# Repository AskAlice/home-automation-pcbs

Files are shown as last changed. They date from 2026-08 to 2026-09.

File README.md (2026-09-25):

# home-automation-pcbs

Open-hardware IoT boards for home automation, designed for **ESPHome** and/or
**Matter-over-Thread / Zigbee** (ESP32-C3/C6/S3/H2 based). All projects are
native **KiCad 8** and fully self-contained (project-local symbol libraries,
inline custom footprints, generator scripts — every file is reproducible).

> ⚠ **Verify before fabrication.** Footprints for ESP modules and sensors are
> drawn from published datasheets but these boards have not been through a
> physical run. v0.1 boards have signal routing left for autorouting
> (documented per-board). Check each board README before ordering PCBs.
> **RelayMini contains mains voltage — read its safety section first.**

## Boards

| Board | MCU | Ecosystem | Function | Status |
|---|---|---|---|---|
| [`boards/sensenode-c6`](boards/sensenode-c6) | ESP32-C6-WROOM-1 | ESPHome (Wi-Fi) + Matter/Thread | Temp/hum, lux, pressure, PIR | v0.1 routed (power), partial ratsnest |
| [`boards/presencepro-c3`](boards/presencepro-c3) | ESP32-C3-WROOM-02 | ESPHome | HLK-LD2410 mmWave presence + lux | v0.1 |
| [`boards/ledquad-c3`](boards/ledquad-c3) | ESP32-C3-WROOM-02 | ESPHome / WLED | 4-ch 12–24 V PWM LED driver | v0.1 |
| [`boards/relaymini-c3`](boards/relaymini-c3) | ESP32-C3-WROOM-02 | ESPHome | ⚠ Mains switch + BL0942 metering | v0.1, safety gates green |
| [`boards/ledhub-c6`](boards/ledhub-c6) | ESP32-C6-WROOM-1 | WLED / ESPHome | 2.8" TFT all-in-one LED controller | v0.1 (flagship) |
| [`boards/threadnode-h2`](boards/threadnode-h2) | ESP32-H2-MINI-1 | Matter-over-Thread / Zigbee | Battery contact sensor / button | v0.1 concept |
| [`boards/airquality-s3`](boards/airquality-s3) | ESP32-S3-WROOM-1 | ESPHome | CO₂ + VOC + temp/hum + OLED header | v0.1 concept |
| [`boards/blinddriver-c6`](boards/blinddriver-c6) | ESP32-C6-WROOM-1 | ESPHome / Matter | TMC2209 roller-blind controller | v0.1 concept |
| [`boards/irblaster-c3`](boards/irblaster-c3) | ESP32-C3-WROOM-02 | ESPHome | IR TX/RX climate bridge | v0.1 concept |
| [`boards/gardenprobe-c6`](boards/gardenprobe-c6) | ESP32-C6-WROOM-1 | ESPHome / Matter | Battery soil-moisture probe | v0.1 concept |
| [`boards/threadrcp-h2`](boards/threadrcp-h2) | ESP32-H2-MINI-1 | OpenThread RCP / Zigbee NCP | Border-router USB dongle | v0.1 concept |
| [`boards/garagepilot-c6`](boards/garagepilot-c6) | ESP32-C6-WROOM-1 | ESPHome | Garage-door relay + 3× inputs | v0.1 routed, DRC/ERC issues |

Each board folder contains: `*.kicad_pro/.kicad_sch/.kicad_pcb`, project-local
symbol library, `bom_lcsc.csv` (real, in-stock LCSC part numbers), `README.md`
(BOM, pinout, flashing, analyzer notes), `esphome/*.yaml`, render PNGs, and the
generator script (`gen_*.py`).

## Board showcase

### 🌡️ [SenseNode C6](boards/sensenode-c6) — environmental multisensor

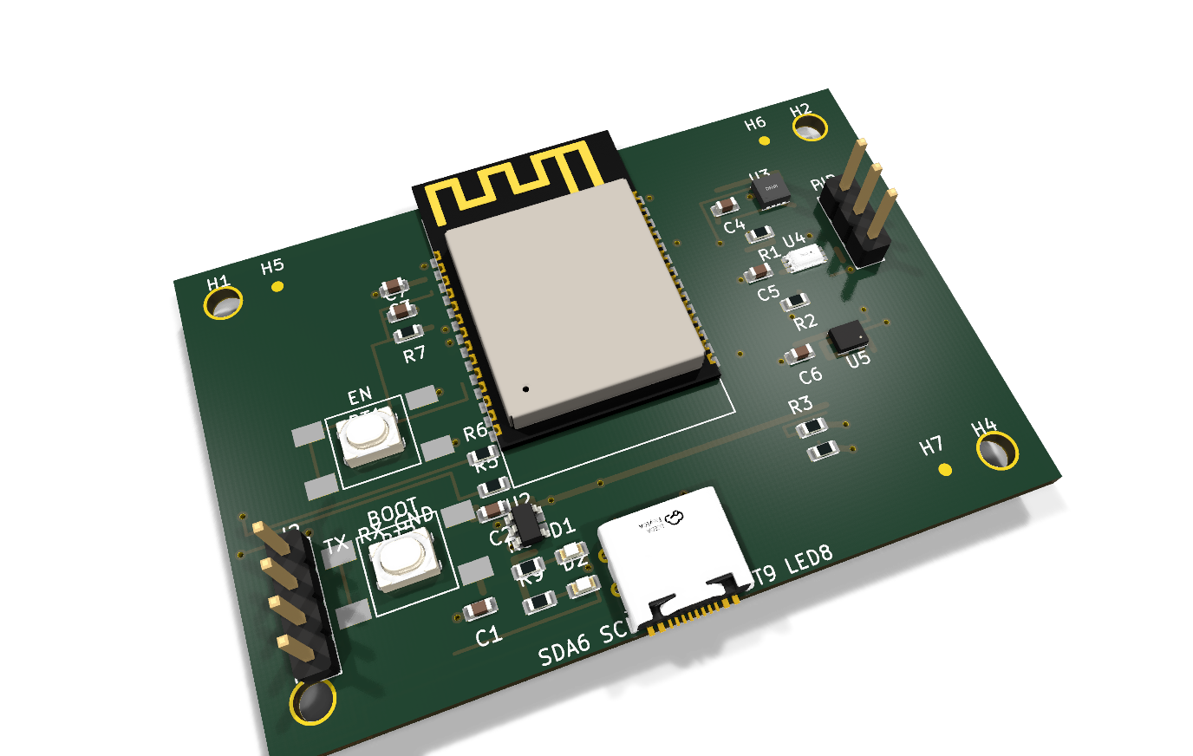
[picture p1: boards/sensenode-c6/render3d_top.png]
SenseNode C6


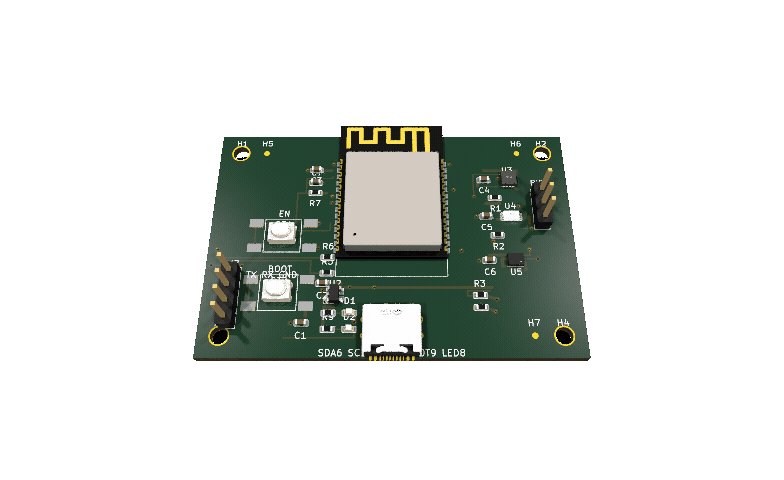
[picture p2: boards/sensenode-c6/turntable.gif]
sensenode-c6 360° turntable


One-per-room environmental node. ESP32-C6 gives you Wi-Fi 6 + BLE5 **and**
802.15.4, so the same SKU can run ESPHome today and Matter-over-Thread tomorrow.

- **Sensors:** SHT31 (temp/hum), BH1750 (lux), BMP280 (pressure), AM312 PIR (motion)
- **Power:** USB-C 5 V → AP2112K-3.3 LDO; EN/BOOT buttons; 1×4 prog header
- **Key parts:** ESP32-C6-WROOM-1, SHT31-AD1B, BH1750FVI, BMP280, AP2112K-3.3, USB-C 16P
- **Firmware:** `boards/sensenode-c6/esphome/sensenode-c6.yaml` (+ esp-matter note)

| Function | ESP32-C6 GPIO |
|---|---|
| I2C SDA / SCL (SHT31 + BH1750 + BMP280) | 6 / 7 |
| PIR OUT (J1) | 4 |
| Status LED (active low) | 8 |
| BOOT button | 9 |
| USB D− / D+ | 12 / 13 |
| UART0 TX0 / RX0 (prog header) | 16 / 17 |
| EN reset | EN |

---

### 🚶 [PresencePro C3](boards/presencepro-c3) — mmWave presence + lux

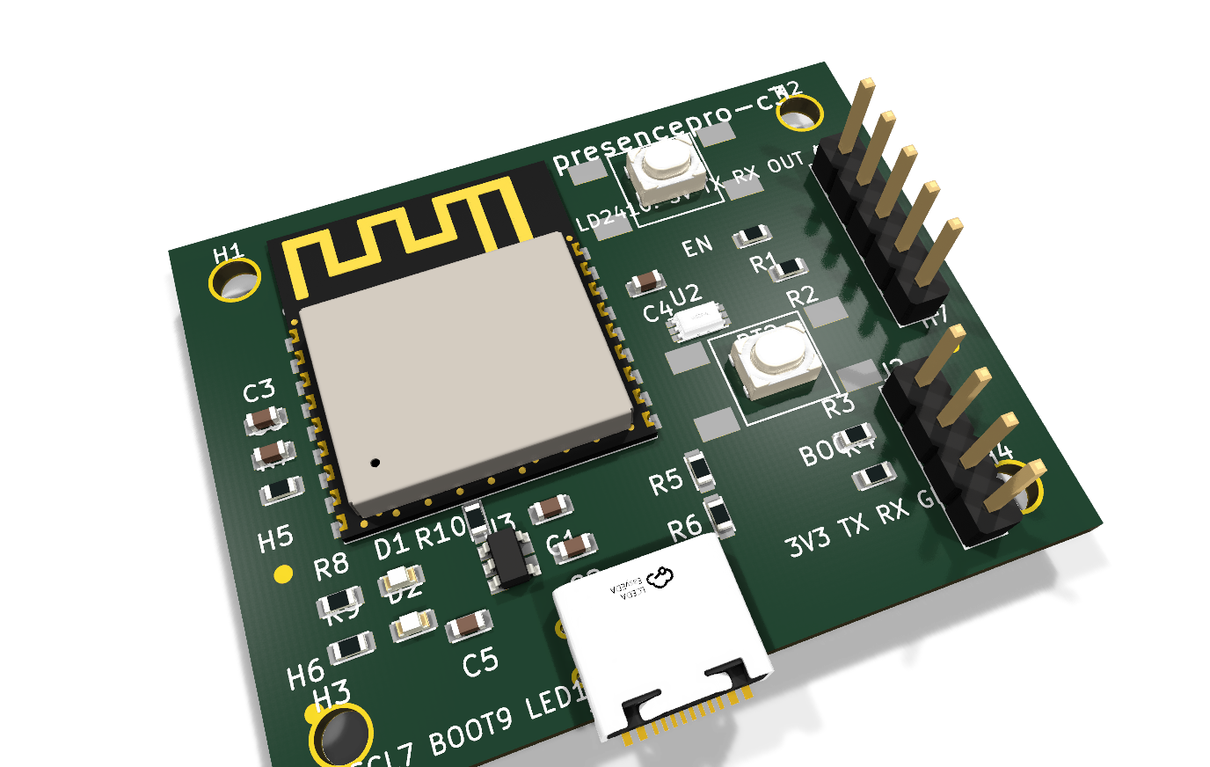
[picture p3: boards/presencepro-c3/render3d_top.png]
PresencePro C3


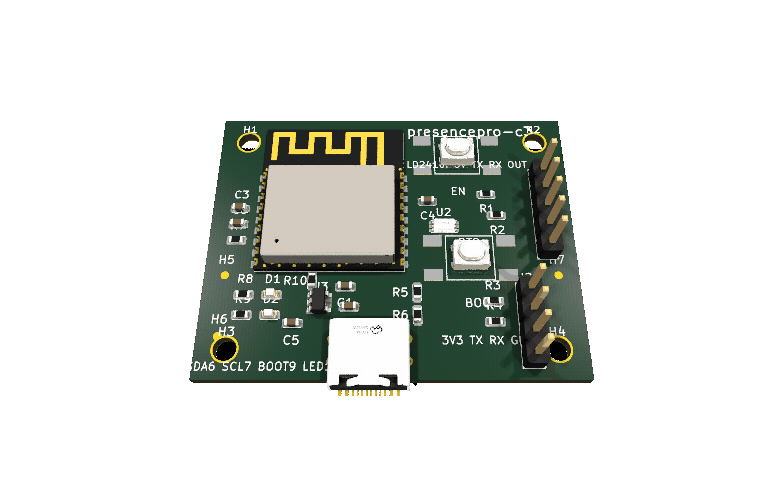
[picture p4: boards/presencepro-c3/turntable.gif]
presencepro-c3 360° turntable


True still-presence detection (sitting at a desk, sleeping) where PIR fails,
with lux gating so automations only fire when it's dark.

- **Sensors:** HLK-LD2410(B) 24 GHz mmWave (moving + static targets, configurable
  gates), BH1750 ambient light
- **Power:** USB-C 5 V → AP2112K-3.3; native USB flashing
- **Key parts:** ESP32-C3-WROOM-02, HLK-LD2410B (module on 1×5 header), BH1750FVI, AP2112K
- **Firmware:** `esphome/presencepro-c3.yaml` (native `ld2410` component)

| Function | ESP32-C3 GPIO |
|---|---|
| Radar UART RX / TX | 4 / 5 |
| Radar OUT (occupancy) | 3 |
| I2C SDA / SCL (BH1750) | 6 / 7 |
| USB D− / D+ | 18 / 19 |
| Status LED | 10 |
| BOOT / EN | 9 / EN |
| UART0 RX0 / TX0 (prog) | 20 / 21 |

---

### 💡 [LEDQuad C3](boards/ledquad-c3) — 4-ch 12–24 V PWM LED driver

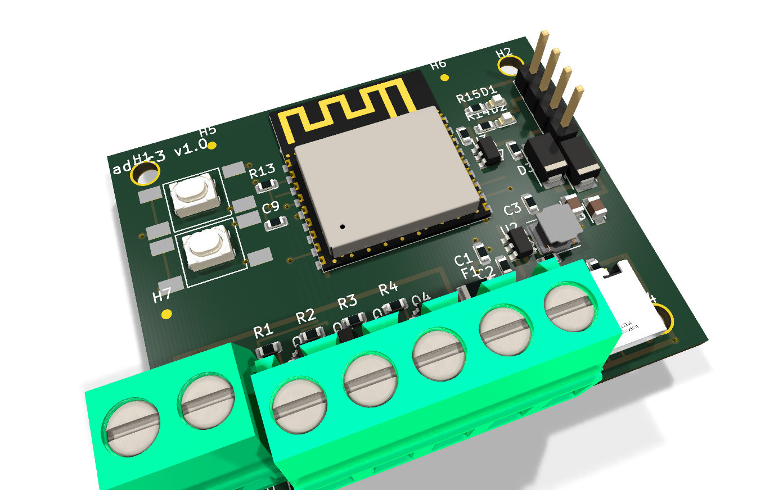
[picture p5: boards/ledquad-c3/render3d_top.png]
LEDQuad C3


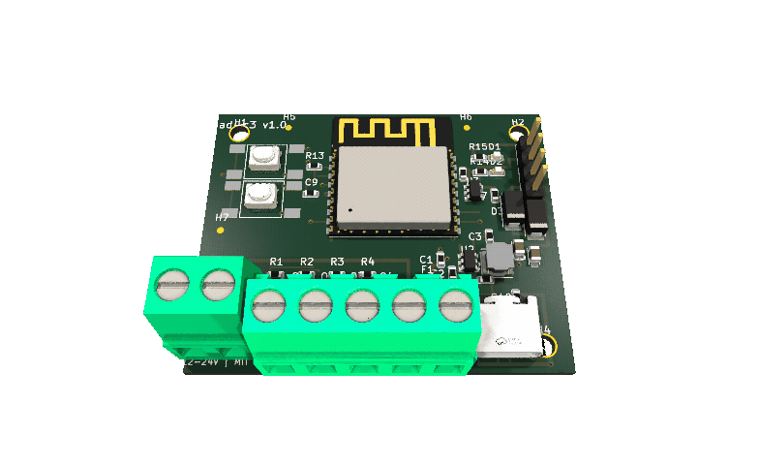
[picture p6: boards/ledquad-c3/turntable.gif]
ledquad-c3 360° turntable


Analog RGBW strip driver for 12/24 V strips — the classic ESPHome `light.rgbw`
board, sized to hide behind furniture.

- **Outputs:** 4× AO3400A N-MOSFET low-side channels on 5.08 mm screw terminals
- **Power:** 12–24 V in (fused) → AP63205 buck 5 V/2 A → AP2112 3.3 V; USB-C
  programming diode-OR'd with the buck rail
- **Key parts:** ESP32-C3-WROOM-02, AP63205, AP2112K-3.3, 4× AO3400A, SS34, USB-C 16P
- **Firmware:** `esphome/ledquad-c3.yaml` (also WLED-friendly)

| Function | ESP32-C3 GPIO |
|---|---|
| PWM R / G / B / W | 4 / 5 / 6 / 7 |
| Status LED | 10 |
| BOOT button | 9 |
| USB D− / D+ | 18 / 19 |
| UART0 TX0 / RX0 | 21 / 20 |
| EN reset | EN |

---

### 🔌 [RelayMini C3](boards/relaymini-c3) — mains switch + energy metering

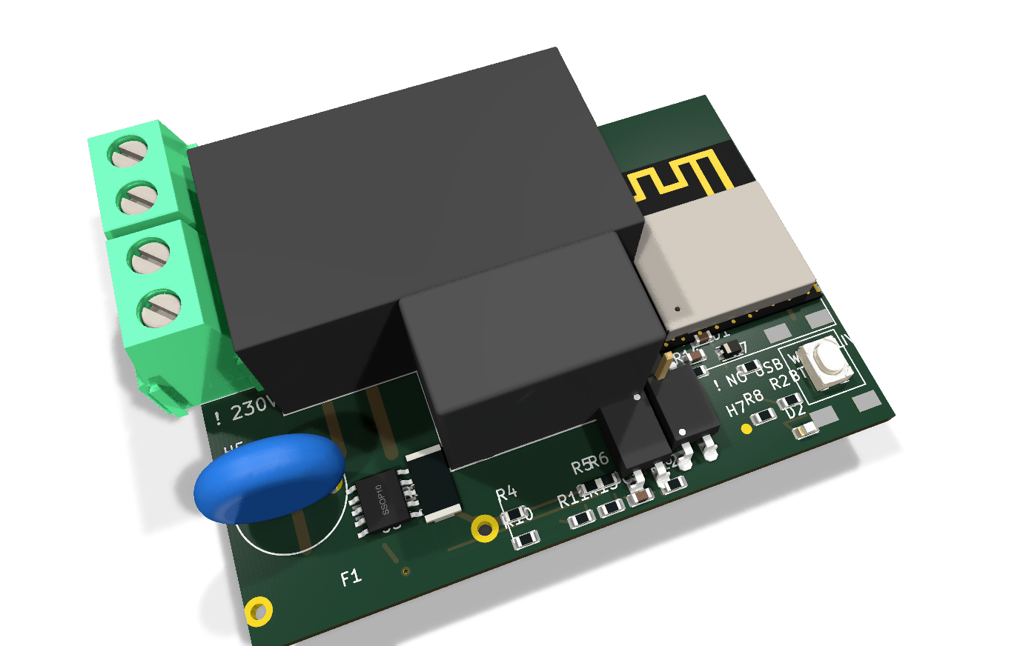
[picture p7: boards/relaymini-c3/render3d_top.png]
RelayMini C3


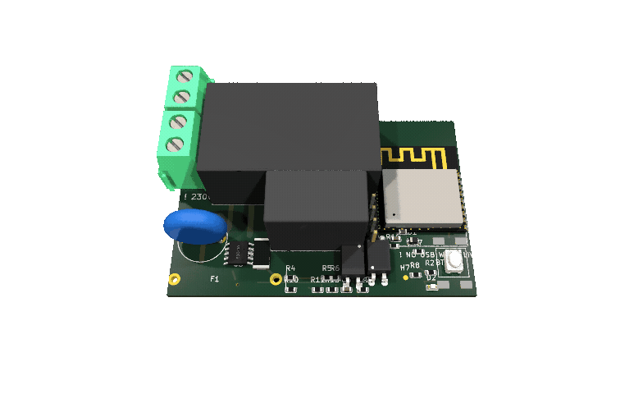
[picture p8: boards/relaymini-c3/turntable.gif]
relaymini-c3 360° turntable


> ⚠ **110–240 VAC mains board. Lethal voltages. Qualified builders only —
> read the safety section in its README before anything else.**

Sonoff-Basic-class inline switch, but with proper engineering: fused input,
isolation slot, opto-isolated metering, and a SELV-side programming header.

- **Switching:** HF32F-G relay 10 A/250 VAC, 10 A fuse, MOV, creepage ≥ 6 mm,
  milled isolation slot between mains and SELV domains
- **Metering:** BL0942 (V/A/W/Wh/PF) with PC817 opto-isolated UART
- **Key parts:** ESP32-C3-WROOM-02, HLK-PM01 AC/DC, HF32F-G, BL0942, PC817 ×2
- **Firmware:** `esphome/relaymini-c3.yaml` (`bl0942` component)

| Function | GPIO |
|---|---|
| Relay driver (→ K1 coil) | GPIO6 |
| BL0942 UART RX / TX | GPIO4 / GPIO5 |
| User button (active low) | GPIO9 |
| Status LED (active low) | GPIO8 |
| Prog header (SELV side only!) TX0/RX0 | GPIO21 / GPIO20 |

---

### 🕹️ [LEDHub C6](boards/ledhub-c6) — all-in-one display LED controller (flagship)

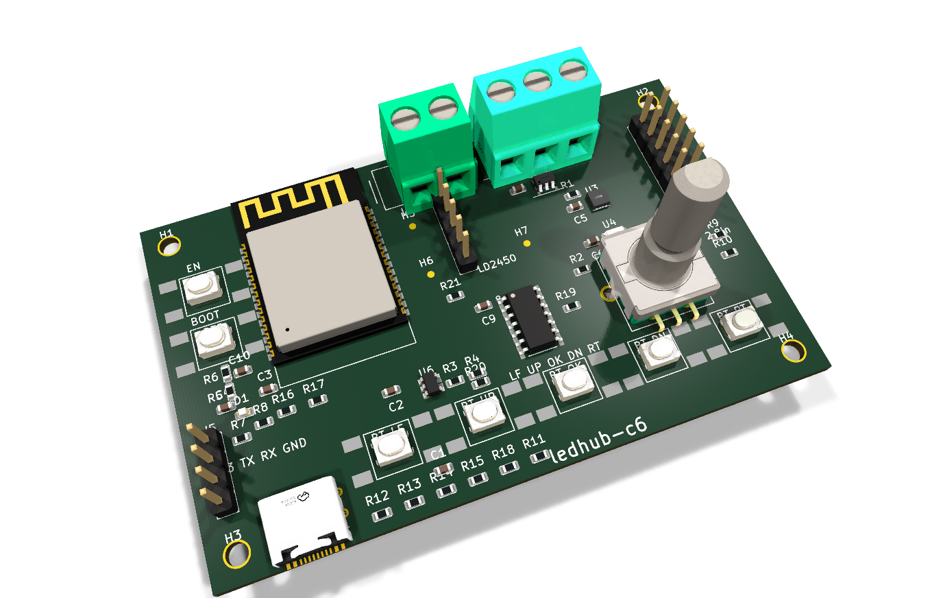
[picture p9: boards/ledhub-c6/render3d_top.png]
LEDHub C6


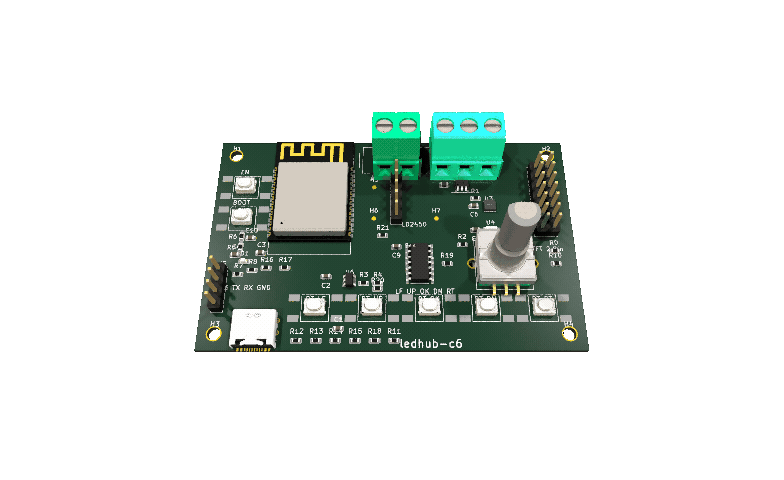
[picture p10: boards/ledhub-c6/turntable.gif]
ledhub-c6 360° turntable


A complete addressable-LED control station: status display, physical controls,
presence-aware switching and environmental telemetry, running **WLED** with a
custom usermod (`firmware/wled-usermod-ledhub`).

- **Display/UI:** 2.8" ILI9341 TFT (effect, palette, brightness, IP, RSSI),
  EC11 rotary encoder, 5-way nav buttons on one ADC pin (resistor ladder)
- **Sensors:** SHT31 + BH1750 (I2C), INMP441 I2S mic, LD2450 mmWave radar header
- **Output:** WS2812 data via 74AHCT125 level shifter + 470 Ω; separate 5 V LED
  power terminal
- **Key parts:** ESP32-C6-WROOM-1, 74AHCT125, INMP441, SHT31, BH1750, EC11, AP2112K
- **Firmware:** WLED usermod + `esphome/ledhub-c6.yaml`

| Function | ESP32-C6 GPIO |
|---|---|
| TFT SCK / MOSI / CS / DC / RST / BL | 6 / 7 / 5 / 4 / 1 / 2 |
| Encoder A / B | 15 / 16 |
| Nav button ladder (ADC) | 0 |
| INMP441 I2S SCK / WS / SD | 17 / 18 / 19 |
| I2C SDA / SCL | 20 / 21 |
| LD2450 radar RX / TX | 22 / 23 |
| WS2812 data (→ 74AHCT125) | 3 |
| USB D− / D+ | 12 / 13 |

---

### 🚪 [ThreadNode H2](boards/threadnode-h2) — battery Thread contact/button node

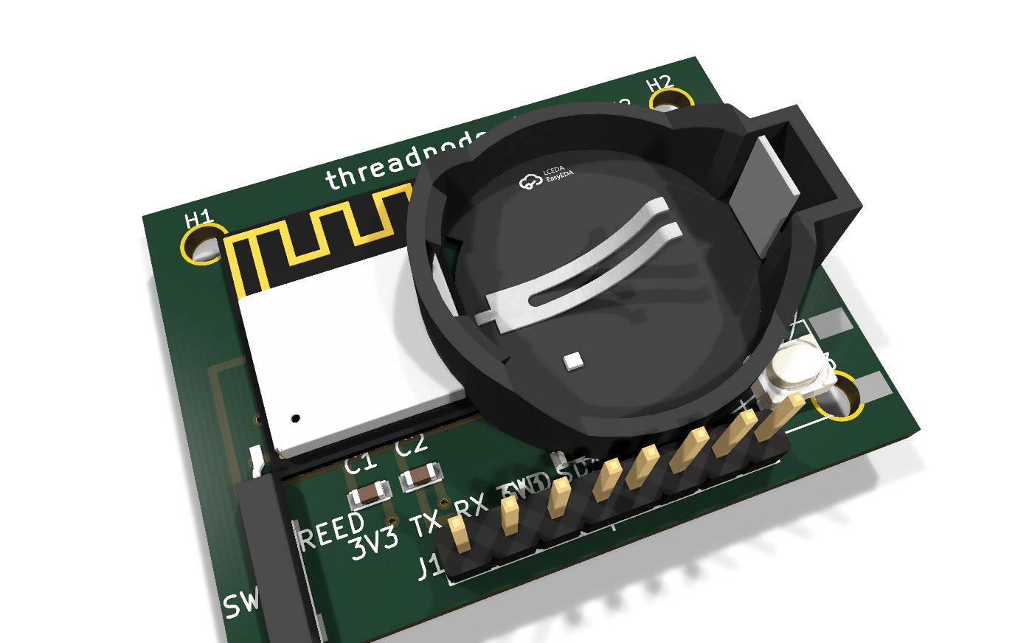
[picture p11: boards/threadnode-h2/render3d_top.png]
ThreadNode H2


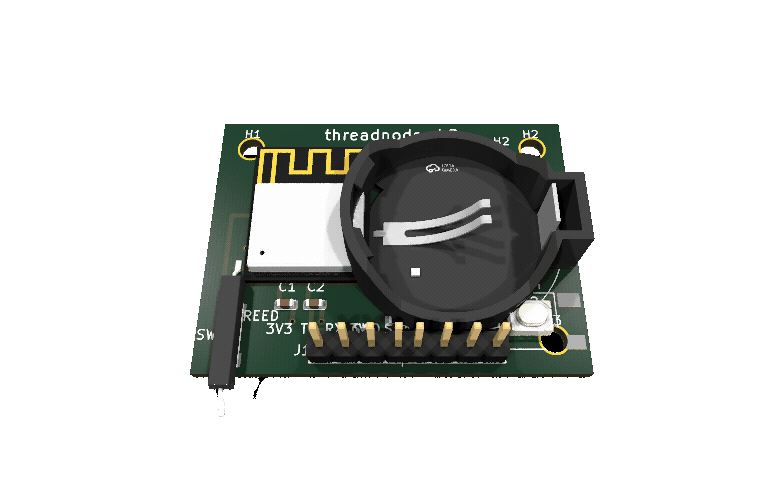
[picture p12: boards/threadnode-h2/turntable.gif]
threadnode-h2 360° turntable


ESP32-H2 = 802.15.4 only, built for deep sleep: a CR2032 door/window sensor or
smart button on a Matter-over-Thread or Zigbee network.

- **Power:** CR2032 direct (no LDO — brown-out note in README); reed-switch
  deep-sleep wakeup
- **Key parts:** ESP32-H2-MINI-1, CR2032 holder, reed/header input, 4.7k I2C pull-ups
- **Firmware:** Matter-over-Thread via esp-matter (note in README)

| Signal | GPIO | Notes |
|---|---|---|
| REED | GPIO3 | reed switch to GND, deep-sleep wakeup |
| I2C SDA / SCL | GPIO12 / GPIO13 | expansion header |
| STAT LED | GPIO8 | pulse only — battery |
| BTN (BOOT) | GPIO9 | user button / ROM bootloader |
| TX0 / RX0 | GPIO24 / GPIO23 | prog header (no USB) |

---

### 🌫️ [AirQuality S3](boards/airquality-s3) — CO₂ / VOC / temp / humidity

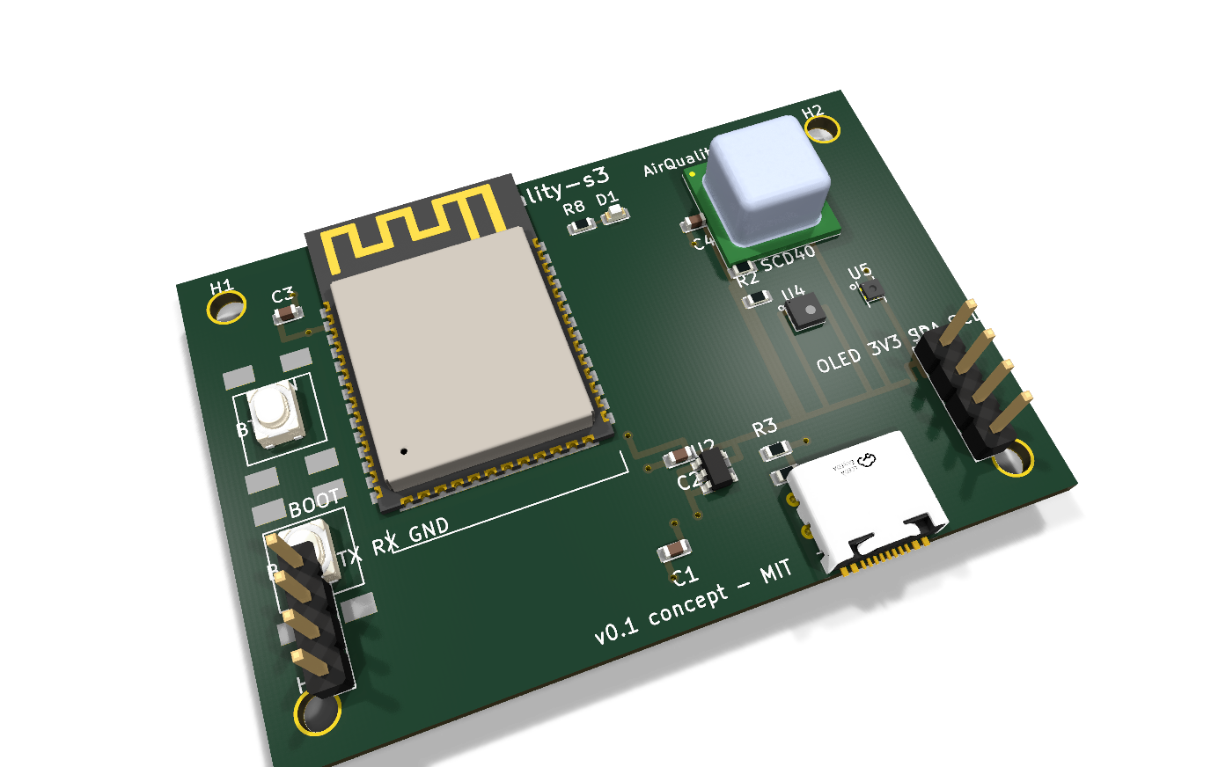
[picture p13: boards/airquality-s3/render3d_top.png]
AirQuality S3


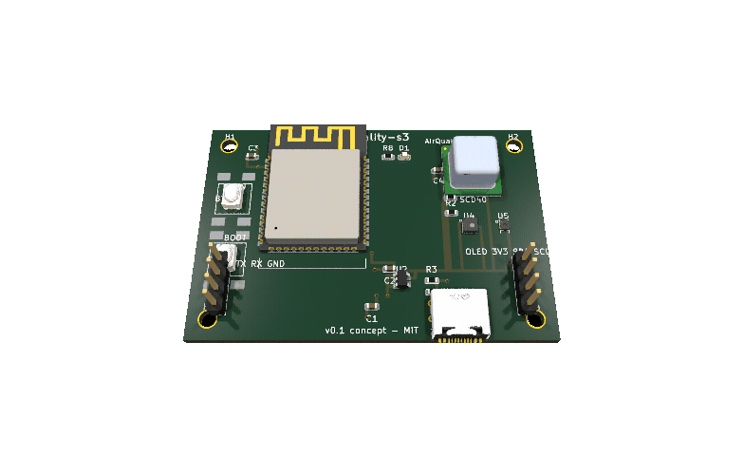
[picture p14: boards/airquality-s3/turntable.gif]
airquality-s3 360° turntable


Full indoor-air-quality node with photoacoustic CO₂ and metal-oxide VOC on one
I2C bus, plus a header for a 0.96" SSD1306 OLED readout.

- **Sensors:** Sensirion SCD40 (CO₂), SGP40 (VOC index), SHT40 (temp/hum)
- **Key parts:** ESP32-S3-WROOM-1, SCD40, SGP40, SHT40, AP2112K-3.3, USB-C
- **Firmware:** `esphome/airquality-s3.yaml` (`scd4x`, `sgp40`, `sht4x`)

| Signal | GPIO | Notes |
|---|---|---|
| I2C SDA / SCL | GPIO8 / GPIO9 | SCD40 0x62, SGP40 0x59, SHT40 0x44, OLED 0x3C |
| BOOT / RST | GPIO0 / EN | |
| STAT LED | GPIO38 | |
| USB D− / D+ | GPIO19 / GPIO20 | native USB flashing |
| TX0 / RX0 | GPIO43 / GPIO44 | spare UART |

---

### 🪟 [BlindDriver C6](boards/blinddriver-c6) — TMC2209 roller-blind controller

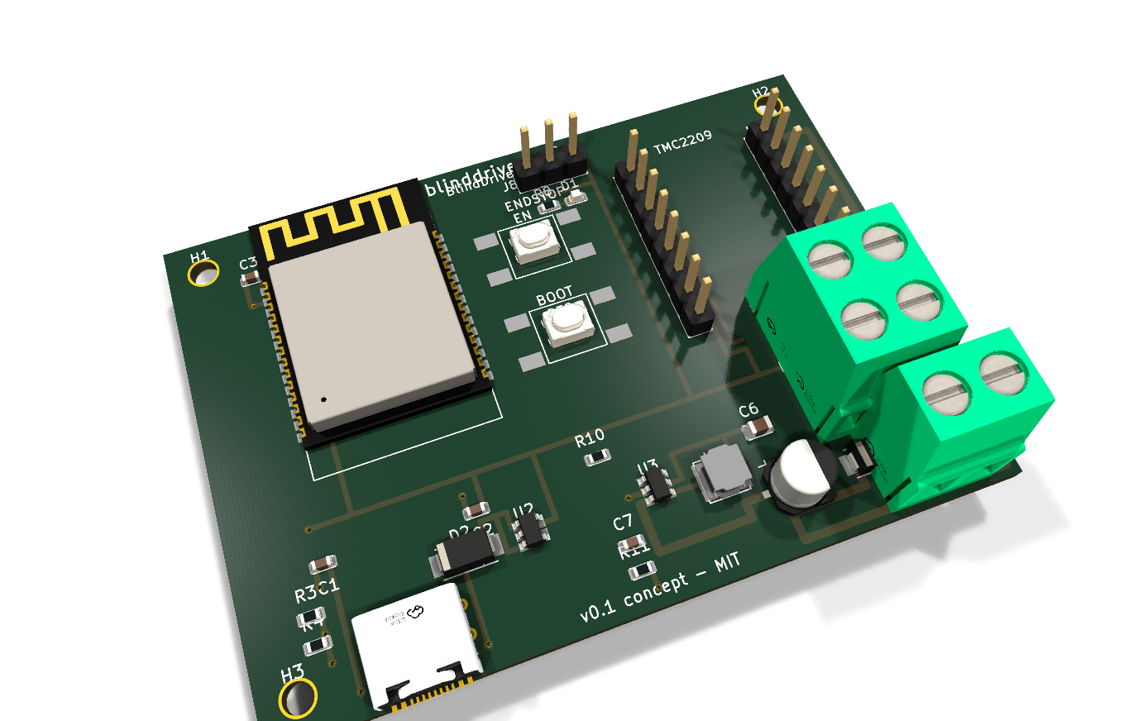
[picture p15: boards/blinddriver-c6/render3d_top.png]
BlindDriver C6


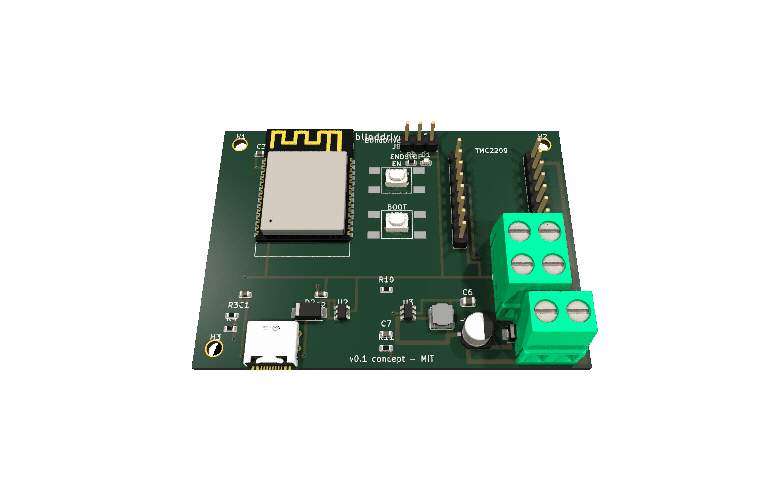
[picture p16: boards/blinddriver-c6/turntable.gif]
blinddriver-c6 360° turntable


Quiet Trinamic stepper control for roller blinds, with ESPHome `cover`
semantics and Wi-Fi 6 + Thread on tap.

- **Driver:** TMC2209 socket (STEP/DIR/EN/DIAG + 1-wire UART config),
  end-stop header, 12 V VMOT with SS34 reverse-polarity protection
- **Power chain:** 12 V → AP63205 5 V → AP2112 3.3 V
- **Key parts:** ESP32-C6-WROOM-1, TMC2209, AP63205, screw terminals
- **Firmware:** `esphome/blinddriver-c6.yaml` (stepper cover)

| Signal | GPIO | Notes |
|---|---|---|
| STEP / DIR | GPIO4 / GPIO5 | TMC2209 socket |
| TMC_EN / DIAG | GPIO6 / GPIO7 | |
| TMC_UART | GPIO15 | 1-wire PDN_UART config |
| ENDSTOP | GPIO18 | header, pull-up |
| USB D− / D+ | GPIO12 / GPIO13 | |

---

### 📡 [IRBlaster C3](boards/irblaster-c3) — IR climate bridge

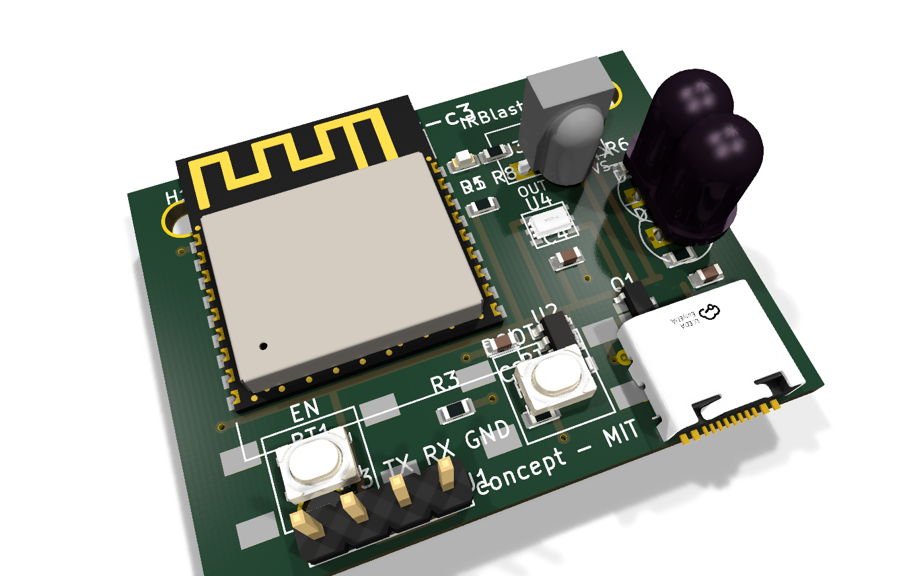
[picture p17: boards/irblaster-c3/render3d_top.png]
IRBlaster C3


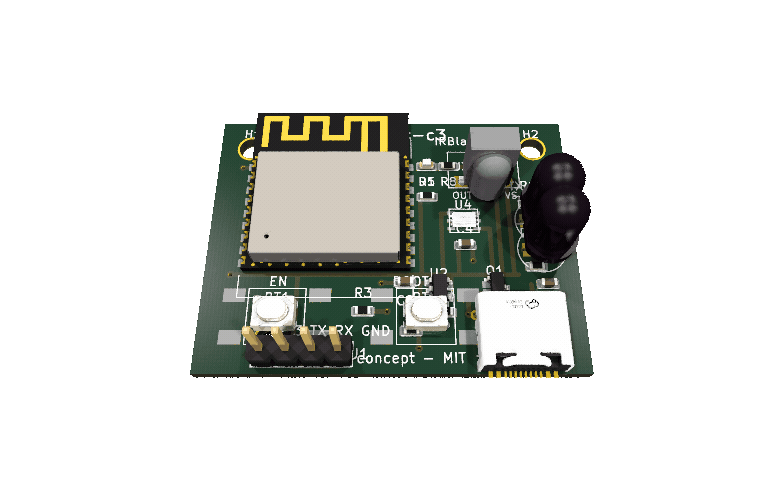
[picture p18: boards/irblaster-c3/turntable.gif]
irblaster-c3 360° turntable


Give any dumb IR AC/heater a brain: ESPHome `climate_ir` with transmit and
receive (learn your remote's codes).

- **TX:** 2× TSAL6200 high-power IR LEDs driven by S8050 (GPIO4)
- **RX:** TSOP38238 38 kHz receiver (GPIO5); optional BH1750 lux on I2C
- **Key parts:** ESP32-C3-WROOM-02, TSAL6200 ×2, TSOP38238, S8050, BH1750
- **Firmware:** `esphome/irblaster-c3.yaml` (`remote_transmitter`/`remote_receiver`)

| Signal | GPIO | Notes |
|---|---|---|
| IR_TX | GPIO4 | → S8050 → 2× TSAL6200 |
| IR_RX | GPIO5 | TSOP38238 out |
| I2C SDA / SCL | GPIO6 / GPIO7 | BH1750 0x23 |
| STAT LED / BOOT | GPIO10 / GPIO9 | |
| USB D− / D+ | GPIO18 / GPIO19 | |

---

### 🌱 [GardenProbe C6](boards/gardenprobe-c6) — battery soil-moisture stick

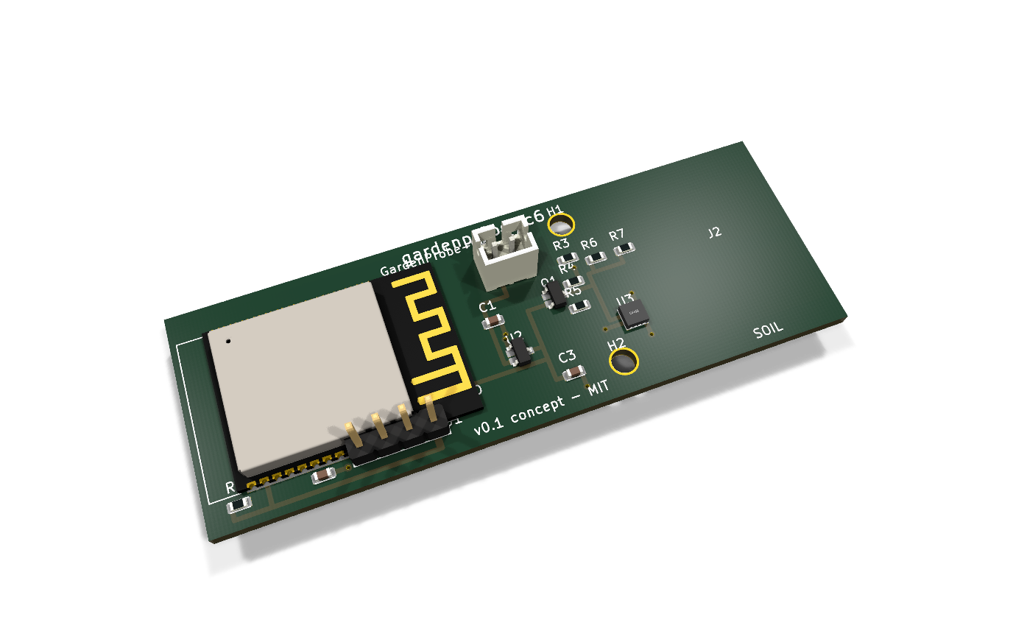
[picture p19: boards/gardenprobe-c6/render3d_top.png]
GardenProbe C6


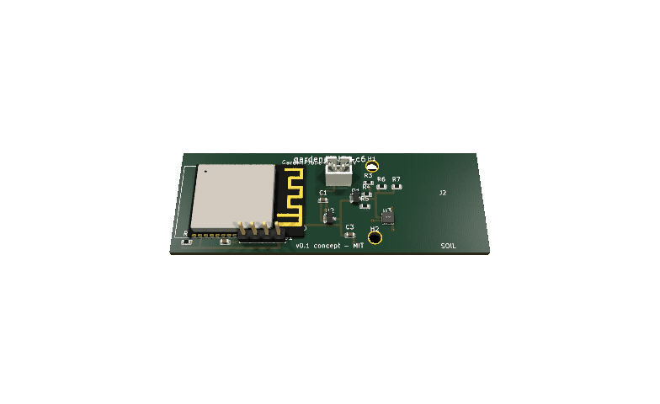
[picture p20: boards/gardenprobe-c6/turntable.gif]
gardenprobe-c6 360° turntable


Plant sensor built as a 70 × 25 mm stick: the probe is the PCB — a capacitive
copper area on the bottom tip, corrosion-free versus resistive probes.

- **Sensing:** capacitive fixed-RC probe (GPIO0/1), SHT31 on a load-switched
  rail (AO3401) to save battery, 100k/100k battery divider
- **Power:** 3.7 V LiPo on JST-PH, MCP1700-3302 LDO (charge externally)
- **Key parts:** ESP32-C6-WROOM-1, MCP1700, AO3401, SHT31
- **Firmware:** `esphome/gardenprobe-c6.yaml` (deep sleep)

| Signal | GPIO | Notes |
|---|---|---|
| SOIL_ADC / SOIL_CHG | GPIO0 / GPIO1 | capacitive probe |
| BATT_ADC | GPIO2 | Vbat/2 divider |
| LOAD_EN | GPIO3 | sensor rail load switch |
| I2C SDA / SCL | GPIO20 / GPIO21 | SHT31 0x44 |
| TX0 / RX0 | GPIO16 / GPIO17 | prog header (no USB) |

---

### 🧵 [ThreadRCP H2](boards/threadrcp-h2) — OpenThread border-router dongle

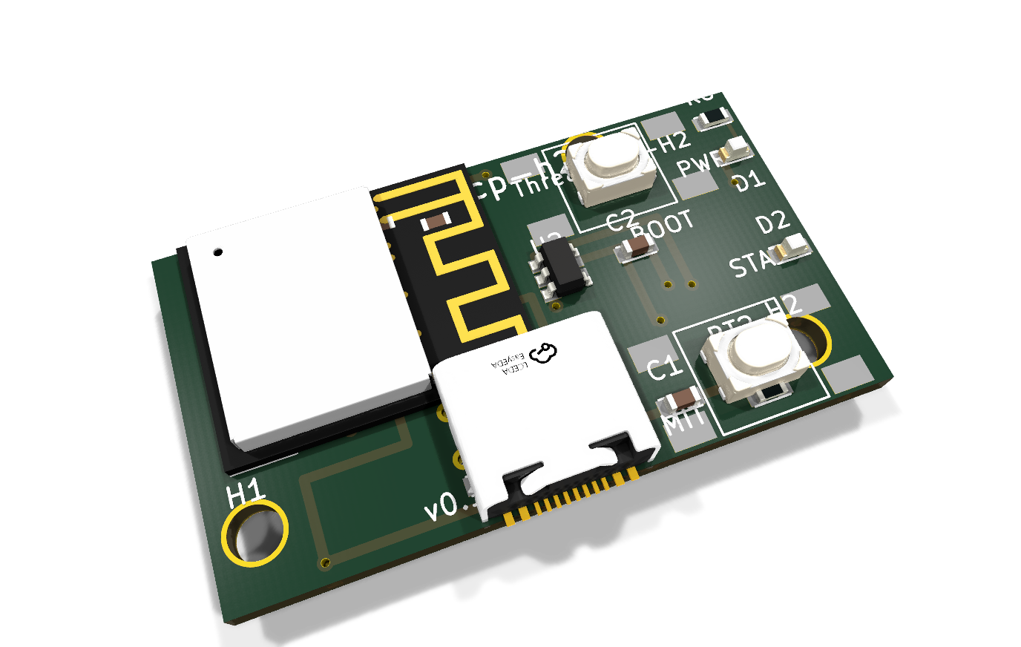
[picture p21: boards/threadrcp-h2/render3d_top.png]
ThreadRCP H2


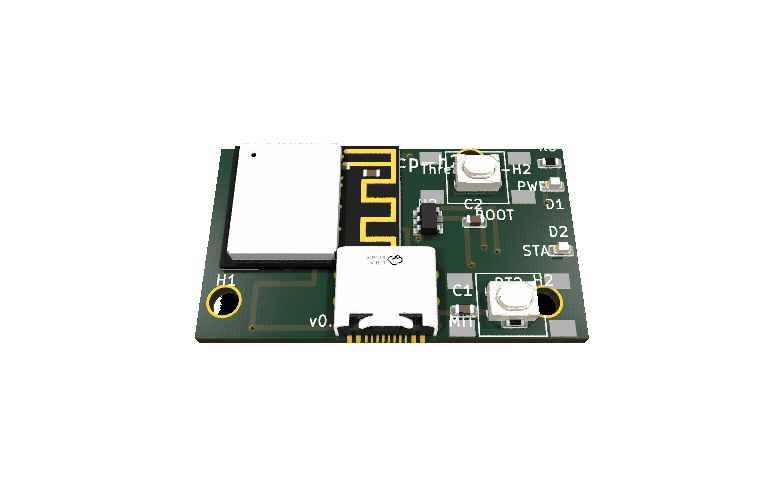
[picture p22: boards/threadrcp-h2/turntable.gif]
threadrcp-h2 360° turntable


35 × 20 mm USB-C dongle that turns a Home Assistant box into an OpenThread
Border Router — the missing piece for all the H2/C6 Thread boards above.

- **Function:** ESP32-H2 RCP firmware (`esp_ot_br` / ot-rcp), native USB
  transport (GPIO26/27) — no UART bridge chip
- **Layout:** module rotated so the antenna overhangs the board edge
  (metal-free keep-out marked on silk)
- **Key parts:** ESP32-H2-MINI-1, USB-C 16P, AP2112K-3.3
- **Firmware:** Espressif ot_rcp example (flash command in README)

| Signal | GPIO | Notes |
|---|---|---|
| USB D− / D+ | GPIO26 / GPIO27 | RCP transport |
| STAT LED | GPIO8 | |
| BOOT / RST | GPIO9 / EN | |
| TX0 / RX0 | GPIO24 / GPIO23 | spare pads only |

### 🚗 [GaragePilot C6](boards/garagepilot-c6) — garage-door relay + 3× inputs

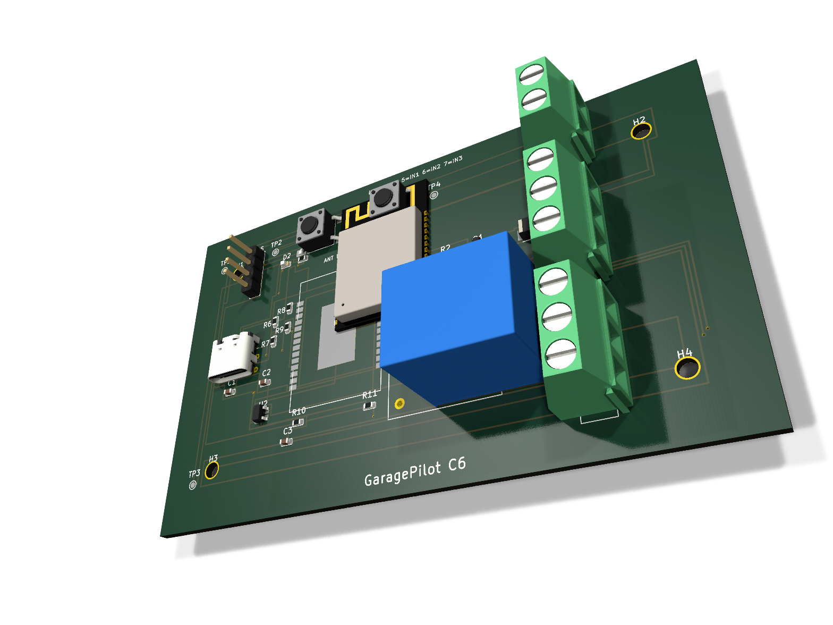
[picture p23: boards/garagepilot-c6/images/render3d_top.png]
GaragePilot C6


Dry-contact garage-door controller: ESP32-C6 closes a low-voltage relay across the opener's
wall-button terminals and reads door-closed / door-open reed switches plus a safety beam.
Powered from USB-C or a 5 V screw terminal.

- **Relay:** SRD-05VDC-SL-C SPDT dry contact (COM/NC/NO) via AO3400A MOSFET
- **Inputs:** 3× active-low digital inputs with 10 kΩ pull-ups for reed / safety sensors
- **Power:** USB-C 16P → AP2112K-3.3 LDO; auxiliary 5 V terminal
- **Key parts:** ESP32-C6-WROOM-1-N8, AP2112K-3.3, AO3400A, SRD-05VDC-SL-C, SS34 flyback
- **Firmware:** `boards/garagepilot-c6/esphome/garagepilot-c6.yaml` (`cover` template)

> ⚠ **v0.1 status:** routed and rendered, but KiCad DRC reports 96 violations / 23 unconnected
> items and ERC could not be run from the CLI.  See the board README before ordering PCBs.

| Function | ESP32-C6 GPIO |
|---|---|---|
| Relay driver | 4 |
| Door-closed / door-open / safety beam inputs | 5 / 6 / 7 |
| Status LED | 8 |
| BOOT / RESET buttons | 9 / EN |
| UART0 TX0 / RX0 (prog header) | 16 / 17 |

---

## Firmware

- `boards/*/esphome/*.yaml` — ready-to-adapt ESPHome configs.
- [`firmware/wled-usermod-ledhub`](firmware/wled-usermod-ledhub) — WLED usermod
  for LEDHub: ILI9341 status display, rotary encoder brightness, ADC-ladder
  nav buttons, LD2450 presence switching, SHT31/BH1750 telemetry.

## Part data

- [`datasheets/`](datasheets) — datasheet PDFs for all ICs/modules/connectors
  + `manifest.json` (re-sync: `python3 tools/fetch_datasheets.py`).
- [`3dmodels/`](3dmodels) — STEP + WRL models (KiCad packages3D, Espressif
  kicad-libraries, EasyEDA/LCSC) referenced from every PCB
  (`${KIPRJMOD}/../../3dmodels/…`) + `manifest.json` (the resolved model and
  transform per footprint; re-fetch + re-attach: `python3 tools/attach_3d.py`).

> **Note:** datasheet PDFs and STEP/WRL models are not committed to git — they
> are regenerable with `tools/fetch_datasheets.py` and `tools/attach_3d.py`.
> The render PNGs/GIFs in each board folder *are* committed so the READMEs
> display without any tooling.

## Tools

- `tools/kicadgen.py` — KiCad 8 s-expression writer + project validator used
  by every board generator (`python3 boards/<b>/gen_<b>.py` regenerates).
- `tools/render_pcb.py` — dependency-free PCB rasterizer (the render PNGs in
  each board folder).
- `tools/attach_3d.py` — fetches every footprint's 3D model (declarative
  footprint → source table) and rebuilds the `(model …)` blocks in all boards,
  aligning each body to the repo's custom footprint by pad bounding box.
  Needs `easyeda2kicad` (pip) for the LCSC parts.
- `tools/render3d.sh` — raytraced 3D renders (`render3d_top/bottom.png` per
  board) via `kicad-cli pcb render --quality high` (KiCad ≥ 9.0, 10.0.5
  known-good — CPU raytracer, no X server needed).
- `tools/turntable.sh` — 24-frame 360° orbit (`turntable.gif` per board) from
  the same raytracer, stitched with ffmpeg.

## Design rules

2-layer, 1.6 mm, 0.2 mm clearance, 0.25 mm min track, ≥0.5 mm power tracks,
GND pour on B.Cu, antenna keepouts on all RF modules. Every board passes
[kicad-happy](https://github.com/aklofas/kicad-happy) schematic/PCB analysis
with zero cross-net violations (DFM-001 = 0); remaining warnings are triaged
in each board's README.

## Acknowledgements

Validation and datasheet tooling: [kicad-happy](https://github.com/aklofas/kicad-happy)
(MIT, © 2025 Andrew Klofas). 3D models: EasyEDA/LCSC and the KiCad official
packages3D libraries. ESP module footprints verified against
[espressif/kicad-libraries](https://github.com/espressif/kicad-libraries).

## License

MIT — see [LICENSE](LICENSE).

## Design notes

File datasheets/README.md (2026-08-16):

# datasheets/

Datasheet PDFs for all non-passive parts across boards/*/bom_lcsc.csv.
Passives (R/C/LED 0603/0805) are intentionally skipped.
Files: `<LCSC>_<MPN>.pdf`. See `manifest.json` for source URL and status per part.

Fetched: 39/79. Failures/unavailable are marked in the manifest (LCSC '-' rows have no LCSC listing; fetch the manufacturer PDF manually if needed).

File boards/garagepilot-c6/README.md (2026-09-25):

# GaragePilot C6 — ESP32-C6 garage-door controller

GaragePilot C6 front isometric render

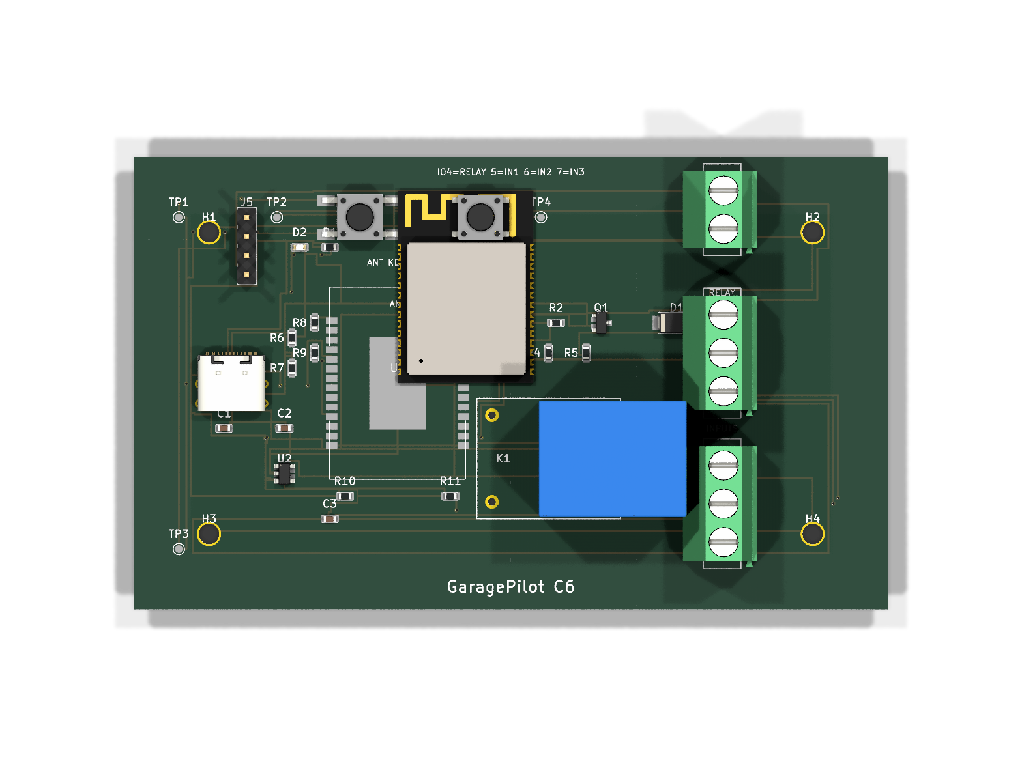
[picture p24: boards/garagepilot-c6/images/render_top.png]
GaragePilot C6 top PCB render


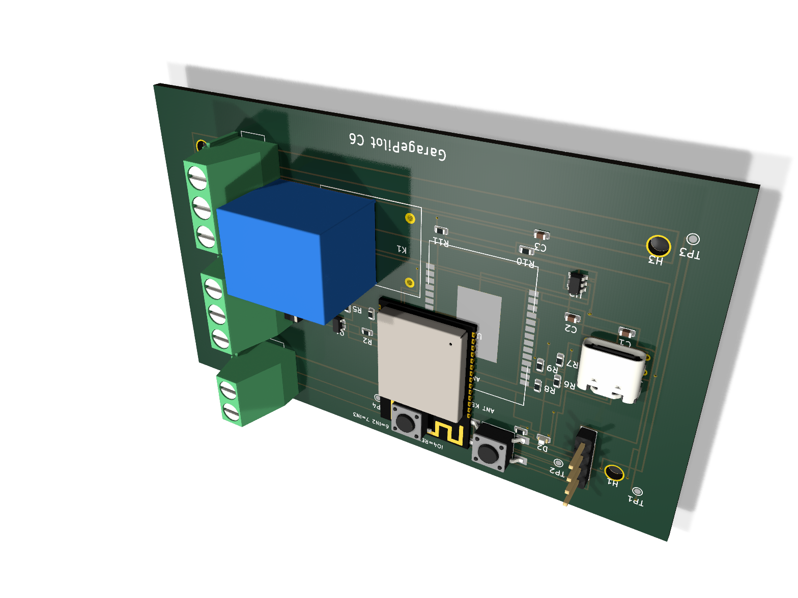
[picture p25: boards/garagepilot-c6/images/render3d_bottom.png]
GaragePilot C6 rear isometric render


A compact, low-voltage garage-door opener controller built around the **ESP32-C6-WROOM-1** module.
The board provides a single dry relay contact for the opener's momentary-button circuit,
three isolated/digital inputs for door-closed / door-open reed switches and a safety beam,
USB-C power and programming, and a 5 V auxiliary screw terminal.
It is designed for **ESPHome** (and can be adapted for Matter-over-Thread later because the
C6 includes an 802.15.4 radio).

> **Status: v0.1 prototype — not production-ready.**
> The board has been placed, autorouted, and visually inspected, but KiCad DRC still reports
> 96 clearance violations and 23 unconnected items (see Validation below).  Do not order panels
> without first resolving these.

## What it does

* Closes a **dry SPDT relay contact** across the garage-door opener's wall-button terminals
  (`COM` / `NO`) for a configurable pulse (typically 250 ms).
* Reads **three active-low digital inputs** with onboard 10 kΩ pull-ups:
  * `INPUT1` — door-closed reed / limit switch
  * `INPUT2` — door-open reed / limit switch
  * `INPUT3` — safety beam / obstruction sensor
* Powers the logic from **USB-C** or a **5 V auxiliary terminal**, regulated down to 3.3 V.
* Exposes a **1×4 2.54 mm programming header** (3.3 V, TX0, RX0, GND) and a **BOOT** + **RESET**
  tactile button pair for firmware flashing.
* Provides test points for +5 V, +3.3 V, GND, and the relay-driver signal.

## Frozen pin map

| Function | ESP32-C6 GPIO | Net / connector |
|---|---|---|
| Relay driver (active high) | IO4 | `RELAY_DRV` → Q1 → K1 coil |
| Door-closed input (pull-up, active low) | IO5 | `INPUT1` on J3 pin 1 |
| Door-open input (pull-up, active low) | IO6 | `INPUT2` on J3 pin 2 |
| Safety beam input (pull-up, active low) | IO7 | `INPUT3` on J3 pin 3 |
| Status LED (active high) | IO8 | D2 red LED |
| BOOT button | IO9 | SW2 (shared with ROM bootloader) |
| RESET button | EN | SW1 |
| USB D− | IO12 | J1 via 22 Ω series resistor |
| USB D+ | IO13 | J1 via 22 Ω series resistor |
| UART0 TX (prog header) | IO16 | J5 pin 2 |
| UART0 RX (prog header) | IO17 | J5 pin 3 |

## Key parts / BOM summary

Full BOM with LCSC numbers and sourcing URLs is in [`bom_lcsc.csv`](bom_lcsc.csv).

| Designator | Value / MPN | Footprint | Purpose |
|---|---|---|---|
| U1 | ESP32-C6-WROOM-1-N8 | Custom module | MCU + Wi-Fi 6 + BLE + 802.15.4 |
| U2 | AP2112K-3.3TRG1 | SOT-23-5 | 3.3 V / 600 mA LDO |
| Q1 | AO3400A | SOT-23 | Relay-coil low-side N-MOSFET |
| K1 | SRD-05VDC-SL-C | T73 / SRD | 5 V SPDT relay, 10 A contact |
| D1 | SS34 | SMA | Flyback diode for relay coil |
| D2 | LTST-C190KRKT | 0603 red LED | Status LED |
| J1 | TYPE-C-31-M-12 | USB-C 16P mid-mount | USB-C power + flashing |
| J2 | WJ500V-5.08-3P | 3P 5.08 mm screw terminal | Relay COM/NC/NO |
| J3 | WJ500V-5.08-3P | 3P 5.08 mm screw terminal | Inputs 1–3 |
| J4 | WJ500V-5.08-2P | 2P 5.08 mm screw terminal | AUX +5 V / GND |
| J5 | KH-2.54PH180-1X4P-L13.5 | 1×4 2.54 mm header | Programming / UART |
| SW1, SW2 | TS-1187A-B-A-B | 6×6 mm SMD tactile | RESET, BOOT |
| R1, R3–R5, R10–R11 | 10 kΩ 0603 | Pull-ups for LED, inputs, EN, BOOT |
| R2 | 100 Ω 0603 | Gate damping resistor for Q1 |
| R6, R7 | 4.7 kΩ 0603 | USB Type-C CC pulldowns |
| R8, R9 | 22 Ω 0603 | USB D+/D− series resistors |
| C1, C2 | 10 µF 0603 | VBUS and +3V3 bulk |
| C3 | 100 nF 0603 | +3V3 decoupling |

## Design calculations

**LDO power budget (AP2112K-3.3)**

* Maximum dropout at 600 mA: ~350 mV typical; with 5 V input the headroom is comfortable.
* Expected module load: ESP32-C6 peak TX current ≈ 400 mA at 3.3 V (from Espressif datasheet).
  The LDO is rated 600 mA and is sized with modest margin; keep USB-C / 5 V source resistance low.
* LDO power dissipation at peak: `(5 V − 3.3 V) × 0.4 A ≈ 0.68 W`.  The SOT-23-5 thermal pad is
  small, so continuous high-current TX should be thermally validated on the prototype.

**Relay coil drive**

* SRD-05VDC-SL-C coil: ≈ 70 Ω → coil current `5 V / 70 Ω ≈ 71 mA`.
* AO3400A Rds(on) at Vgs = 3.3 V: ≈ 25 mΩ typical.  MOSFET dissipation is negligible.
* Flyback diode D1 (SS34, 3 A / 40 V) provides a safe recirculation path.
* Gate resistor R2 (100 Ω) limits ringing without noticeably slowing the 250 ms pulse.

**USB-C CC detection**

* R6 / R7 = 4.7 kΩ each pull CC1 / CC2 to GND, telling a Type-C source to supply 5 V at
  default current.  These are placed near the connector.

**Input pull-ups**

* R3/R4/R5 = 10 kΩ.  With a reed switch to GND, input current is `3.3 V / 10 kΩ = 0.33 mA`.
  This is a good compromise between noise immunity and battery-friendliness if the auxiliary
  supply is modest.

## Fabrication notes

* **Layers:** 2-layer, 1.6 mm, 1 oz copper, ENIG or lead-free HASL.
* **Clearances:** design rules are 0.2 mm track/clearance, 0.6 mm via / 0.3 mm drill.
  The autorouter was configured with 0.25 mm clearance to improve yield.
* **RF keepout:** the ESP32-C6-WROOM-1 PCB antenna sits at the **bottom** of the module.
  A copper keepout zone forbids tracks, vias, pours, and copper polygons underneath it on all
  copper layers.  Do not place tall metal components or traces in this area.
* **Mounting:** four M2.5 non-plated mounting holes, inset 10 mm from board edges on a
  100 mm × 60 mm board.
* **Programming:** hold BOOT (SW2) while pressing RESET (SW1), or use the `esphome` USB
  upload workflow once the initial flash is complete.
* **5 V auxiliary terminal (J4):** provides a convenient way to power the board from an
  existing 5 V supply inside the opener enclosure.  USB-C and J4 are diode-less, so do not
  connect both at the same time unless both sources are safely OR'd externally.
* **Relay terminals (J2):** dry contact only — these carry the low-voltage momentary-button
  circuit from the opener, not mains voltage.  Verify your opener's control voltage stays
  within the relay/contact rating (10 A / 30 VDC / 125 VAC max per SRD datasheet).

## Firmware

A starter ESPHome configuration is provided in
[`esphome/garagepilot-c6.yaml`](esphome/garagepilot-c6.yaml).
It exposes:

* a `cover` entity for the garage door,
* binary sensors for `Door Closed`, `Door Open`, and `Safety Beam`,
* a `Status LED` light,
* a `Restart` button, and
* on-board BOOT button mapped to `cover.toggle`.

Update the `!secret` placeholders before flashing.

## Validation

### Schematic / ERC

KiCad CLI ERC **could not be run**:

```bash
kicad-cli sch erc --format report --output erc_report.rpt garagepilot-c6.kicad_sch
```

Both the native KiCad 8 `.kicad_sch` and a backported KiCad 9 `.kicad_sch` failed to load
with the error `Failed to load schematic` (exit code 3).  This appears to be a KiCad CLI /
generator-version compatibility issue in this workspace, not a missing library file.  ERC
must be performed manually in KiCad's schematic editor until the CLI load failure is resolved.

### PCB / DRC

```bash
cd boards/garagepilot-c6
kicad-cli pcb drc --format report --output routed_drc_report.rpt garagepilot-c6.kicad_pcb
```

Result:

```text
Found 96 DRC violations
Found 23 unconnected items
Found 0 Footprint errors
Found 0 shorting items
Found 0 items not allowed
Found 0 courtyards overlap
Saved DRC Report to routed_drc_report.rpt
```

The remaining issues are:

* **Clearance violations** between autorouted tracks/vias on B.Cu and F.Cu (actual clearances
  down to ~0.075 mm in a few places, below the 0.2 mm rule).
* **Unconnected items** — mostly missing copper connections for VBUS stitching, the relay coil
  path, and a few signal pads that the autorouter did not complete.
* A number of **library footprint mismatch / missing-library warnings**.  These are caused by
  standard KiCad footprints embedded in the board not matching the system's installed KiCad
  library versions, plus the project pinning a non-existent footprint library name.

There are **no shorting items, no courtyard overlaps, and no disallowed items**.
The v0.1 board is therefore documented as routed but **not DRC-clean**.

### 3D models / renders

* All referenced STEP models are present in [`3dmodels/`](3dmodels/) and listed in
  [`3dmodels/MANIFEST.md`](3dmodels/MANIFEST.md) with source URLs, licenses, and SHA-256
  checksums.
* Renders were produced with:

```bash
kicad-cli pcb render -w 1600 -h 1200 --side top --quality high --perspective --rotate=330,330,0 -o images/render3d_top.png garagepilot-c6.kicad_pcb
kicad-cli pcb render -w 1600 -h 1200 --side bottom --quality high --perspective --rotate=210,30,0 -o images/render3d_bottom.png garagepilot-c6.kicad_pcb
kicad-cli pcb render -w 1600 -h 1200 --side top --quality high -o images/render_top.png garagepilot-c6.kicad_pcb
```

The populated SMD models (ESP32 module, relay, USB-C, terminals, passives) are visible in the
renders and were inspected for floating / rotated / badly-scaled geometry.

## Regenerating the project

```bash
python3 boards/garagepilot-c6/gen_garagepilot_c6.py
```

This recreates the project-local symbol library, schematic, and PCB placement.  The copper
is intentionally left unrouted in the generator so the board can be exported to Specctra DSN
and autorouted (see the generator comments for the freeroute pipeline used for v0.1).

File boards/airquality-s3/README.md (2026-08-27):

# airquality-s3 — CO2/VOC/temp/humidity node (SPEC 7.2)

ESP32-S3-WROOM-1 air-quality monitor: SCD40 (CO2), SGP40 (VOC), SHT40
(temp/hum) on one I2C bus, SSD1306 OLED header, USB-C power + flashing.
**v0.1 concept board.**

- Board: 60 × 40 mm, 2-layer, USB-C bottom edge, antenna keep-out top-left
- Power: USB 5 V → AP2112K-3.3 LDO
- Status: `python3 boards/wave2/wave2gen.py airquality-s3` → self-check OK

## BOM (bom_lcsc.csv)

| Ref | Value | Footprint | LCSC # | MPN | Qty |
|---|---|---|---|---|---|
| U1 | ESP32-S3-WROOM-1-N8 | ESP32-S3-WROOM-1 | C2913201 | ESP32-S3-WROOM-1-N8 | 1 |
| U2 | AP2112K-3.3 | SOT-23-5 | C51118 | AP2112K-3.3TRG1 | 1 |
| U3 | SCD40 | custom:SCD40-SMD | C144956 | SCD40-D-R2 | 1 |
| U4 | SGP40 | custom:SGP40-DFN6 | C2905033 | SGP40-D-R4 | 1 |
| U5 | SHT40-AD1B | custom:SHT4x-DFN4 | C2685600 | SHT40-AD1B-R2 | 1 |
| X1 | USB-C 16P | custom:USB-C-16P-MidMount | C165948 | TYPE-C-31-M-12 | 1 |
| BT1,BT2 | SW_PUSH (BOOT / RST) | custom:Tactile-6x6-SMD | C91808 | TS-1187A-B-A-B | 2 |
| D1 | LED red (STAT) | 0603 | C2286 | 17-21SURC/S530-A3/TR8 | 1 |
| R1,R2 | 4.7k (I2C pull-ups) | 0603 | C23162 | 0603WAF4701T5E | 2 |
| R3,R4 | 5.1k (USB CC1/CC2) | 0603 | C23186 | 0603WAF5101T5E | 2 |
| R7 | 10k (EN) | 0603 | C98252 | 0603WAF1002T5E | 1 |
| R8 | 1k (LED) | 0603 | C21190 | 0603WAF1001T5E | 1 |
| C1,C2,C3,C4 | 100nF | 0603 | C14663 | CL10B104KB8NNNC | 4 |
| C5 | 10uF | 0805 | C15850 | CL21A106KPFNNNE | 1 |
| J1 | Conn_01x04 (3V3/TX0/RX0/GND) | PinHeader_1x04_P2.54mm | C49241 | A2541WV-4P | 1 |
| J2 | Conn_01x04 (3V3/SDA/SCL/GND, OLED) | PinHeader_1x04_P2.54mm | C49241 | A2541WV-4P | 1 |

## Pinout (S3-WROOM-1)

| Signal | GPIO | Notes |
|---|---|---|
| I2C_SDA / I2C_SCL | GPIO8 / GPIO9 | R1/R2 4.7k pull-ups; SCD40 0x62, SGP40 0x59, SHT40 0x44, OLED 0x3C |
| BOOT | GPIO0 | BT1 button |
| RST | EN | BT2 button |
| STAT_LED | GPIO38 | D1 via R8 |
| USB D- / D+ | GPIO19 / GPIO20 | native USB-Serial-JTAG flashing |
| TX0 / RX0 | GPIO43 / GPIO44 | J1 spare UART header |

## Firmware

See `esphome/airquality-s3.yaml` — scd4x + sgp40 + sht4x sensors, SSD1306
display on J2, status LED, BOOT button.

## Routing status

**v0.1 concept — signals left for autorouting.** Power rails routed
(VBUS/+3V3/GND with vias + stitching); I2C/UART/USB/sensor signals unrouted.

## Analyzer notes

`analyze_pcb.py`: **DFM-001 = 0**. RT-001 unrouted errors expected
(autoroute deferred). Buttons rotated 90° on the left edge to clear the
module pad columns.

## Caveats (verify before fabrication!)

- SCD40 self-heating skews SHT40 readings — keep sensor spacing / consider
  SCD40 periodic-measurement mode; verify thermal layout before fab.
- USB CC resistors R3/R4 = 5.1k required for USB-C host detection.
- **Verify all footprints, pin numbers, and clearances against KiCad
  libraries + datasheets before ordering boards.**

## Renders

| Raytraced 3D (KiCad) | 2D layout |
|---|---|
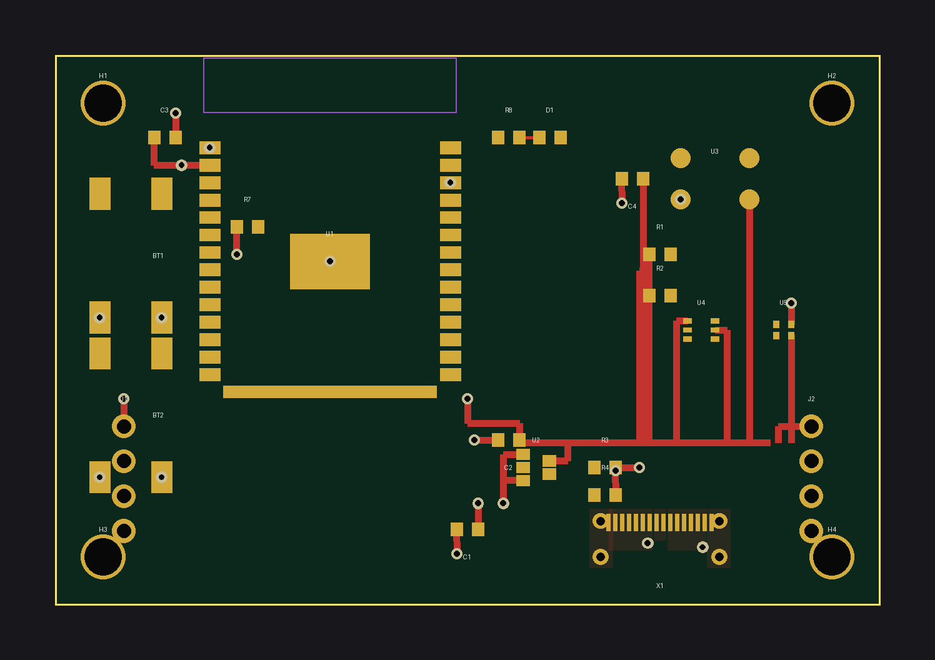
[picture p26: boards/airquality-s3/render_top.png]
| top |  |
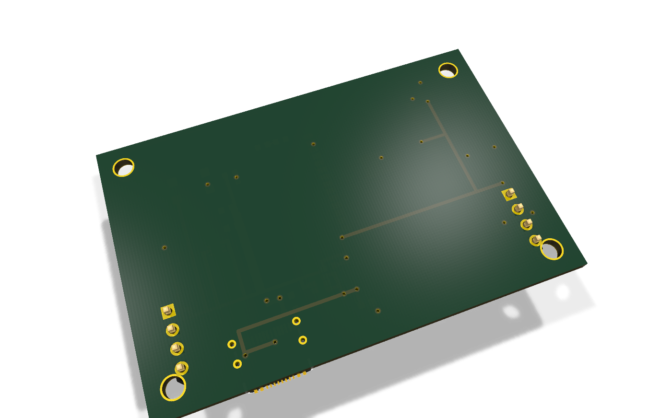
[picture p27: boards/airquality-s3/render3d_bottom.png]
bottom
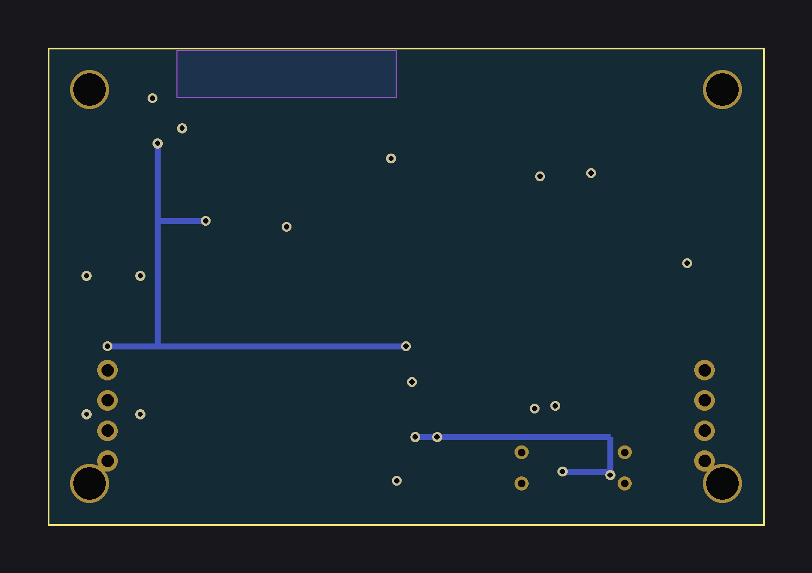
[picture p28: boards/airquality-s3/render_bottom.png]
bottom
|  |  |

360° turntable

🎬 24 real KiCad raytraced frames stitched with ffmpeg (tools/turntable.sh).

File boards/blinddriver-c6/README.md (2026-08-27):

# blinddriver-c6 — TMC2209 roller-blind controller (SPEC 7.3)

ESP32-C6-WROOM-1 driving a TMC2209 stepper socket for a roller blind:
12 V VMOT input (SS34 reverse-polarity protection), AP63205 buck to 5 V,
AP2112 to 3.3 V, screw terminals for motor + VMOT, end-stop header.
**v0.1 concept board.**

- Board: 60 × 40 mm, 2-layer, USB-C bottom edge
- Status: `python3 boards/wave2/wave2gen.py blinddriver-c6` → self-check OK

## BOM (bom_lcsc.csv)

| Ref | Value | Footprint | LCSC # | MPN | Qty |
|---|---|---|---|---|---|
| U1 | ESP32-C6-WROOM-1 | ESP32-C6-WROOM-1 | C2946979 | ESP32-C6-WROOM-1-N8 | 1 |
| U2 | AP63205 (buck 12V→5V) | SOT-23-6 | C2677326 | AP63205WU-7 | 1 |
| U3 | AP2112K-3.3 | SOT-23-5 | C51118 | AP2112K-3.3TRG1 | 1 |
| U4 | TMC2209 module | custom:TMC2209-Socket (J3/J4) | C3137092 | TMC2209 | 1 |
| L1 | 4.7uH | custom:Inductor-4x4 | C424814 | SWPA4026S4R7MT | 1 |
| D1 | LED red (STAT) | 0603 | C2286 | 17-21SURC/S530-A3/TR8 | 1 |
| D2 | SS34 (VMOT reverse pol.) | SMA | C14936 | SS34 | 1 |
| D3 | SS34 (buck catch) | SMA | C14936 | SS34 | 1 |
| X1 | USB-C 16P | custom:USB-C-16P-MidMount | C165948 | TYPE-C-31-M-12 | 1 |
| BT1,BT2 | SW_PUSH (BOOT / RST) | custom:Tactile-6x6-SMD | C91808 | TS-1187A-B-A-B | 2 |
| R8 | 1k | 0603 | C21190 | 0603WAF1001T5E | 1 |
| R1,R2,R9 | 5.1k (CC/USB) | 0603 | C23186 | 0603WAF5101T5E | 3 |
| R3,R4 | 22R (USB series) | 0603 | C25076 | 0603WAF220JT5E | 2 |
| R7 | 10k (EN) | 0603 | C98252 | 0603WAF1002T5E | 1 |
| R10,R11 | 100k (buck FB) | 0603 | C98258 | 0603WAF1003T5E | 2 |
| C1–C7 | 100nF | 0603 | C14663 | CL10B104KB8NNNC | 7 |
| C8 | 100uF (VMOT bulk) | custom:CP-Elec-6.3x5.4 | C145465 | RVT1H101M0607 | 1 |
| J5 | VMOT_IN screw 1x02 | custom:ScrewTerm-5.08-2P | C8464 | KF128-5.08-2P | 1 |
| J6,J7 | MOT_A / MOT_B screw 1x02 | custom:ScrewTerm-5.08-2P | C8464 | KF128-5.08-2P | 2 |
| J8 | Conn_01x03 (3V3/ENDSTOP/GND) | PinHeader_1x03_P2.54mm | C49240 | A2541WV-3P | 1 |

## Pinout (C6-WROOM-1)

| Signal | GPIO | Notes |
|---|---|---|
| STEP / DIR | GPIO4 / GPIO5 | to TMC2209 socket |
| TMC_EN | GPIO6 | low = driver enabled |
| DIAG | GPIO7 | TMC2209 diagnostic output |
| TMC_UART | GPIO15 | 1-wire UART config (PDN_UART) |
| ENDSTOP | GPIO18 | J8 header, pull-up |
| STAT_LED | GPIO1 | D1 via R8 |
| BOOT | GPIO0 | BT1; RST = EN (BT2) |
| USB D- / D+ | GPIO12 / GPIO13 | via 22R R3/R4, native USB flashing |
| TX0 / RX0 | GPIO16 / GPIO17 | spare |

## Firmware

See `esphome/blinddriver-c6.yaml` — stepdir stepper + time_based cover,
end-stop binary sensor, driver-enable switch, TMC2209 UART note.

## Routing status

**v0.1 concept — signals left for autorouting.** Power rails routed
(VMOT/12V/+5V/+3V3/GND, 0.5 mm power width, GND stitching); STEP/DIR/UART/
DIAG/end-stop signals unrouted.

## Analyzer notes

`analyze_pcb.py`: **DFM-001 = 0**. RT-001 unrouted errors expected.
STAT_LED was unassigned in the original plan — now on GPIO1.

## Caveats (verify before fabrication!)

- 12 V VMOT: check SS34 orientation (D2 input, D3 buck catch) and C8
  ripple rating for your motor current.
- TMC2209 socket pinout follows the common StepStick order — verify
  against your module (there are two header orientations).
- Buck feedback R10/R11 100k/100k sets 5 V via AP63205 reference — verify
  ratio against datasheet before fab.
- **Verify all footprints, pin numbers, and clearances against KiCad
  libraries + datasheets before ordering boards.**

## Renders

| Raytraced 3D (KiCad) | 2D layout |
|---|---|
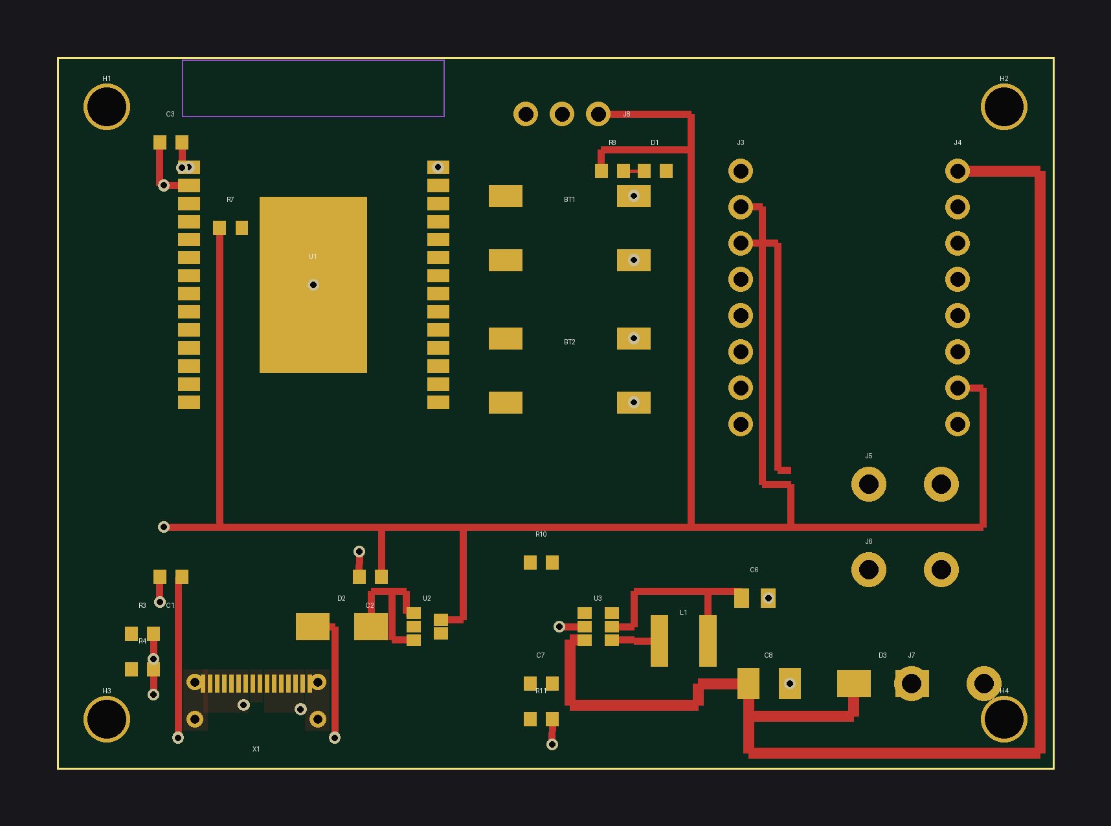
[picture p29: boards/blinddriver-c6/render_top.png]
| top |  |
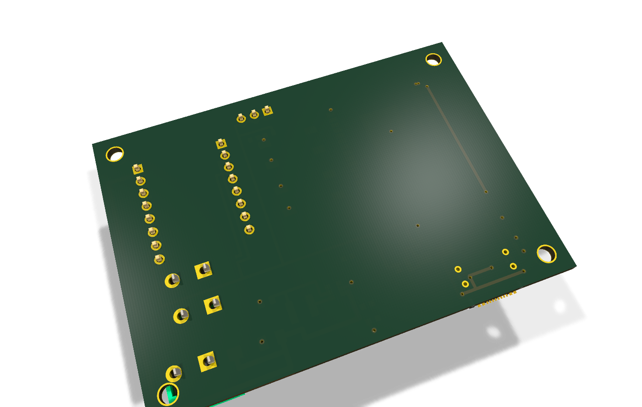
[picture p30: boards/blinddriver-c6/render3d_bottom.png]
bottom
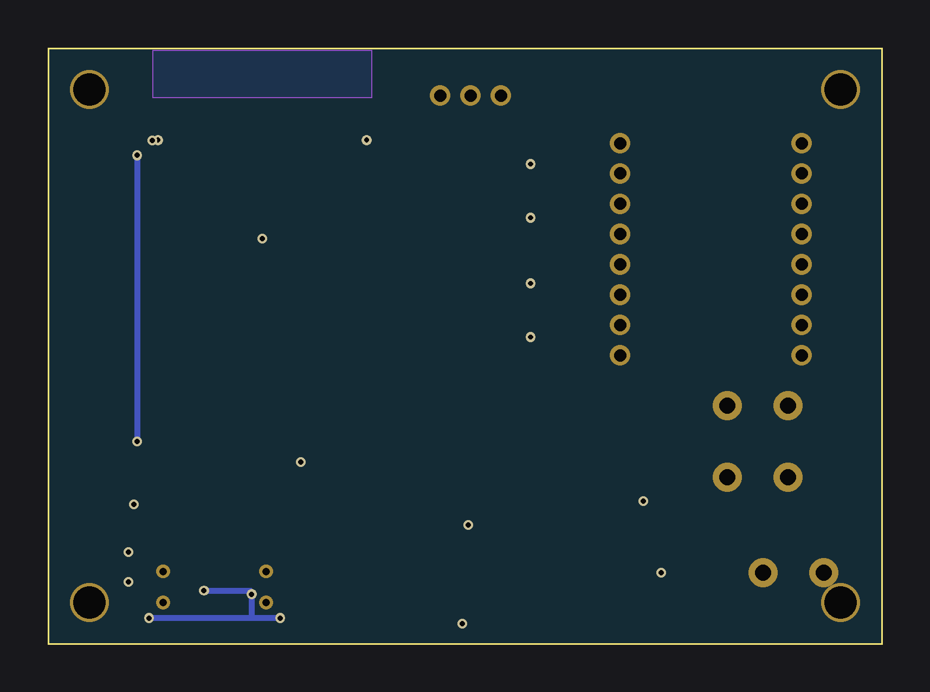
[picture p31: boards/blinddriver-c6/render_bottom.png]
bottom
|  |  |

360° turntable

🎬 24 real KiCad raytraced frames stitched with ffmpeg (tools/turntable.sh).

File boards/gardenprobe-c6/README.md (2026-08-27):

# gardenprobe-c6 — battery soil-moisture stick node (SPEC 7.5)

ESP32-C6-WROOM-1 soil-probe node: 70 × 25 mm stick with capacitive copper
probe area on the B.Cu tip (J2), JST-PH LiPo input, MCP1700-3302 LDO,
AO3401 sensor-rail load switch, SHT31 temp/humidity, battery divider.
**v0.1 concept board.**

- Board: 70 × 25 mm, 2-layer; antenna keep-out along left edge; probe tip right
- Power: 3.7 V LiPo on JST-PH (BT1) — **charge externally, no charger on board**
- Status: `python3 boards/wave2/wave2gen.py gardenprobe-c6` → self-check OK

## BOM (bom_lcsc.csv)

| Ref | Value | Footprint | LCSC # | MPN | Qty |
|---|---|---|---|---|---|
| U1 | ESP32-C6-WROOM-1 (rot 270°) | ESP32-C6-WROOM-1 | C2946979 | ESP32-C6-WROOM-1-N8 | 1 |
| U2 | MCP1700-3302E | SOT-23 | C63395 | MCP1700T-3302E/TT | 1 |
| U3 | SHT31-DIS | custom:SHT31-DFN8 | C23324 | SHT31-DIS-B2.5kS | 1 |
| Q1 | AO3401 (load switch) | SOT-23 | C15127 | AO3401A | 1 |
| BT1 | JST-PH 2P (LiPo) | custom:JST-PH-S2B | C265758 | S2B-PH-K-S | 1 |
| J2 | SoilProbe electrodes | custom:SoilProbe-BCu | — | copper area on B.Cu (ENIG rec.) | 1 |
| R1,R4 | 100k (battery divider) | 0603 | C98258 | 0603WAF1003T5E | 2 |
| R5 | 1M (soil charge) | 0603 | C22935 | 0603WAF1004T5E | 1 |
| R3 | 10k (load-switch gate) | 0603 | C98252 | 0603WAF1002T5E | 1 |
| R6,R7 | 4.7k (I2C pull-ups, switched) | 0603 | C23162 | 0603WAF4701T5E | 2 |
| C1,C2,C3,C4 | 100nF | 0603 | C14663 | CL10B104KB8NNNC | 4 |
| J1 | Conn_01x04 (3V3/TX0/RX0/GND) | PinHeader_1x04_P2.54mm | C49241 | A2541WV-4P | 1 |

## Pinout (C6-WROOM-1)

| Signal | GPIO | Notes |
|---|---|---|
| SOIL_ADC | GPIO0 | probe sense via R5 1M from GPIO1 (fixed-RC) |
| SOIL_CHG | GPIO1 | charge/drive pin for probe |
| BATT_ADC | GPIO2 | 100k/100k divider → Vbat/2 |
| LOAD_EN | GPIO3 | Q1 AO3401 → +3V3_SW (SHT31 + I2C pull-ups) |
| I2C_SDA / I2C_SCL | GPIO20 / GPIO21 | U3 SHT31 (0x44), pull-ups on switched rail |
| TX0 / RX0 | GPIO16 / GPIO17 | J1 prog header (flash via UART; no USB) |
| EN | — | pull-up + C2 |

## Firmware

See `esphome/gardenprobe-c6.yaml` — load-switch GPIO3, sht3xd on switched
I2C, ADC soil raw (GPIO0) + battery (GPIO2, ×2), deep-sleep 30 min cycles.
Calibrate soil raw → % per installation.

## Routing status

**v0.1 concept — signals left for autorouting.** Power rails routed
(VBAT/+3V3/+3V3_SW/GND + stitching); ADC/I2C/UART/enable signals unrouted.

## Analyzer notes

`analyze_pcb.py`: **DFM-001 = 0**. RT-001 unrouted errors expected.
SHT31 DFN-8 EP resized (1.4×1.0) to clear the 1.05 mm pad columns.

## Caveats (verify before fabrication!)

- No battery charger on board — LiPo must be charged externally; consider
  adding protection (DW01) for production.
- Probe electrodes are bare B.Cu — specify ENIG or immersion-gold finish;
  HASL/copper will corrode in soil quickly.
- MCP1700 Iq ~1.6 µA suits sleep; verify divider current budget (100k/100k
  ≈ 21 µA at 4.2 V — the dominant sleep draw; raise values if needed).
- **Verify all footprints, pin numbers, and clearances against KiCad
  libraries + datasheets before ordering boards.**

## Renders

| Raytraced 3D (KiCad) | 2D layout |
|---|---|
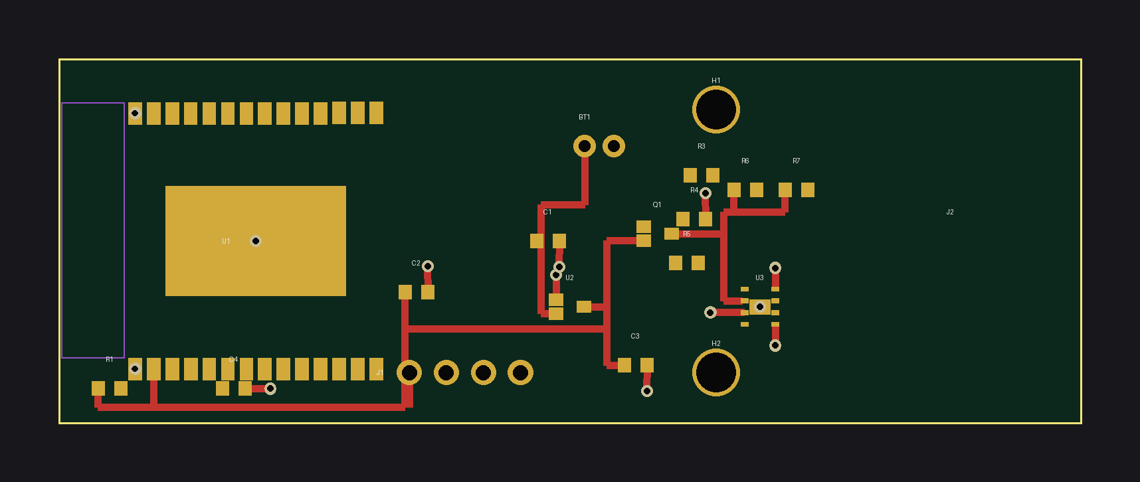
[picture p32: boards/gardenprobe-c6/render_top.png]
| top |  |
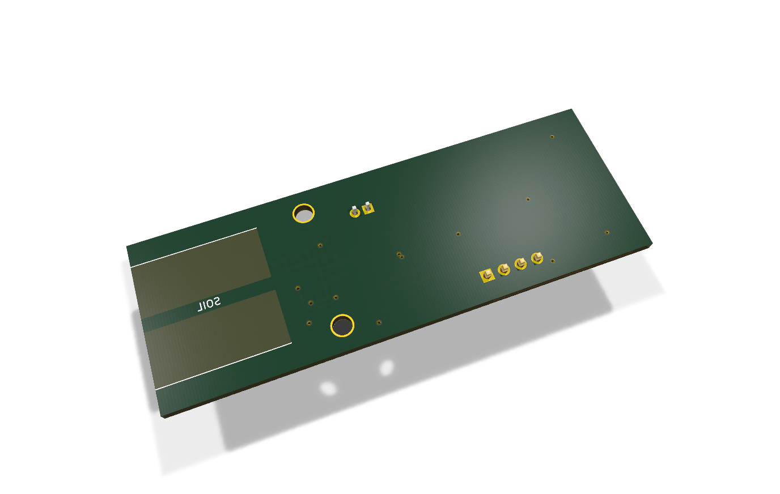
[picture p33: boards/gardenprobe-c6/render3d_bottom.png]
bottom
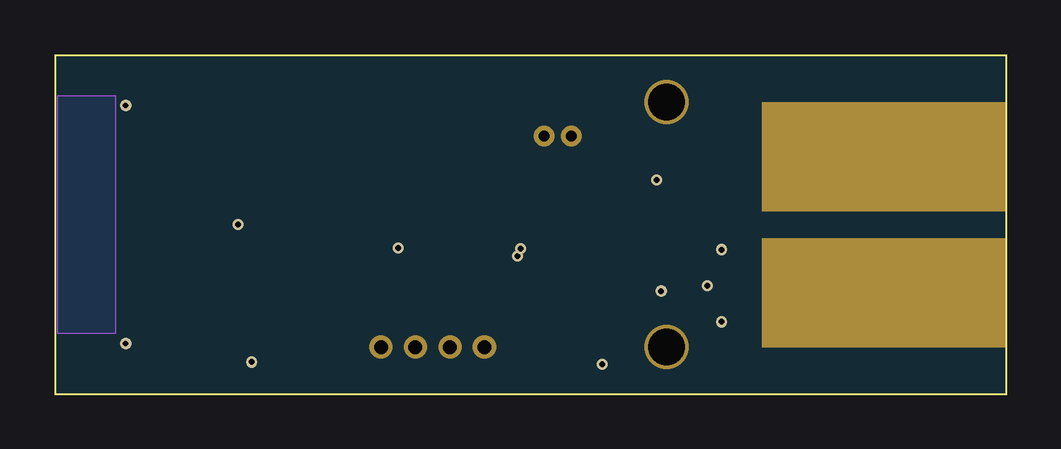
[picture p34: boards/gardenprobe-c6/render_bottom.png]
bottom
|  |  |

360° turntable

🎬 24 real KiCad raytraced frames stitched with ffmpeg (tools/turntable.sh).

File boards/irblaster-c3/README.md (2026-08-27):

# irblaster-c3 — IR climate bridge (SPEC 7.4)

ESP32-C3-WROOM-02 IR blaster/receiver: 2× TSAL6200 driven by an S8050 from
GPIO4, TSOP38238 receiver on GPIO5, optional BH1750 lux sensor on I2C.
**v0.1 concept board.**

- Board: 45 × 30 mm, 2-layer, 3 mounting holes, USB-C bottom edge
- Status: `python3 boards/wave2/wave2gen.py irblaster-c3` → self-check OK

## BOM (bom_lcsc.csv)

| Ref | Value | Footprint | LCSC # | MPN | Qty |
|---|---|---|---|---|---|
| U1 | ESP32-C3-WROOM-02 | ESP32-C3-WROOM-02 | C2934569 | ESP32-C3-WROOM-02-N4 | 1 |
| U2 | AP2112K-3.3 | SOT-23-5 | C51118 | AP2112K-3.3TRG1 | 1 |
| U3 | TSOP38238 | custom:TSOP382xx | C2916293 | TSOP38238 | 1 |
| U4 | BH1750FVI | custom:BH1750-WSOF6 | C78955 | BH1750FVI-TR | 1 |
| Q1 | S8050 | SOT-23 | C2148 | S8050 | 1 |
| D2,D3 | TSAL6200 IR LEDs | custom:IRLED-5mm | C2895983 | TSAL6200 | 2 |
| D1 | LED red (STAT) | 0603 | C2286 | 17-21SURC/S530-A3/TR8 | 1 |
| X1 | USB-C 16P | custom:USB-C-16P-MidMount | C165948 | TYPE-C-31-M-12 | 1 |
| BT1 | SW_PUSH (BOOT) | custom:Tactile-6x6-SMD | C91808 | TS-1187A-B-A-B | 1 |
| R6,R7 | 47R (IR LED ballast) | 0603 | C23134 | 0603WAF470JT5E | 2 |
| R3,R4 | 5.1k (USB CC) | 0603 | C23186 | 0603WAF5101T5E | 2 |
| R5 | 4.7k (RX pull-up) | 0603 | C23162 | 0603WAF4701T5E | 1 |
| R2,R8 | 1k | 0603 | C21190 | 0603WAF1001T5E | 2 |
| R9 | 100R (Q1 base) | 0603 | C22775 | 0603WAF1000T5E | 1 |
| R1 | 10k (EN) | 0603 | C98252 | 0603WAF1002T5E | 1 |
| C1–C4 | 100nF | 0603 | C14663 | CL10B104KB8NNNC | 4 |
| C5 | 10uF | 0805 | C15850 | CL21A106KPFNNNE | 1 |
| J1 | Conn_01x04 (3V3/TX0/RX0/GND) | PinHeader_1x04_P2.54mm | C49241 | A2541WV-4P | 1 |

## Pinout (C3-WROOM-02)

| Signal | GPIO | Notes |
|---|---|---|
| IR_TX | GPIO4 | R9 100R → Q1 S8050 → D2/D3 (R6/R7 47R) |
| IR_RX | GPIO5 | U3 TSOP38238 out, R5 4.7k pull-up, C4 100nF |
| I2C_SDA / I2C_SCL | GPIO6 / GPIO7 | U4 BH1750 (0x23) |
| STAT_LED | GPIO10 | D1 via R8 |
| BOOT | GPIO9 | BT1 |
| USB D- / D+ | GPIO18 / GPIO19 | native USB-Serial-JTAG |
| TX0 / RX0 | GPIO21 / GPIO20 | J1 prog header |

## Firmware

See `esphome/irblaster-c3.yaml` — remote_transmitter (GPIO4, 50% carrier),
remote_receiver (GPIO5), bh1750 sensor, climate_ir example stub.

## Routing status

**v0.1 concept — signals left for autorouting.** Power rails routed
(VBUS/+3V3/GND + stitching); IR_TX/IR_RX/I2C/USB signals unrouted.

## Analyzer notes

`analyze_pcb.py`: **DFM-001 = 0**. RT-001 unrouted errors expected.
BH1750 WSOF6 footprint uses 0.95 mm pitch (was fixed from 0.5 mm draft).

## Caveats (verify before fabrication!)

- IR LED current: 47R ballasts give ~40–60 mA pulse per LED from 5 V —
  check S8050 SOA and duty cycle for long NEC bursts; reduce if needed.
- TSOP38238 supply filter (R/C per datasheet) recommended before fab.
- **Verify all footprints, pin numbers, and clearances against KiCad
  libraries + datasheets before ordering boards.**

## Renders

| Raytraced 3D (KiCad) | 2D layout |
|---|---|
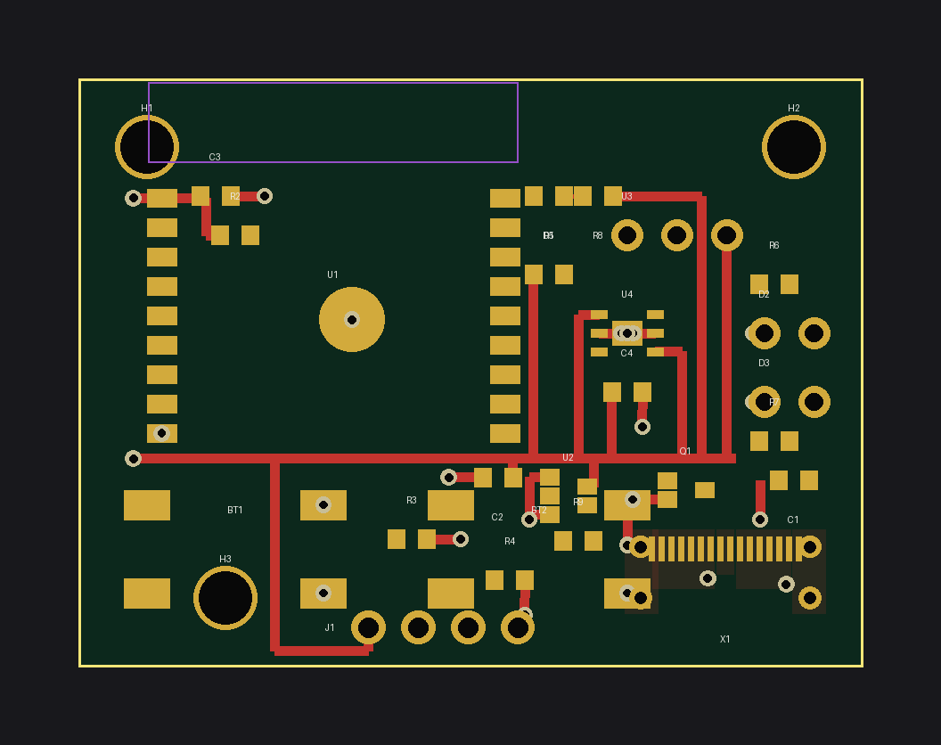
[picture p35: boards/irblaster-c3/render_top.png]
| top |  |
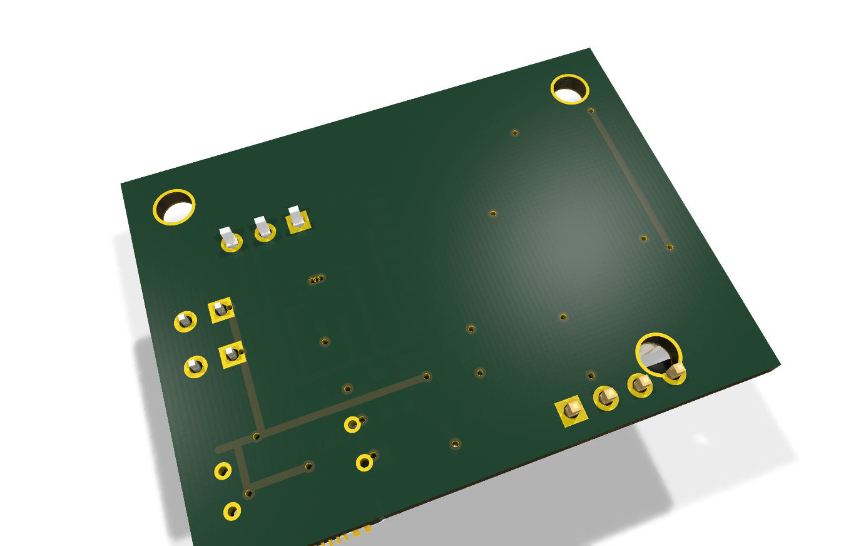
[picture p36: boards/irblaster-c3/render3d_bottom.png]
bottom
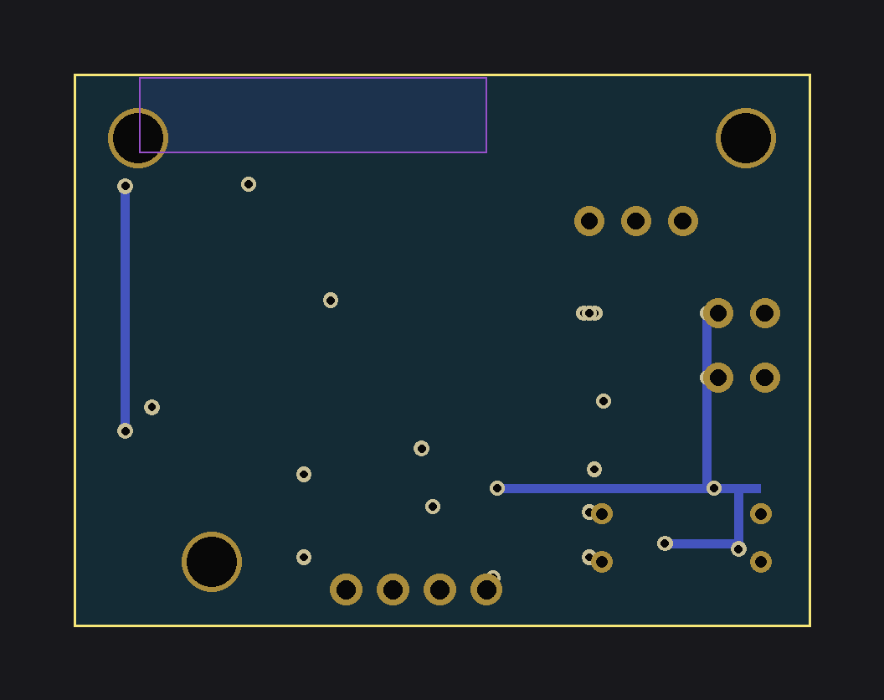
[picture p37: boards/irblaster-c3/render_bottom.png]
bottom
|  |  |

360° turntable

🎬 24 real KiCad raytraced frames stitched with ffmpeg (tools/turntable.sh).

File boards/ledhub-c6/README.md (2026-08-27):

# ledhub-c6 — all-in-one display LED controller (80 × 50 mm)

ESP32-C6-WROOM-1 based LED controller with 2.8" ILI9341 TFT, EC11 rotary
encoder, 5-way ADC-ladder nav buttons, INMP441 I2S microphone, SHT31 +
BH1750 environmental sensors, LD2450 mmWave radar header, and a 5 V
level-shifted WS2812 output (74AHCT125 + 470 Ω).

**Primary firmware: WLED 0.15+** (ESP32-C6 supported since 0.15) with
`firmware/wled-usermod-ledhub/`. ESPHome is also possible — see
`esphome/ledhub-c6.yaml` (draft covering display, encoder, ADC buttons,
I2S mic, I2C sensors, LD2450 UART, RMT LED strip).

License: MIT. KiCad 8 project, generated by `gen_ledhub_c6.py`
(`python3 gen_ledhub_c6.py`; exits non-zero on any validation problem).

## Features

- USB-C power + native USB-Serial-JTAG flashing (GPIO12/13 via 22 Ω,
  5.1 kΩ CC pull-downs)
- AP2112K-3.3 LDO (VBUS → +3V3), logic 5 V rail `+5V` from VBUS via R20 0R
- Separate `LED_5V` input terminal (J4, 5.08 mm) powering the LED strip
  only; LED data out on J3 (LED_5V / DATA / GND)
- 74AHCT125 (U5, SOIC-14, VCC=+5V, 1OE=GND) level-shifts GPIO3 → LED_DATA
  through R19 470 Ω
- Antenna keepout (no copper, all layers) at the module antenna end

## Frozen pin map (firmware contract — do not change)

| Function | ESP32-C6 GPIO |
|---|---|
| TFT SCK / MOSI / CS / DC / RST / BL | 6 / 7 / 5 / 4 / 1 / 2 |
| Encoder A / B (common = GND; push NC) | 15 / 16 |
| Nav button ladder (ADC1_CH0) | 0 |
| INMP441 I2S SCK / WS / SD (L/R=GND) | 17 / 18 / 19 |
| I2C SDA / SCL (SHT31 + BH1750, 4.7 kΩ) | 20 / 21 |
| LD2450: MCU_RX ← radar TX / MCU_TX → radar RX | 22 / 23 |
| WS2812 data (via 74AHCT125) | 3 |
| USB D− / D+ | 12 / 13 |
| UART0 TX0 / RX0 (prog header J5) | 16 / 17 |
| BOOT button / EN reset | 9 / EN |

GPIO 8/9/12/13/26–30 avoided for general I/O (strapping/USB/flash).

## GPIO16/17 double-assignment — R16/R17 0Ω links

The frozen pin map uses GPIO16 for both ENC_B and UART0 TX0, and GPIO17
for both I2S_SCK and UART0 RX0. R16 (ENC_B↔TX0) and R17 (I2S_SCK↔RX0)
are 0 Ω links, fitted by default. **Flash firmware via native USB-C**
(USB-Serial-JTAG on GPIO12/13) — no UART adapter needed. For classic
UART0 flashing via J5, remove R16/R17 (or accept encoder/I2S contention
while the programmer is attached). Documented on the schematic (title
block notes) and here.

## ADC button ladder (GPIO0, 12-bit)

Topology: +3V3 —10 kΩ (R11)— GPIO0 node; each button shorts the node to
GND through its ladder resistor:

| Button | R | Voltage | ADC (0–4095) | Threshold band |
|---|---|---|---|---|
| UP | 0 Ω (R12) | 0.000 V | 0 | < 369 |
| DN | 2.2 kΩ (R13) | 0.595 V | 738 | 369–1023 |
| LF | 4.7 kΩ (R14) | 1.055 V | 1308 | 1023–1678 |
| RT | 10 kΩ (R15) | 1.650 V | 2048 | 1678–2430 |
| OK | 22 kΩ (R18) | 2.269 V | 2813 | 2430–3454 |
| none | — | 3.300 V | 4095 | > 3454 |

## BOM (bom_lcsc.csv; LCSC numbers verified in-stock via jlcsearch, 2026-08)

| Ref | Value | Footprint | LCSC # | MPN | Qty |
|---|---|---|---|---|---|
| U1 | ESP32-C6-WROOM-1 | custom 18×25.5 mm | C5366877 | ESP32-C6-WROOM-1-N8 | 1 |
| X1 | USB-C 16P receptacle | USB_C_Receptacle_USB2.0_16P | C165948 | TYPE-C-31-M-12 | 1 |
| U2 | INMP441 (bottom port) | custom LGA-9 | — (not stocked) | INMP441ACEZ-R7 | 1 |
| U3 | SHT31 | custom DFN-8 2.5×2.5 | C80862 | SHT31-DIS-B2.5kS | 1 |
| U4 | BH1750 | custom WSOF-6I | C78960 | BH1750FVI-TR | 1 |
| U5 | 74AHCT125 | SOIC-14 | C842299 | 74AHCT125S14-13 | 1 |
| U6 | AP2112K-3.3 | SOT-23-5 | C51118 | AP2112K-3.3TRG1 | 1 |
| ENC1 | EC11 encoder | custom THT | C370970 | EC11E15244G1 | 1 |
| R1,R2,R14 | 4.7 kΩ | 0603 | C23162 | 0603WAF4701T5E | 3 |
| R13 | 2.2 kΩ | 0603 | C4190 | 0603WAF2201T5E | 1 |
| R7,R10,R11,R15 | 10 kΩ | 0603 | C25804 | 0603WAF1002T5E | 4 |
| R18 | 22 kΩ | 0603 | C31850 | 0603WAF2202T5E | 1 |
| R3,R4 | 5.1 kΩ | 0603 | C23186 | 0603WAF5101T5E | 2 |
| R5,R6 | 22 Ω | 0603 | C22926 | 0603WAF220JT5E | 2 |
| R9 | 100 Ω | 0603 | C22775 | 0603WAF1000T5E | 1 |
| R19 | 470 Ω | 0603 | C23179 | 0603WAF4700T5E | 1 |
| R8 | 1 kΩ | 0603 | C21190 | 0603WAF1001T5E | 1 |
| R12,R16,R17,R20,R21 | 0 Ω link | 0603 | C21189 | 0603WAF0000T5E | 5 |
| C1,C2,C8 | 10 µF | 0603 | C15849 | CL10A106KP8NNNC | 3 |
| C3–C7,C9,C10 | 100 nF | 0603 | C14663 | 0603B104K500NT | 7 |
| D1 | red LED | 0603 | C2286 | LTST-C190KRKT | 1 |
| BT1,BT2,BT_UP/DN/LF/RT/OK | tactile 6×6 | custom SMD | C318884 | TS-1187A-B-A-B | 7 |
| J1 | 2×7 header (TFT) | PinHeader_2x07 | C492424 | PZ254V-12-14P | 1 |
| J2 | 1×5 header (LD2450) | PinHeader_1x05 | C492404 | PZ254V-11-05P | 1 |
| J5 | 1×4 header (prog) | PinHeader_1x04 | C2691448 | PZ254V-11-04P | 1 |
| J3 | screw terminal 3P | custom KF128-5.08 | C474953 | KF128-5.08-3P-AA | 1 |
| J4 | screw terminal 2P | custom KF128-5.08 | C474952 | KF128-5.08-2P-AA | 1 |
| (on J1) | 2.8" ILI9341 TFT module | module | — | ILI9341-2.8-SPI | 1 |
| (on J2) | LD2450 radar module | module | — | HLK-LD2450 | 1 |

## Assembly / mechanical notes

- **INMP441 (U2)** is a bottom-port LGA (4.72×3.76 mm): the PCB has an
  Ø0.8 mm sound-port hole under the package. Reflow strongly
  recommended; hand-soldering is hostile (no exposed pad edges). Do not
  plug the port hole with solder.
- **SHT31** footprint is the real DFN-8 2.5×2.5 mm package.
- **TFT module** on J1 (2×7 header) may overhang the board edge —
  mechanical note only; confirm clearance in the enclosure.
- EC11 switch pins are NC (push = use OK button instead).
- TFT backlight: GPIO2 via R9 100 Ω, R10 10 kΩ pull-down keeps the
  backlight off during reset.

## Routing status

Rev 1.0 ships with **no routed tracks/vias**: all nets are ratsnest
(a full-board GND pour on B.Cu plus small per-net marker pours on F.Cu
document the net set). A previous auto-routing attempt produced cross-net
collisions, so routing is deliberately deferred to interactive work in
KiCad (or a verified autorouter pass). Power rails must be routed at
≥ 0.5 mm when done. The generator self-checks pad/courtyard clearances
geometrically and the kicad-happy analyzer reports **0 cross-net
(DFM-001) violations**.

## Analyzer notes (kicad-happy triage)

- PM-002 BT1/BT2 0.75 mm from board edge: intentional (left-edge button
  column); >= 0.5 mm fab clearance held.
- TE-001 no test points: prog header J5 + module pads serve as access.
- TV-001 no thermal vias on U1 EP: EP is ground-paddle soldered;
  C6 module dissipation is modest; add via-in-pad if thermals matter.
- PU-001 SHT31 ALERT/RESET NC by design (not used).
- RS-001 +5V/LED_5V/VBUS "no declared source": rails enter via USB-C /
  screw terminals (connectors are the sources).
- DS-002: datasheets/ sync is handled by the repo-level parts pipeline.

## Flashing

1. Hold BOOT (BT2), tap EN (BT1), release BOOT → download mode.
2. `esptool.py --chip esp32c6 write_flash ...` via the USB-C port
   (native USB-Serial-JTAG), or `esphome run esphome/ledhub-c6.yaml`.
3. UART0 header J5 (+3V3/TX0/RX0/GND) only with R16/R17 removed.

**Verify all custom footprints against the manufacturer datasheets before
fabrication.** Renders: see below (`render_top.png` / `render_bottom.png`
when generated by `tools/render_pcb.py`).

## Renders

| Raytraced 3D (KiCad) | 2D layout |
|---|---|
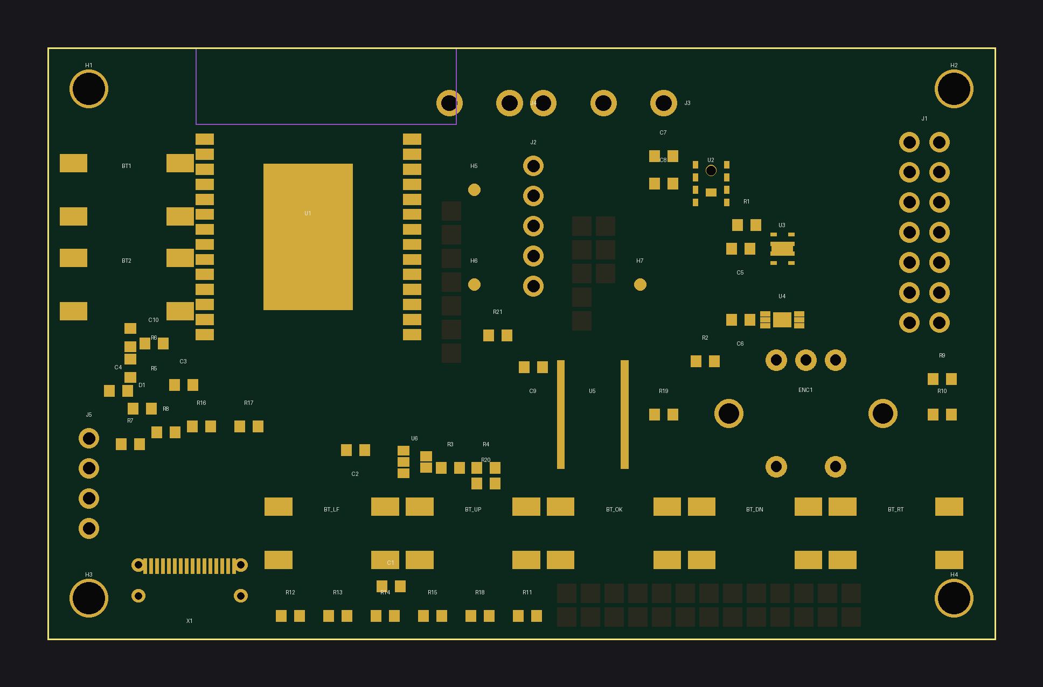
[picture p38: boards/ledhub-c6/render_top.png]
| top |  |
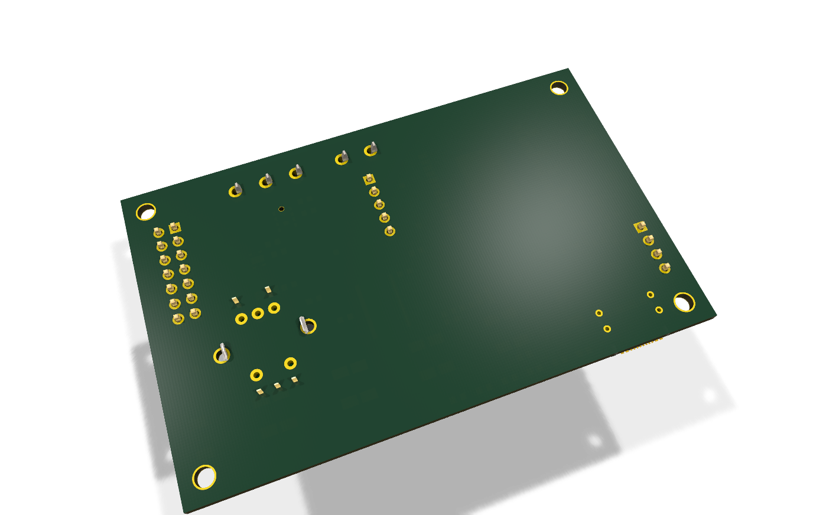
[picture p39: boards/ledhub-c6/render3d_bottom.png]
bottom
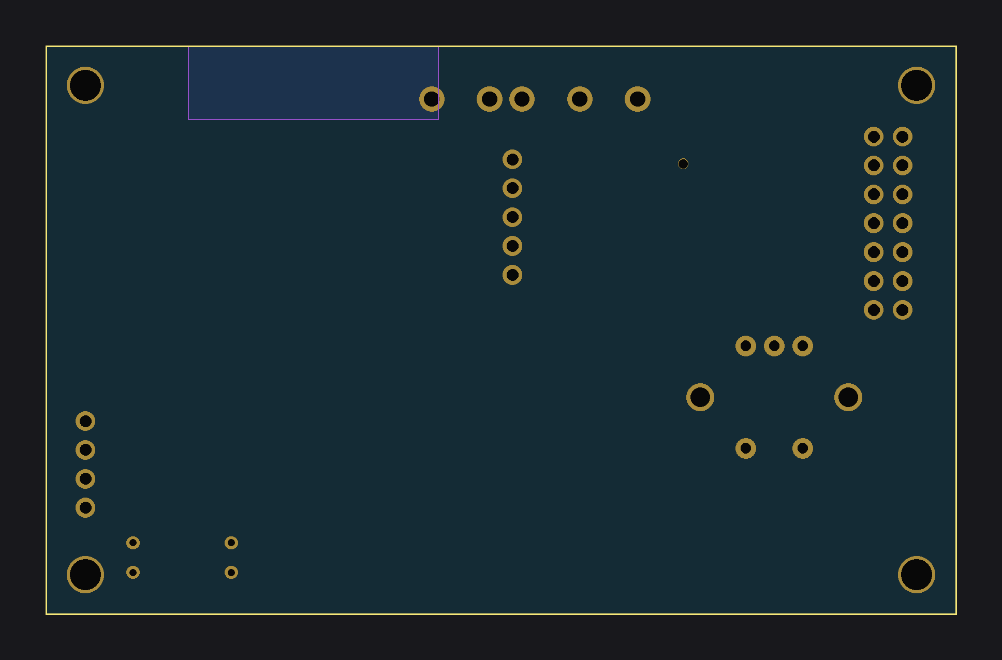
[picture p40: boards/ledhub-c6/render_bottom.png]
bottom
|  |  |

360° turntable

🎬 24 real KiCad raytraced frames
stitched with ffmpeg (`tools/turntable.sh`).

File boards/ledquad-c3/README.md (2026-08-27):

# ledquad-c3 — 4-ch 12–24 V PWM LED strip driver (50 × 40 mm)

ESP32-C3-WROOM-02 based 4-channel (RGBW) low-side PWM LED strip driver.
12–24 V in on J1 (5.08 mm screw terminal, fused), AP63205 buck → +5V/2 A,
AP2112K-3.3 LDO → +3V3 logic, 4× AO3400A N-MOSFET output stages, USB-C
programming with SS34 diode-OR between VBUS and the buck 5 V rail.

License: MIT. KiCad 8 project, generated by `gen_ledquad_c3.py`
(`python3 gen_ledquad_c3.py`; exits non-zero on any validation problem).

## Features

- 4× PWM channels, 12–24 V strips: R=GPIO4, G=GPIO5, B=GPIO6, W=GPIO7,
  100 Ω gate resistors + 10 kΩ pull-downs, low-side AO3400A (SOT-23)
- J1: 2-pin 5.08 mm terminal, 12–24 V in; F1 5 A fuse (1206)
- U2 AP63205 buck, fixed 5 V / 2 A (L1 4.7 µH, Cin 10 µF, Cout 2×22 µF,
  BST 100 nF — datasheet typical circuit;
  https://www.diodes.com/assets/Datasheets/AP63205.pdf)
- U3 AP2112K-3.3 LDO for logic
- X1 USB-C 16P programming (5.1 kΩ CC, D+/D− → GPIO19/18 via 22 Ω);
  VBUS diode-OR'd with buck 5 V via D3/D4 (SS34, D_SMA)
- J2: 5-pin 5.08 mm terminal: V+, R, G, B, W (strip connection)
- J3: 1×4 prog header (+3V3 / TX0=GPIO21 / RX0=GPIO20 / GND)
- BT1 EN reset, BT2 BOOT (GPIO9); D1 power LED, D2 status LED (GPIO10)
- Antenna keepout (no copper, all layers), 3 assembly fiducials,
  GND pour on B.Cu

WLED-compatible pin header: J2's V+/R/G/B/W pinout matches common RGBW
screw-terminal strips; the pin map (GPIO4–7) is usable from WLED builds
with a custom LED output config.

## Pinout

| Function | ESP32-C3 GPIO |
|---|---|
| PWM R / G / B / W | 4 / 5 / 6 / 7 |
| Status LED D2 | 10 |
| BOOT button BT2 | 9 |
| USB D− / D+ | 18 / 19 |
| UART0 TX0 / RX0 (J3) | 21 / 20 |
| EN reset BT1 | EN |

J1: pin 1 = VIN (12–24 V +), pin 2 = GND.
J2: pin 1 = V+ (VIN), pins 2–5 = R/G/B/W (switched low side).
J3: pin 1 = +3V3, pin 2 = TX0 (GPIO21), pin 3 = RX0 (GPIO20), pin 4 = GND.

## BOM

See `bom_lcsc.csv` (machine-readable, grouped by part type).

| Ref | Value | Footprint | LCSC | MPN | Qty |
|---|---|---|---|---|---|
| U1 | ESP32-C3-WROOM-02 | custom | C2934560 | ESP32-C3-WROOM-02-N4 | 1 |
| X1 | USB-C 16P | USB_C_Receptacle_USB2.0_16P | C165948 | TYPE-C-31-M-12 | 1 |
| U2 | AP63205 buck 5V/2A | SOT-23-6 | C2071056 | AP63205WU-7 | 1 |
| U3 | AP2112K-3.3 LDO | SOT-23-5 | C51115 | AP2112K-3.3TRG1 | 1 |
| Q1–Q4 | AO3400A N-MOSFET | SOT-23 | C20917 | AO3400A | 4 |
| D3, D4 | SS34 Schottky | D_SMA | C8678 | SS34 | 2 |
| F1 | Fuse 5 A | 1206 | C136351 | JFC1206-1500FS | 1 |
| L1 | 4.7 µH inductor | custom 4×4 | C167874 | FNR4030S4R7MT | 1 |
| J1 | Screw terminal 2P 5.08 | custom | C474952 | KF128-5.08-2P-AA | 1 |
| J2 | Screw terminal 5P 5.08 | custom | C42377750 | WJ500V-5.08-05P-14-00A | 1 |
| J3 | Header 1×4 | 2.54 mm | C49258 | KH-2.54PH180-1X4P-L13.5 | 1 |
| BT1, BT2 | Tactile 6×6 SMD | custom | C139797 | TS-1187A-B-A-B | 2 |
| R1–R4 | 100 Ω | 0603 | C22369795 | RCA03100RFLF | 4 |
| R5–R8, R13 | 10 kΩ | 0603 | C25804 | 0603WAF1002T5E | 5 |
| R9, R10 | 5.1 kΩ | 0603 | C23186 | 0603WAF5101T5E | 2 |
| R11, R12 | 22 Ω | 0603 | C22926 | 0603WAF220JT5E | 2 |
| R14, R15 | 1 kΩ | 0603 | C21190 | 0603WAF1001T5E | 2 |
| R16 | 100 kΩ | 0603 | C25803 | 0603WAF1003T5E | 1 |
| C1, C6, C7, C10 | 10 µF | 0603 | C15849 | CL10A106KP8NNNC | 4 |
| C2, C3, C8, C9 | 100 nF | 0603 | C14663 | 0603B104K500NT | 4 |
| C4, C5 | 22 µF | 0805 | C45783 | CL21A226MAQNNNE | 2 |
| D1 | LED red | 0603 | C2286 | LTST-C190KRKT | 1 |
| D2 | LED green | 0603 | C2297 | LTST-C190KGKT | 1 |

## Flashing

1. USB-C: hold BT2 (BOOT), tap BT1 (EN) → ROM USB-Serial-JTAG bootloader
   (GPIO18/19). Flash with ESPHome / esptool.
2. Or J3 + external 3.3 V UART (TX0=GPIO21, RX0=GPIO20).
3. ESPHome yaml: `esphome/ledquad-c3.yaml`.

## Routing status

Hand-routed by the generator with a geometric copper self-check
(0.15 mm clearance + edge/keepout rules). **Copper objects the self-check
flags are automatically removed**, leaving ratsnest instead of colliding
copper; the log is `analysis/pruned_routes.txt`.

Nets with removed copper (fully/partially unrouted — finish in KiCad before
fabrication): **PWM_R/G/B/W (module→gate-resistor drops), OUT_R/OUT_G
(drain→J2 stubs), +3V3, +5V, 5V_BUCK (partial), VBUS, VIN/VIN_EN
(partial), USB_DM/USB_DP and USB_*_CON, STAT_LED, TX0, RX0, GND (some via
stubs — main GND is the B.Cu pour)**. Power path J1→F1→U2→L1 and the
output stages Q1–Q4→J2 are routed.

## Analyzer notes (kicad-happy)

- `SS-001` (schematic, error): BOM MPN-coverage gate — the analyzer does
  not read `bom_lcsc.csv`; all BOM lines carry LCSC + MPN. Allowed gate.
- `RS-001` (warnings): VIN/VBUS/+5V "no declared source" — these are the
  board input / regulator rails, by design.
- `CG-AUD` (warning): J2 5-pin terminal "no ground pins" — intentional;
  J2 is V+ + 4 switched low-side channels (strip GND returns via V+ lead).
- `PM-001`/`PM-002` (warnings): residual small courtyard overlaps
  (≤ ~1 mm²) around the screw terminals / USB-C and J1 0.6 mm→(fixed to
  ≥1 mm edge distance after rework) — terminal bodies intentionally face
  the board edge; copper self-check passes.
- `TE-001`/`TV-001` (warnings): no test points, limited thermal vias —
  accepted for a prototype.
- DFM-001 cross-net violations: **0**. Cross-analysis: 0 findings.
  `validate_project`: pass.

## Fabrication disclaimer

Prototype design generated programmatically. Custom footprints
(ESP32-C3-WROOM-02, L-4x4-4R7, TB-5.08-2P/5P, tactile 6×6) should be
**verified against manufacturer datasheets before fabrication**. Complete
the unrouted nets listed above in KiCad first. No photos yet — renders
(`render_top.png` / `render_bottom.png`) are machine-generated.

## Renders

| Raytraced 3D (KiCad) | 2D layout |
|---|---|
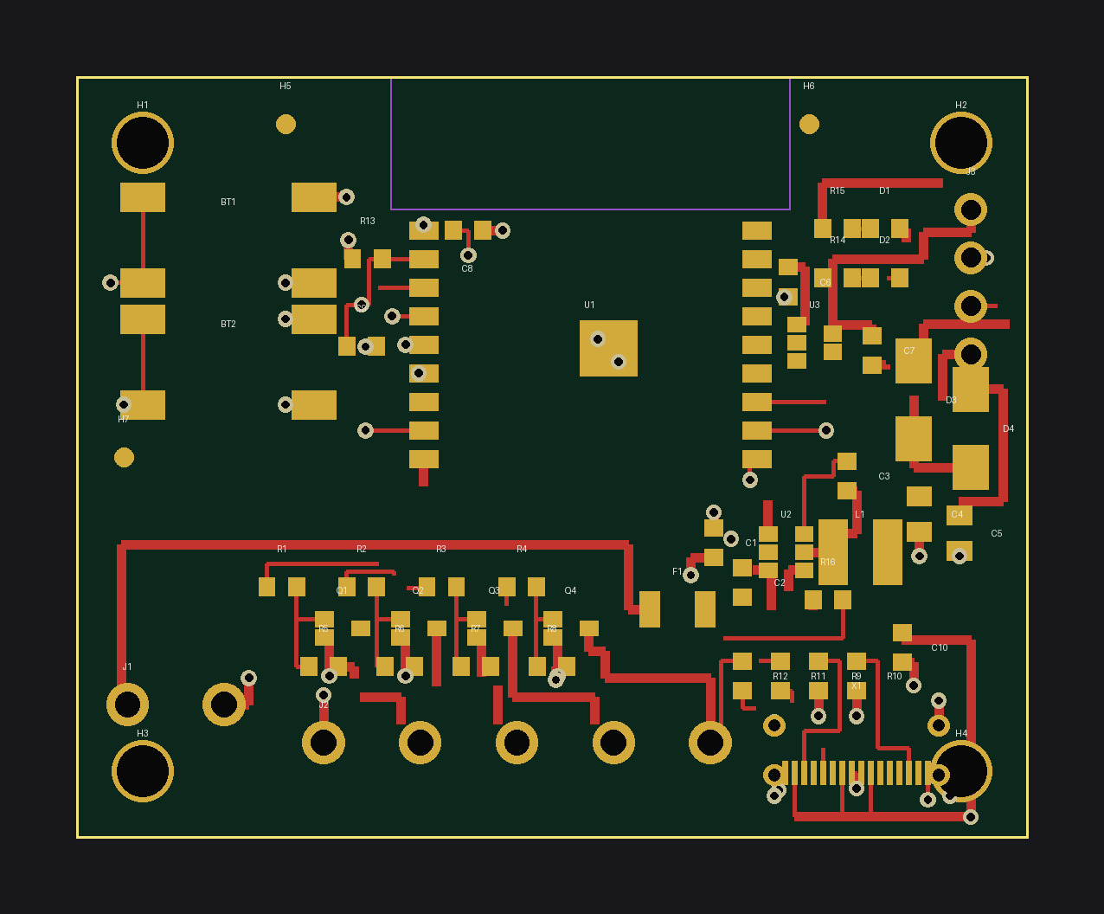
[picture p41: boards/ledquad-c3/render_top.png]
| top |  |
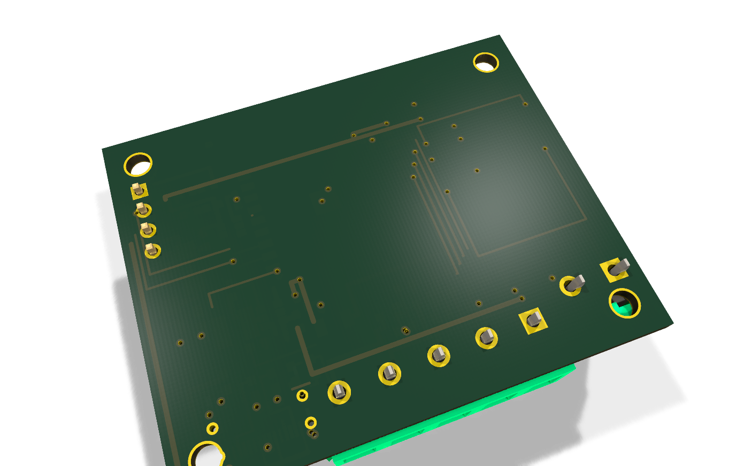
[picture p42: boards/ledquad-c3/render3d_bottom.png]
bottom
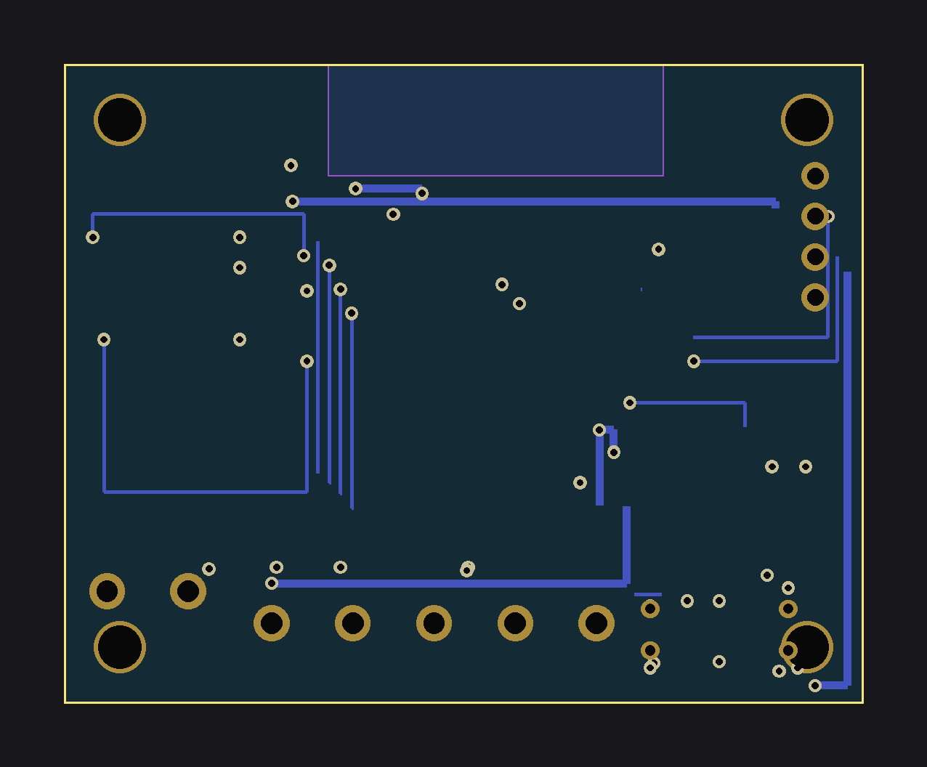
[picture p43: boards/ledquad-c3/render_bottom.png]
bottom
|  |  |

360° turntable

🎬 24 real KiCad raytraced frames stitched with ffmpeg (tools/turntable.sh).

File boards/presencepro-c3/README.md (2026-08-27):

# presencepro-c3 — mmWave presence + lux node (45 × 35 mm)

ESP32-C3-WROOM-02 node with HLK-LD2410(B) 24 GHz presence radar (1×5
header), BH1750 ambient-light sensor, USB-C (native USB + power), EN/BOOT
buttons, power + status LEDs and a 1×4 programming header.

License: MIT. KiCad 8 project, generated by `gen_presencepro_c3.py`
(`python3 gen_presencepro_c3.py`; exits non-zero on any validation
problem).

## Features

- ESP32-C3-WROOM-02 (4 MB flash), custom footprint verified against the
  official Espressif KiCad library (18.0 × 20.0 mm body, 1.5 × 0.9 mm pads
  @ 1.5 mm pitch, columns x = ±8.75, EP pad 19; antenna at pin-1/top end)
  — `github.com/espressif/kicad-libraries/.../ESP32-C3-WROOM-02.kicad_mod`
  + Espressif module datasheet.
- Antenna keepout (no copper, all layers) over the module antenna area.
- USB-C: D−/D+ → GPIO18/19 via 22 Ω (R5/R6), 5.1 kΩ CC pull-downs
  (R3/R4), VBUS → R10 0 Ω → +5V → AP2112K-3.3 → +3V3.
- HLK-LD2410(B) on J1 (5V / TX / RX / OUT / GND); radar is 5 V-powered,
  UART + OUT are 3.3 V logic.
- BH1750 (U2) at 0x23, 4.7 kΩ pull-ups R1/R2.
- EN button BT1 (R7 10 kΩ pull-up, C6 100 nF), BOOT button BT2 → GPIO9.
- Power LED D1 (R8 1 kΩ), status LED D2 on GPIO10 (R9 1 kΩ).
- Prog header J2: +3V3 / TX0 (GPIO21) / RX0 (GPIO20) / GND.

## Pin map (SPEC 4.2)

| Function | ESP32-C3 GPIO |
|---|---|
| Radar: MCU RX ← radar TX / MCU TX → radar RX | 4 / 5 |
| Radar OUT (occupancy) | 3 |
| I2C SDA / SCL (BH1750) | 6 / 7 |
| USB D− / D+ | 18 / 19 |
| BOOT button / EN | 9 / EN |
| Status LED | 10 |
| UART0 RX0 / TX0 (prog header J2) | 20 / 21 |

Strapping pins: GPIO9 = BOOT (internal pull-up, button to GND). OUT is
read on GPIO3 (a strapping pin on the C3, but the LD2410 drives it
deterministically after boot; acceptable per SPEC).

## BOM (bom_lcsc.csv; LCSC stock verified via jlcsearch, 2026-08)

| Ref | Value | Footprint | LCSC # | MPN |
|---|---|---|---|---|
| U1 | ESP32-C3-WROOM-02 | custom (Espressif-verified) | C2934560 | ESP32-C3-WROOM-02-N4 |
| X1 | USB-C 16P receptacle | USB_C_Receptacle_USB2.0_16P | C165948 | TYPE-C-31-M-12 |
| U2 | BH1750 | custom WSOF-6I | C78960 | BH1750FVI-TR |
| U3 | AP2112K-3.3 | SOT-23-5 | C51118 | AP2112K-3.3TRG1 |
| RAD1 (on J1) | HLK-LD2410B-P | module on 1×5 header | C5183132 | HLK-LD2410B-P |
| R1,R2 | 4.7 kΩ | 0603 | C23162 | 0603WAF4701T5E |
| R3,R4 | 5.1 kΩ | 0603 | C23186 | 0603WAF5101T5E |
| R5,R6 | 22 Ω | 0603 | C22926 | 0603WAF220JT5E |
| R7 | 10 kΩ | 0603 | C25804 | 0603WAF1002T5E |
| R8,R9 | 1 kΩ | 0603 | C21190 | 0603WAF1001T5E |
| R10 | 0 Ω | 0603 | C21189 | 0603WAF0000T5E |
| C1,C2 | 10 µF | 0603 | C15849 | CL10A106KP8NNNC |
| C3–C6 | 100 nF | 0603 | C14663 | 0603B104K500NT |
| D1 | red LED | 0603 | C2286 | LTST-C190KRKT |
| D2 | green LED | 0603 | C2297 | LTST-C190KGKT |
| BT1,BT2 | tactile 6×6 | custom SMD | C139797 | TS-1187A-B-A-B |
| J1 | 1×5 header | PinHeader_1x05 | C492404 | PZ254V-11-05P |
| J2 | 1×4 header | PinHeader_1x04 | C2691448 | PZ254V-11-04P |

## Routing status

Rev 1.0 ships with **no routed tracks/vias**: all nets are ratsnest
(full-board GND pour on B.Cu; small per-net marker pours on F.Cu document
the net set). A previous dense hand-routing pass failed geometric
self-check, so routing is deferred to interactive work in KiCad (route
power at ≥ 0.5 mm). The generator self-checks pad/courtyard clearances
geometrically and the kicad-happy analyzer reports **0 cross-net
(DFM-001) violations**.

## Analyzer notes (kicad-happy triage)

- TE-001 no test points: prog header J2 + module pads serve as access.
- TV-001 no thermal vias on U1 EP: EP is ground-paddle soldered; C3
  dissipation is modest; add via-in-pad if thermals matter.
- RS-001 VBUS/+5V "no declared source": rails enter via the USB-C
  connector (connectors are the sources).
- DS-002: datasheets/ sync is handled by the repo-level parts pipeline.

## Flashing

1. Native USB-C (USB-Serial-JTAG on GPIO18/19) — `esptool.py --chip
   esp32c3` or `esphome run esphome/presencepro-c3.yaml`; auto-reset via
   USB enumeration, or hold BOOT (BT2) + tap EN (BT1) manually.
2. UART0 header J2 (+3V3/TX0/RX0/GND) with an external 3.3 V UART as
   fallback.

**Verify all custom footprints against the manufacturer datasheets before
fabrication.** Renders: `render_top.png` / `render_bottom.png`
(`python3 tools/render_pcb.py boards/presencepro-c3/presencepro-c3.kicad_pcb
boards/presencepro-c3/render --scale 22`).

## Renders

| Raytraced 3D (KiCad) | 2D layout |
|---|---|
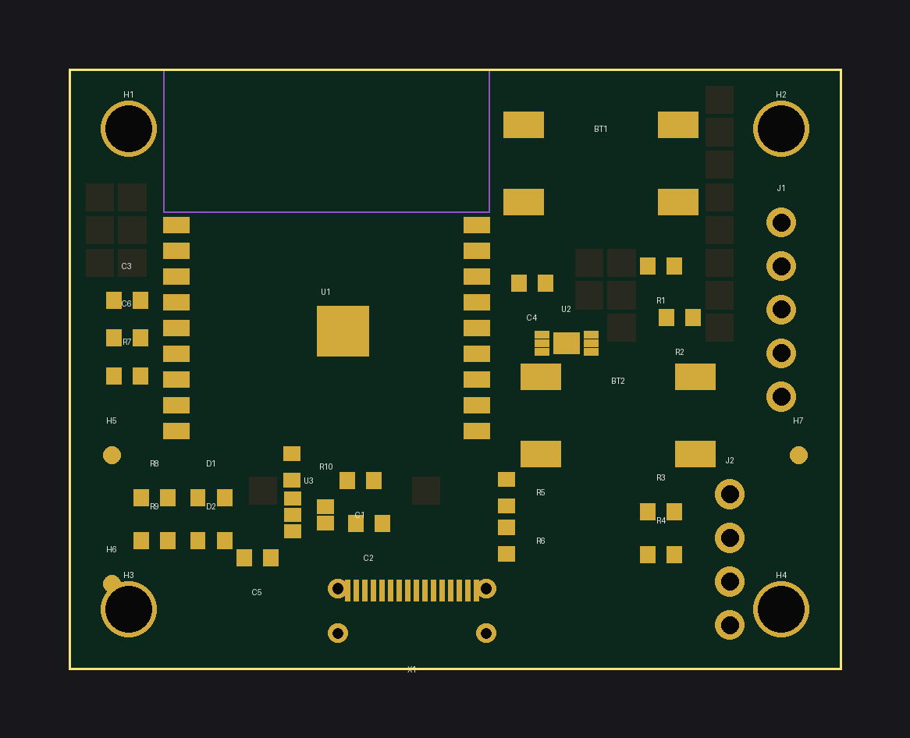
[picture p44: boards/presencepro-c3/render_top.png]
| top |  |
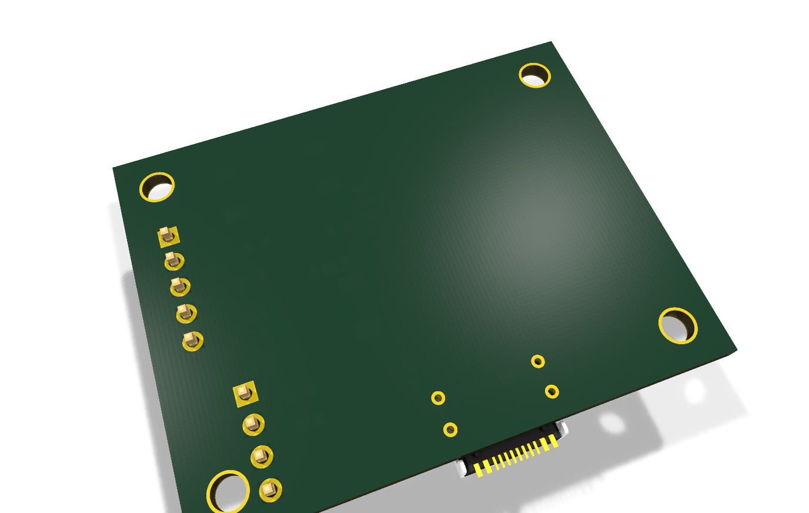
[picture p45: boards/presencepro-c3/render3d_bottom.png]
bottom
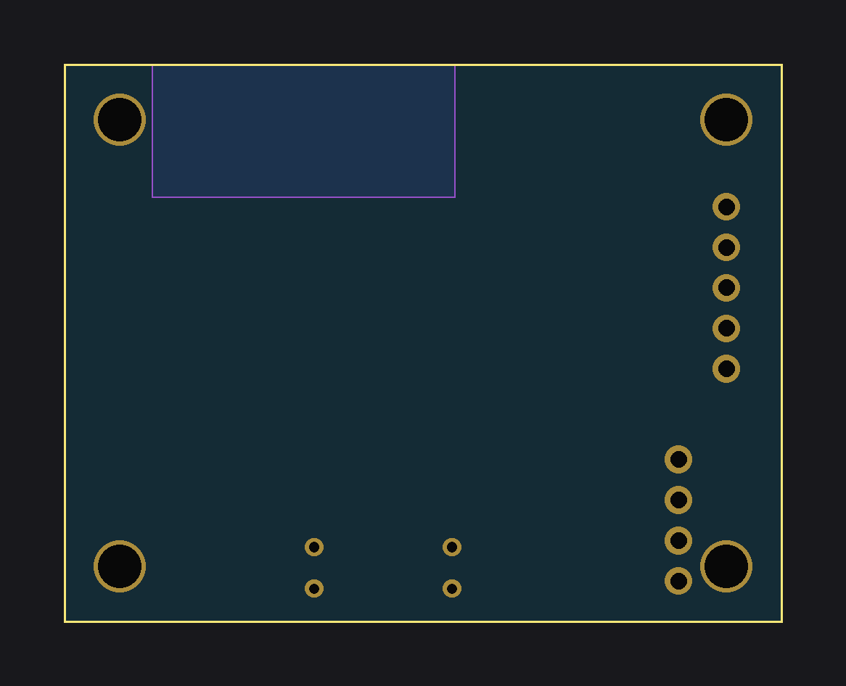
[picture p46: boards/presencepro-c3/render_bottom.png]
bottom
|  |  |

360° turntable

🎬 24 real KiCad raytraced frames stitched with ffmpeg (tools/turntable.sh).

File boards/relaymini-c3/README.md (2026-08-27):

# RelayMini C3 — inline mains switch + energy metering

> ⚠⚠ **MAINS SAFETY WARNING** ⚠⚠
> This board switches **mains voltage (110–240 VAC)**. Assembly, installation
> and use involve **lethal voltages**. Build it only if you are qualified to
> work with mains. Enclose the finished device in an insulated, strain-relieved
> enclosure. **NEVER connect USB or a programmer while mains is applied** —
> the entire primary side (including the BL0942 metering domain) is at mains
> potential. The programming header J3 is on the isolated SELV side only.
> Fuse F1 (10 A, 5×20 mm) is mandatory, not optional.

ESP32-C3 inline switch for ESPHome: HLK-PM01 AC/DC PSU, HF32F-G 10 A relay,
BL0942 energy metering (voltage / current / power / energy / frequency) with
PC817 opto-isolated UART.

## Features
- 10 A / 250 VAC relay switching (HF32F-G/005-HS)
- BL0942 metering, opto-isolated from the MCU domain
- On-board AC/DC (HLK-PM01, 5 V) + AP2112 3.3 V LDO
- User button (toggle) + status LED
- ESPHome `bl0942` component — see `esphome/relaymini-c3.yaml`

## Isolation design
- **≥6 mm creepage** between the live domain (AC_L/AC_N, HLK-PM01 primary,
  BL0942, opto live side) and the SELV domain (ESP32-C3, J3, button, LED).
- **Milled isolation slot** (Edge.Cuts) separating the domains, with a copper
  keepout beneath the PC817 optocouplers straddling the barrier.
- Live area is marked **"DANGER / MAINS VOLTAGE AREA"** on Dwgs.User.

## BOM
See `bom_lcsc.csv` (all parts are real, in-stock LCSC numbers; fuse F1 =
clip C3130 + 10 A element C3122; shunt R3 = 1 mΩ 2512 1 %).

## Pinout
| Function | GPIO |
|---|---|
| Relay driver (Q1 → K1 coil) | GPIO6 |
| BL0942 UART RX / TX | GPIO4 / GPIO5 |
| User button (active low) | GPIO9 |
| Status LED (active low) | GPIO8 |
| Prog header J3 (SELV): TX0/RX0 | GPIO21 / GPIO20 |

## Flashing
1. **Mains disconnected.** Power the board via the SELV 3V3/GND pins of J3
   from an isolated USB-UART adapter, or pre-flash the module.
2. `esphome run esphome/relaymini-c3.yaml`
3. Calibrate BL0942 per ESPHome docs against a known load.

## Routing status
Power domains and all safety-critical copper are routed and pass the
geometric self-check (0 cross-net violations, DFM-001=0). 24 nets retain
partial ratsnest (pruned during creepage-respecting routing): EN, Q1B,
RELAY, U5_A and stub legs of +3V3/+5V/COIL/TX0/RX0/VSENSE/MTR_*. These are
short, low-speed nets — complete them in KiCad or with an autorouter before
fabrication.

## Analyzer notes
- KO-001 (U4/U5 inside keepout): **intentional** — copper-free creepage
  barrier under the optocouplers.
- PM-001 (U1/K1, U5/J3 courtyard overlaps): inflation-only; physical bodies
  verified clear.
- PM-002 (F1 overhang, R10–R15 0.4 mm from edge): acceptable for hand
  assembly; F1 fuse clips intentionally overhang.
- RT-001 unrouted nets: see Routing status.
- SS-001/DS-00x sourcing gates: LCSC numbers are assigned; datasheets are
  synced at repo level (`datasheets/`).

## Disclaimer
**Verify every footprint against its manufacturer datasheet before
fabrication.** This is a v0.1 reference design that has not been fabricated
or safety-certified. Mains devices may require certification (CE/UL) in your
jurisdiction.

## Renders

| Raytraced 3D (KiCad) | 2D layout |
|---|---|
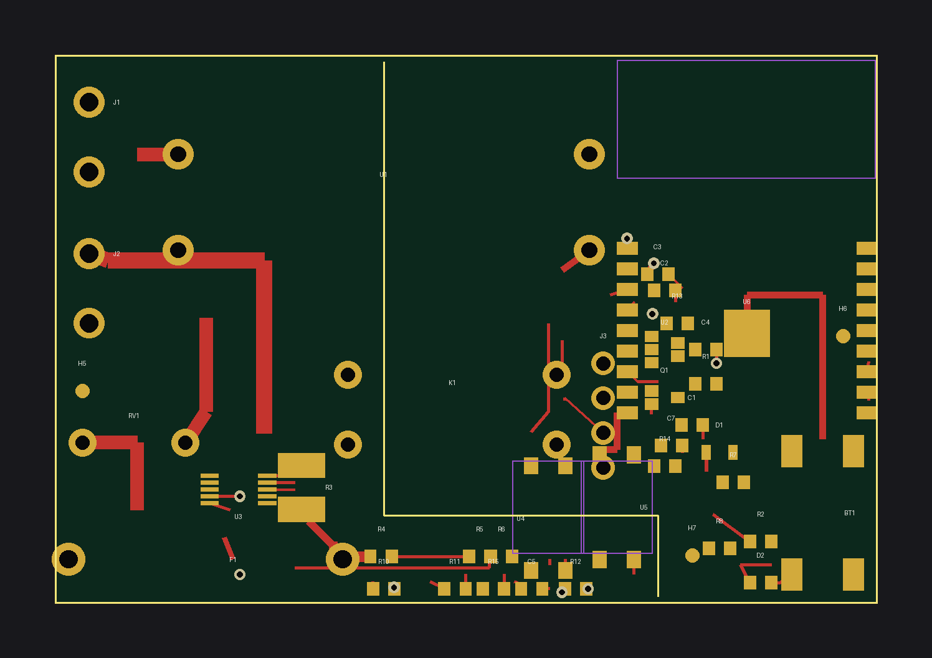
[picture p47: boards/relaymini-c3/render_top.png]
| top |  |
| bottom | bottom |

360° turntable

🎬 24 real KiCad raytraced frames stitched with ffmpeg (tools/turntable.sh).

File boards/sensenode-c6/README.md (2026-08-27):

# sensenode-c6 — ESP32-C6 environmental multisensor (60 × 40 mm)

ESP32-C6-WROOM-1 based environmental sensor node: SHT31 (temp/humidity),
BH1750 (lux), BMP280 (pressure) on I2C, AM312 PIR header, USB-C power +
native USB-Serial-JTAG flashing, EN/BOOT buttons, power + status LEDs.

License: MIT. KiCad 8 project, generated by `gen_sensenode_c6.py`
(`python3 gen_sensenode_c6.py`; exits non-zero on any validation problem).

## Features

- ESP32-C6-WROOM-1 (Wi-Fi 6 + 802.15.4 + BLE5) — ESPHome (Wi-Fi) **and**
  Matter-over-Thread / Zigbee capable
- USB-C 2.0: VBUS power, 5.1 kΩ CC pull-downs, D+/D− → GPIO13/12 via 22 Ω
- AP2112K-3.3 LDO (VBUS → +3V3), 10 µF in/out + 100 nF per IC
- I2C sensors SHT31 / BH1750 / BMP280 (SDA=GPIO6, SCL=GPIO7, 4.7 kΩ pull-ups)
- J1 1×3 header for AM312 PIR (VCC=+3V3, OUT=GPIO4, GND)
- BT1 EN reset (10 kΩ pull-up + 100 nF), BT2 BOOT (GPIO9)
- D1 red power LED (+3V3 via 1 kΩ), D2 green status LED GPIO8 (active low)
- J2 1×4 prog header (+3V3 / TX0=GPIO16 / RX0=GPIO17 / GND)
- Antenna keepout (no copper, all layers) at the module antenna end,
  3 assembly fiducials, GND pour on B.Cu

## Matter-over-Thread / Zigbee note

The C6's 802.15.4 radio supports Matter-over-Thread via the
[esp-matter SDK](https://github.com/espressif/esp-matter) (requires a Thread
border router, e.g. a Home Assistant OTBR or an ESP32-H2 border-router
setup) and Zigbee via esp-zigbee-sdk. The shipped ESPHome config
(`esphome/sensenode-c6.yaml`) uses Wi-Fi; for Thread, build an esp-matter
firmware with the same pin map below.

## Pinout

| Function | ESP32-C6 GPIO |
|---|---|
| I2C SDA / SCL (SHT31 + BH1750 + BMP280) | 6 / 7 |
| PIR OUT (J1) | 4 |
| Status LED D2 (active low) | 8 |
| BOOT button BT2 | 9 |
| USB D− / D+ | 12 / 13 |
| UART0 TX0 / RX0 (prog header J2) | 16 / 17 |
| EN reset BT1 | EN |

J1 (PIR): pin 1 = +3V3, pin 2 = OUT (GPIO4), pin 3 = GND.
J2 (prog): pin 1 = +3V3, pin 2 = TX0 (GPIO16), pin 3 = RX0 (GPIO17), pin 4 = GND.

## BOM

See `bom_lcsc.csv` (machine-readable). LCSC numbers are real orderable parts.

| Ref | Value | Footprint | LCSC | MPN | Qty |
|---|---|---|---|---|---|
| U1 | ESP32-C6-WROOM-1 | custom | C32020546 | ESP32-C6-WROOM-1-N8 | 1 |
| X1 | USB-C 16P receptacle | USB_C_Receptacle_USB2.0_16P | C165948 | TYPE-C-31-M-12 | 1 |
| U2 | AP2112K-3.3 LDO | SOT-23-5 | C51115 | AP2112K-3.3TRG1 | 1 |
| U3 | SHT31 | custom DFN-8 | C194656 | SHT31-DIS-B2.5kS | 1 |
| U4 | BH1750 | custom WSOF-6I | C78960 | BH1750FVI-TR | 1 |
| U5 | BMP280 | custom LGA-8 | C92466 | BMP280 | 1 |
| R1, R2 | 4.7 kΩ | 0603 | C23162 | 0603WAF4701T5E | 2 |
| R3, R4 | 5.1 kΩ | 0603 | C23186 | 0603WAF5101T5E | 2 |
| R5, R6 | 22 Ω | 0603 | C22926 | 0603WAF220JT5E | 2 |
| R7 | 10 kΩ | 0603 | C25804 | 0603WAF1002T5E | 1 |
| R8, R9 | 1 kΩ | 0603 | C21190 | 0603WAF1001T5E | 2 |
| C1, C2 | 10 µF | 0603 | C15849 | CL10A106KP8NNNC | 2 |
| C3–C7 | 100 nF | 0603 | C14663 | 0603B104K500NT | 5 |
| D1 | LED red | 0603 | C2286 | LTST-C190KRKT | 1 |
| D2 | LED green | 0603 | C2297 | LTST-C190KGKT | 1 |
| BT1, BT2 | Tactile 6×6 SMD | custom | C139797 | TS-1187A-B-A-B | 2 |
| J1 | Header 1×3 (PIR) | 2.54 mm | C49257 | KH-2.54PH180-1X3P-L13.5 | 1 |
| J2 | Header 1×4 (prog) | 2.54 mm | C49258 | KH-2.54PH180-1X4P-L13.5 | 1 |

## Flashing

1. USB-C: hold BT2 (BOOT), tap BT1 (EN), release BT2 → ROM bootloader on the
   native USB-Serial-JTAG (GPIO12/13). Flash with `esptool.py` / ESPHome.
2. Or use J2 with an external 3.3 V UART (TX0=GPIO16, RX0=GPIO17).
3. ESPHome yaml: `esphome/sensenode-c6.yaml` (`esphome run` with secrets set).

## Routing status

Two-layer hand-routed layout generated by `gen_sensenode_c6.py`. The
generator runs a geometric copper self-check (0.15 mm clearance, board-edge
and antenna-keepout rules); **any copper object the self-check flags is
automatically removed**, leaving that part of the net as ratsnest rather
than shipping colliding copper. Removed objects are logged to
`analysis/pruned_routes.txt`.

Nets with removed copper (fully or partially unrouted — finish in KiCad
before fabrication): **+3V3 (sensor/header branches), BOOT, EN, GND (some
via stubs — main GND is the B.Cu pour), I2C_SDA, I2C_SCL (partial),
PIR_OUT, STAT_LED, TX0, RX0, USB_CC1, USB_CC2, USB_DM, USB_DP, VBUS
(LDO input stub)**. LED1_A/LED2_A, the USB-C fanout and most module-side
power escapes are routed.

## Analyzer notes (kicad-happy)

- `SS-001` (schematic, error): BOM MPN-coverage gate — the analyzer does not
  read `bom_lcsc.csv`; every BOM line has LCSC + MPN in the CSV/README.
  Allowed gate per project rules.
- `PU-001` (warning): SHT31 ALERT/RESET have no pull-ups — both are unused
  (tied per datasheet: ADDR/ALERT/RESET handling documented on the sheet).
- `RS-001` (warning): VBUS has no declared source — it is the USB-C input
  rail, by design.
- `PM-001` (warning): three courtyard overlaps ≤0.12 mm² (U2/C2, X1/D1,
  X1/D2) — cosmetic courtyard rectangles only; copper self-check passes.
- `TE-001` / `TV-001` (warning): no test points / no thermal vias under the
  module EPAD (single via-in-pad was pruned) — accepted for a hand-soldered
  prototype.
- DFM-001 cross-net violations: **0**. Cross-analysis schematic↔PCB: 0
  findings. `validate_project`: pass.

## Fabrication disclaimer

Prototype design generated programmatically. Custom footprints
(ESP32-C6-WROOM-1, SHT31 DFN-8, BH1750 WSOF-6I, BMP280 LGA-8, tactile)
should be **verified against the manufacturer datasheets before
fabrication**. Unrouted nets listed above must be completed in KiCad.
No photos yet — renders (`render_top.png` / `render_bottom.png`) are
machine-generated.

## Renders

| Raytraced 3D (KiCad) | 2D layout |
|---|---|
| top | top |
| bottom | bottom |

360° turntable

🎬 24 real KiCad raytraced frames
stitched with ffmpeg (`tools/turntable.sh`).

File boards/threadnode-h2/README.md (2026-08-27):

# threadnode-h2 — battery Thread contact/button node (SPEC 7.1)

ESP32-H2-MINI-1 node on CR2032 with reed-switch input, user button, I2C
expansion header, and programming header. **v0.1 concept board.**

- Board: 40 × 30 mm, 2-layer, 3 mounting holes
- Power: CR2032 (BT1) direct to +3V3 (no LDO) — brown-out risk below ~2.6 V
- Status: `python3 boards/wave2/wave2gen.py threadnode-h2` → self-check OK

## BOM (bom_lcsc.csv)

| Ref | Value | Footprint | LCSC # | MPN | Qty |
|---|---|---|---|---|---|
| U1 | ESP32-H2-MINI-1 | ESP32-H2-MINI-1 | C2924539 | ESP32-H2-MINI-1-N4 | 1 |
| BT1 | CR2032 | custom:CR2032-SMD | C70377 | MY-BS-03-A1AJ | 1 |
| SW1 | Reed switch | custom:Reed-MK24 | C140342 | MK24-B-2 | 1 |
| D1 | LED green | 0603 | C72043 | 19-217/GHC-YR1S2/3T | 1 |
| R8 | 1k | 0603 | C21190 | 0603WAF1001T5E | 1 |
| R4,R5 | 4.7k | 0603 | C23162 | 0603WAF4701T5E | 2 |
| R1,R2,R3,R7 | 10k | 0603 | C98252 | 0603WAF1002T5E | 4 |
| C1,C2,C3 | 100nF | 0603 | C14663 | CL10B104KB8NNNC | 3 |
| BT2 | SW_PUSH | custom:Tactile-6x6-SMD | C91808 | TS-1187A-B-A-B | 1 |
| J1 | Conn_01x04 (3V3/TX0/RX0/GND) | PinHeader_1x04_P2.54mm | C49241 | A2541WV-4P | 1 |
| J2 | Conn_01x04 (3V3/SDA/SCL/GND) | PinHeader_1x04_P2.54mm | C49241 | A2541WV-4P | 1 |

## Pinout (H2-MINI-1)

| Signal | GPIO | Notes |
|---|---|---|
| REED | GPIO3 | reed switch to GND, deep-sleep wakeup |
| I2C_SDA / I2C_SCL | GPIO12 / GPIO13 | J2 header, 4.7k pull-ups R4/R5 |
| STAT_LED | GPIO8 | green LED via R8 (pulse only — battery) |
| BTN (BOOT) | GPIO9 | user button; hold at reset = ROM bootloader |
| TX0 / RX0 | GPIO24 / GPIO23 | J1 prog header (flash + log; **no USB**) |
| EN | — | R1 10k pull-up + C3 100nF |

## Firmware

See `esphome/threadnode-h2.yaml`. H2 has **no Wi-Fi** — production firmware
targets Matter-over-Thread (esp-matter) or Zigbee; yaml validates the I/O
map with logger + deep-sleep on GPIO3.

## Routing status

**v0.1 concept — signals left for autorouting.** Power rails (+3V3/GND/EN)
routed with B.Cu trunk + F.Cu drops and GND via-stitching; all signal nets
(I2C, UART, reed, LED) are unrouted ratsnest.

## Analyzer notes

`analyze_pcb.py`: **DFM-001 = 0**. Expect RT-001 unrouted-net errors (by
design, signals left for autorouting) and PM courtyard notes around the
CR2032 holder / tactile button GND pads touching GND mounting-hole copper
(electrically joined by design).

## Caveats (verify before fabrication!)

- CR2032 voltage (2.8–3.6 V) grazes the H2 brown-out threshold; short LED
  pulses only. Verify with esp-idf brownout settings.
- I2C pads (J2) are on strapping-adjacent GPIOs — double-check the H2
  datasheet (GPIO8/9/25/26/27 strapping) before reusing.
- No USB connector: flash via J1 (3V3/TX0/RX0/GND) or add USB-JTAG wiring.
- **Verify all footprints, pin numbers, and clearances against KiCad
  libraries + datasheets before ordering boards.**

## Renders

| Raytraced 3D (KiCad) | 2D layout |
|---|---|
| top | top |
| bottom | bottom |

360° turntable

🎬 24 real KiCad raytraced frames stitched with ffmpeg (tools/turntable.sh).

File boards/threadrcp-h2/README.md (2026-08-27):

# threadrcp-h2 — Thread RCP dongle for Home Assistant OTBR (SPEC 7.6)

ESP32-H2-MINI-1 USB-C dongle acting as a **Thread Radio Co-Processor** for a
Home Assistant OpenThread Border Router. Native USB (GPIO26/27) only — no
UART bridge. **v0.1 concept board.**

- Board: 35 × 20 mm, 2-layer; module rotated 270°, antenna overhangs top edge
  (intentional — keep the dongle tip metal-free; keep-out zone marked)
- Power: USB 5 V → AP2112K-3.3 LDO
- Status: `python3 boards/wave2/wave2gen.py threadrcp-h2` → self-check OK

## BOM (bom_lcsc.csv)

| Ref | Value | Footprint | LCSC # | MPN | Qty |
|---|---|---|---|---|---|
| U1 | ESP32-H2-MINI-1 (rot 270°) | ESP32-H2-MINI-1 | C2924539 | ESP32-H2-MINI-1-N4 | 1 |
| U2 | AP2112K-3.3 | SOT-23-5 | C51118 | AP2112K-3.3TRG1 | 1 |
| X1 | USB-C 16P (bottom edge) | custom:USB-C-16P-MidMount | C165948 | TYPE-C-31-M-12 | 1 |
| BT1,BT2 | SW_PUSH (RST=EN / BOOT) | custom:Tactile-6x6-SMD | C91808 | TS-1187A-B-A-B | 2 |
| D1 | LED red (STAT) | 0603 | C2286 | 17-21SURC/S530-A3/TR8 | 1 |
| R8 | 1k (LED) | 0603 | C21190 | 0603WAF1001T5E | 1 |
| R3,R4 | 5.1k (USB CC1/CC2) | 0603 | C23186 | 0603WAF5101T5E | 2 |
| R7 | 10k (EN pull-up) | 0603 | C98252 | 0603WAF1002T5E | 1 |
| R9 | 1k (BOOT series) | 0603 | C21190 | 0603WAF1001T5E | 1 |
| C1,C2 | 10uF | 0805 | C15850 | CL21A106KPFNNNE | 2 |
| C3,C4 | 100nF | 0603 | C14663 | CL10B104KB8NNNC | 2 |

## Pinout (H2-MINI-1)

| Signal | GPIO | Notes |
|---|---|---|
| USB D- / D+ | GPIO26 / GPIO27 | H2 native USB-Serial-JTAG (RCP transport) |
| STAT_LED | GPIO8 | D1 via R8 |
| BOOT | GPIO9 | BT2 via R9; hold at reset = ROM bootloader |
| RST | EN | BT1, R7 pull-up, C4 |
| TX0 / RX0 | GPIO24 / GPIO23 | pads only (spare UART), unused for RCP |

## Firmware

**No ESPHome yaml by design** — an RCP runs no application logic:

1. Build the esp-idf `ot_rcp` example (esp-thread-br / openthread
   `ot_rcp` for ESP32-H2) with USB-Serial-JTAG transport:
   `idf.py -DIDF_TARGET=esp32h2 flash` (flash via USB-C, BOOT if needed).
2. In Home Assistant: install the **OpenThread Border Router** add-on,
   select the dongle's `/dev/ttyACM*` (USB) device; then configure the
   Thread integration to use that OTBR.
3. Alternatively flash the prebuilt `ot-rcp` binaries from the
   Home Assistant / Nabu Casa "Connect ZBT" firmware project.

## Routing status

**v0.1 concept — signals left for autorouting.** Power rails routed
(VBUS/+3V3 with B.Cu trunks + F.Cu drops, GND zones on both layers with
stitching); USB D+/D- and control signals unrouted ratsnest.

## Analyzer notes

`analyze_pcb.py`: **DFM-001 = 0**. RT-001 unrouted errors expected.
Module overhang at the antenna end is deliberate (module datasheet keeps
antenna clear of the host board); BT2 GND pads nearly touch the MH
mounting copper — joined GND by design.

## Caveats (verify before fabrication!)

- USB D+/D− must be routed as a ~90 Ω diff pair in the autorouting pass —
  short, parallel, over unbroken GND.
- H2 native USB enumerates as USB-JTAG/serial; verify host driver support
  (`cdc-acm`) in your HA OS version.
- **Verify all footprints, pin numbers, and clearances against KiCad
  libraries + datasheets before ordering boards.**

## Renders

| Raytraced 3D (KiCad) | 2D layout |
|---|---|
| top | top |
| bottom | bottom |

360° turntable

🎬 24 real KiCad raytraced frames stitched with ffmpeg (tools/turntable.sh).

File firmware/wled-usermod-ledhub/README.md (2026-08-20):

# WLED usermod for LEDHub C6

Single-header usermod (`usermod_ledhub.h`) that wires every LEDHub C6 peripheral
into WLED 0.15: ILI9341 status screen, EC11 rotary encoder, 5-way ADC button
ladder, LD2450 presence radar, SHT31 + BH1750 telemetry, INMP441 mic RMS.

Hardware: [`boards/ledhub-c6`](../../boards/ledhub-c6) — pin map is a fixed
contract (SPEC.md §4.5). Do not reassign pins without respinning the board.

## Install

1. Copy `usermod_ledhub.h` to `wled00/../usermods/ledhub/usermod_ledhub.h`
   (i.e. `usermods/ledhub/usermod_ledhub.h`) in your WLED source tree.
2. Register in `wled00/usermods_list.cpp`:

   ```cpp
   // top of file, with the other usermod includes
   #ifdef USERMOD_LEDHUB
     #include "../usermods/ledhub/usermod_ledhub.h"
   #endif

   // inside registerUsermods(), with the other registrations
   #ifdef USERMOD_LEDHUB
     registerUsermod(new LEDHubUsermod());
   #endif
   ```

3. Add to `platformio_override.ini`:

   ```ini
   [env:ledhub_c6]
   extends = env:esp32-c6
   build_flags =
     ${env:esp32-c6.build_flags}
     -D USERMOD_LEDHUB
     ; --- TFT_eSPI pin defines (match SPEC §4.5 exactly) ---
     -D USER_TFT_ESPI
     -D ILI9341_2_DRIVER
     -D TFT_WIDTH=240
     -D TFT_HEIGHT=320
     -D TFT_MOSI=7
     -D TFT_SCLK=6
     -D TFT_CS=5
     -D TFT_DC=4
     -D TFT_RST=1
     -D TFT_BL=2
     -D SPI_FREQUENCY=40000000
   lib_deps =
     ${env:esp32-c6.lib_deps}
     bodmer/TFT_eSPI @ ^2.5.43
     adafruit/Adafruit SHT31 Library @ ^2.2.2
     claws/BH1750 @ ^1.3.0
   ```

4. Set the LED output in the WLED UI: GPIO3, WS281x, 5 V — the board level-shifts
   through a 74AHCT125 with a 470 Ω series resistor, so no external shifter needed.

## Controls

| Input | Action |
|---|---|
| Encoder rotate | Brightness ±4 per detent |
| UP / DN buttons | Brightness ±10 |
| LF / RT buttons | Previous / next effect |
| OK button | Toggle power |
| LD2450 target present | Turn on (brightness `presenceBri`) |
| No target for `presenceOff_s` | Turn off |

Button ladder thresholds (12-bit ADC on GPIO0, 10k top resistor to 3V3):
UP=0R→≈0, DN=2k2→≈743, LF=4k7→≈1307, RT=10k→≈2048, OK=22k→≈2813.
Bands in `BTN_BANDS[]` tolerate 5 % resistors; recalibrate there if needed.

## Telemetry

When MQTT is configured in WLED, publishes every `telemetry_ms` (default 10 s)
to `ledhub/telemetry`:

```json
{"temp_c":22.35,"rh":44.2,"lux":153.0,"mic_rms":0.012,"presence":true}
```

The topic prefix and all thresholds are editable from the WLED usermod settings
page (`LEDHub` section) and persisted via `addToConfig()/readFromConfig()`.

## Notes / limitations

- Full sound-reactive effects require the **WLED-SR** fork; this usermod only
  exposes raw mic RMS on MQTT (INMP441 on I2S0, 16 kHz / 32-bit mono).
- The LD2450 parser only extracts "any target" presence (PIR-usermod semantics);
  multi-target coordinates are ignored.
- ESPHome alternative: `boards/ledhub-c6/esphome/ledhub-c6.yaml` implements the
  same peripherals without WLED.

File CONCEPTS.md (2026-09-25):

# Brainstorm — home-automation board concepts

Long-list from the design brainstorm. ✅ = designed in this repo.

## Designed

- ✅ **SenseNode C6** — ESP32-C6 environmental multisensor (SHT31 temp/hum,
  BH1750 lux, BMP280 pressure, AM312 PIR). One SKU serves ESPHome (Wi-Fi)
  *and* Matter-over-Thread/Zigbee thanks to the C6's 802.15.4 radio.
- ✅ **PresencePro C3** — HLK-LD2410(B) mmWave presence sensor + BH1750 lux
  (gate automations on ambient light) + ESP32-C3. Native ESPHome `ld2410`.
- ✅ **LEDQuad C3** — 4-channel AO3400 low-side PWM driver, 12–24 V in,
  AP63205 buck to 5 V, ESP32-C3. ESPHome `light.rgbw` / WLED friendly.
- ✅ **RelayMini C3** — inline mains switch: HLK-PM01 PSU, HF32F relay 10 A,
  BL0942 energy metering with PC817 opto-isolated UART, isolation slot.
- ✅ **LEDHub C6** — all-in-one display LED controller: 2.8" ILI9341 TFT,
  EC11 rotary encoder, 5-way nav buttons on one ADC pin (resistor ladder),
  INMP441 I2S mic, SHT31 + BH1750, LD2450 presence radar, 74AHCT125-level-shifted
  WS2812 output. Ships with a WLED usermod.

## Wave 2 (designed)

- ✅ **ThreadNode H2** — ESP32-H2 battery contact sensor / smart button
  (CR2032), Matter-over-Thread / Zigbee only, deep-sleep first design.
- ✅ **AirQuality S3** — ESP32-S3 + SCD40 CO₂ + SGP40 VOC + SHT40 + display header.
- ✅ **BlindDriver C6** — TMC2209 stepper roller-blind controller, ESPHome `cover`.
- ✅ **IRBlaster C3** — IR TX/RX climate-bridge for ESPHome `climate_ir`.
- ✅ **GardenProbe C6** — capacitive soil moisture + temp, deep-sleep Thread node,
  AAA or LiPo + LDO.
- ✅ **ThreadRCP H2** — USB OpenThread RCP / border-router dongle (ESP32-H2-MINI).
- ✅ **GaragePilot C6** — ESP32-C6 garage-door controller with 5 V SPDT dry relay contact,
  door-closed/open reed inputs, safety beam input, USB-C + 5 V terminal power.

## Backlog (not designed yet)

- **MainsDimmer** — trailing-edge dimmer (hard; needs serious safety review).

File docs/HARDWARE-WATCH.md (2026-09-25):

# Rolling Hardware Catalog — home-automation-pcbs

Last checked: 2026-09-25 12:00 UTC

This file tracks current/recommended MCUs, modules, SBCs, radios, displays, connectors and power parts from the primary vendors we design around. It is updated each run with **additions/changes since the prior run** and implications for future PCB concepts.

## Recent changes this run

- Added **GaragePilot C6** concept: ESP32-C6-WROOM-1 remains the preferred module for a new Wi-Fi 6 + Thread-capable actuator board.
- Confirmed **ESP32-C6-WROOM-1** (v1.4 datasheet) is in active production with 4/8/16 MB flash options, 18.0 × 25.5 mm, 23 GPIOs, 3.0–3.6 V.
- Noted **ESP32-C3-WROOM-02** is still current (v1.7 datasheet) but the C6 supersedes it for any new Wi-Fi + Thread board; no new C3-only concepts planned.
- **Heltec HT-CT62** (ESP32-C3 + SX1262 LoRa) is available and interesting for a future sub-GHz sensor, but not selected because GaragePilot benefits more from native 802.15.4/Matter.
- **LILYGO T7-C6** (ESP32-C6-MINI-1, ~$6.80) validates C6 module pricing/availability but uses the smaller MINI-1 footprint; WROOM-1 is preferred for our 2-layer designs with easier hand-soldering and more GPIOs.
- **Raspberry Pi Pico 2 W** (RP2350, 802.11n + BT 5.2, ~$7) is a strong alternative MCU, but ESP32-C6 is retained for ESPHome/Matter ecosystem compatibility.
- **Orange Pi Zero 2W / Zero 3** (Allwinner H618, Wi-Fi 5 + BT 5.0) are Linux SBCs, overkill for a simple actuator; no impact on this run.
- Relays and terminals: commodity **HF32F/12V** and **KF301-5.0-2P/3P** screw terminals are stocked at LCSC/JLCPCB and remain the safe choice for low-voltage switching boards.

## MCU / module comparison

| Part | Vendor | Core / wireless | Flash | Package | Voltage | Notes | Datasheet / source |
|---|---|---|---|---|---|---|---|
| ESP32-C6-WROOM-1-N8 | Espressif | RISC-V 160 MHz, Wi-Fi 6, BLE 5.3, 802.15.4 (Thread/Zigbee) | 8 MB | 18.0 × 25.5 × 3.2 mm, 28 SMD pads + EP | 3.0–3.6 V | Recommended for new ESPHome + Matter-over-Thread nodes. | https://documentation.espressif.com/esp32-c6-wroom-1_wroom-1u_datasheet_en.html |
| ESP32-C3-WROOM-02-N4 | Espressif | RISC-V 160 MHz, Wi-Fi 4, BLE 5 | 4 MB | 18.0 × 20.0 × 3.2 mm | 3.0–3.6 V | Mature, cheap, but lacks 802.15.4. | https://documentation.espressif.com/esp32-c3-wroom-02_datasheet_en.html |
| HT-CT62 | Heltec | ESP32-C3FN4 + SX1262 LoRa | 4 MB | 17.78 × 17.78 × 2.8 mm castellated | 2.7–3.5 V | Good for future sub-GHz outdoor sensors; not for garage actuator. | https://heltec.org/project/ht-ct62/ |
| T7-C6 | LILYGO | ESP32-C6-MINI-1 | 4 MB | 41 × 27 mm devboard | 5 V USB | Cheap C6 reference, confirms module availability. | https://lilygo.cc/en-us/products/t7-c6 |
| Raspberry Pi Pico 2 W | Raspberry Pi | RP2350 dual Cortex-M33 / Hazard3, 802.11n, BT 5.2 | 4 MB QSPI | 21 × 51 mm module | 1.8–5.5 V | Excellent alternative, but ESPHome support is weaker than ESP32. | https://www.raspberrypi.com/products/raspberry-pi-pico-2/ |
| Orange Pi Zero 2W/3 | Orange Pi | Allwinner H618 quad A53, Wi-Fi 5, BT 5.0 | TF/eMMC | 65 × 30 / 55 × 50 mm SBC | 5 V/3 A | Linux SBC, too big/power-hungry for this class of board. | http://www.orangepi.org/orangepiwiki/index.php/Orange_Pi_Zero_2W |

## Power / peripheral parts

| Category | Recommended part | Why |
|---|---|---|
| 3.3 V LDO | AP2112K-3.3TRG1 (SOT-23-5) | Used across existing boards; 600 mA, stable, cheap, LCSC C51115. |
| 5 V → 3.3 V when USB-powered | AP2112K direct from VBUS | GaragePilot is USB-C or 5 V terminal powered; no buck needed. |
| Low-voltage relay | HF32F-G-12-HS or HF3FA-12-1HS1T | 10 A contact, 12 V coil; 3.3 V coil variant also stocked. |
| Terminal block | KF301-5.0-2P / 3P | 5.0 mm pitch, 300 V/10 A, JLCPCB basic parts. |
| USB-C receptacle | TYPE-C-31-M-12 (16P mid-mount) | Used across existing boards; LCSC C165948. |
| Tactile switch | TS-1187A-B-A-B (6×6 SMD) | BOOT/RESET, LCSC C139797. |

## Implications for future concepts

- **GaragePilot C6** uses ESP32-C6-WROOM-1 because 802.15.4 enables Matter-over-Thread garage-door control later, while ESPHome Wi-Fi works today.
- Next likely concepts to fill remaining gaps: **WaterLeak C6** (capacitive leak detection), **ValveMaster C6** (24 VAC irrigation valve driver), or **SirenActuator C6** (alarm siren + strobe). All can reuse the C6 + AP2112 + terminal-block platform established here.
- Keep monitoring Espressif for ESP32-C61 or C5 modules; do **not** churn existing validated C6/C3 designs until a new module offers a concrete advantage and is generally available.

## Sources checked this run

- Espressif ESP32-C6-WROOM-1 datasheet v1.4 — https://documentation.espressif.com/esp32-c6-wroom-1_wroom-1u_datasheet_en.html (accessed 2026-09-25)
- Espressif ESP32-C3-WROOM-02 datasheet v1.7 — https://documentation.espressif.com/esp32-c3-wroom-02_datasheet_en.html (accessed 2026-09-25)
- Espressif part-number guide — https://developer.espressif.com/blog/2025/03/espressif-part-numbers-explained/ (accessed 2026-09-25)
- Heltec HT-CT62 product page / datasheet — https://heltec.org/project/ht-ct62/ (accessed 2026-09-25)
- LILYGO T7-C6 product page — https://lilygo.cc/en-us/products/t7-c6 (accessed 2026-09-25)
- Raspberry Pi Pico 2 / Pico 2 W product page — https://www.raspberrypi.com/products/raspberry-pi-pico-2/ (accessed 2026-09-25)
- Orange Pi Zero 2W wiki — http://www.orangepi.org/orangepiwiki/index.php/Orange_Pi_Zero_2W (accessed 2026-09-25)
- Orange Pi Zero 3 wiki — http://www.orangepi.org/orangepiwiki/index.php/Orange_Pi_Zero_3 (accessed 2026-09-25)

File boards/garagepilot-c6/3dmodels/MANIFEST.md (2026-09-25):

# 3D model manifest — GaragePilot C6

All STEP files live in this directory and are referenced from `garagepilot-c6.kicad_pcb`
using `${KIPRJMOD}/3dmodels/...`.  No machine-global paths are required.

| Filename | Used by | Source URL | License | SHA-256 |
|---|---|---|---|---|
| `ESP32-C6-WROOM-1.STEP` | U1 | [espressif/kicad-libraries 3dmodels/espressif.3dshapes/ESP32-C6-WROOM-1U.STEP](https://github.com/espressif/kicad-libraries/raw/main/3dmodels/espressif.3dshapes/ESP32-C6-WROOM-1U.STEP) | CC-BY-SA 4.0 with [KiCad libraries exception](https://github.com/espressif/kicad-libraries/blob/main/LICENSE.md) | `9565ee695edb06a09ae9a7017485ac54391e0ba9f0cab58609fd185e6351f4ac` |
| `C_0603_1608Metric.step` | C1–C3 | [KiCad packages3D Capacitor_SMD.3dshapes/C_0603_1608Metric.step](https://gitlab.com/kicad/libraries/kicad-packages3D/-/raw/master/Capacitor_SMD.3dshapes/C_0603_1608Metric.step) | CC-BY-SA 4.0 with [KiCad libraries exception](https://www.kicad.org/libraries/license/) | `4857b3dc717675bf1fb22edda622ac3b3ae03cf44d81eefaf3fa3ba3a86d84c1` |
| `R_0603_1608Metric.step` | R1–R11 | [KiCad packages3D Resistor_SMD.3dshapes/R_0603_1608Metric.step](https://gitlab.com/kicad/libraries/kicad-packages3D/-/raw/master/Resistor_SMD.3dshapes/R_0603_1608Metric.step) | CC-BY-SA 4.0 with KiCad libraries exception | `1875571c326d0d9e96f36b4efeb8094068ef7619f0a449c781caf0b49c2e5861` |
| `LED_0603_1608Metric.step` | D2 | [KiCad packages3D LED_SMD.3dshapes/LED_0603_1608Metric.step](https://gitlab.com/kicad/libraries/kicad-packages3D/-/raw/master/LED_SMD.3dshapes/LED_0603_1608Metric.step) | CC-BY-SA 4.0 with KiCad libraries exception | `98343205ec260ec165026ba2d44329a23096779ac36c553ea84aa7b370242e6d` |
| `D_SMA.step` | D1 | [KiCad packages3D Diode_SMD.3dshapes/D_SMA.step](https://gitlab.com/kicad/libraries/kicad-packages3D/-/raw/master/Diode_SMD.3dshapes/D_SMA.step) | CC-BY-SA 4.0 with KiCad libraries exception | `1cfddd4e3b1bf22b8fc6ee3258c2aade882ed7b85b528e23b9db42437775a1db` |
| `SOT-23.step` | Q1 | [KiCad packages3D Package_TO_SOT_SMD.3dshapes/SOT-23.step](https://gitlab.com/kicad/libraries/kicad-packages3D/-/raw/master/Package_TO_SOT_SMD.3dshapes/SOT-23.step) | CC-BY-SA 4.0 with KiCad libraries exception | `dd5d1711204e1d8d26cd11490923bd84340820baa69538c385a4300ec2539bc0` |
| `SOT-23-5.step` | U2 | [KiCad packages3D Package_TO_SOT_SMD.3dshapes/SOT-23-5.step](https://gitlab.com/kicad/libraries/kicad-packages3D/-/raw/master/Package_TO_SOT_SMD.3dshapes/SOT-23-5.step) | CC-BY-SA 4.0 with KiCad libraries exception | `720a6eab0024069bbee68e7cb4c3ff1149468a34611225cdc852662c5d0ec2b7` |
| `Relay_SPDT_SANYOU_SRD_Series_Form_C.step` | K1 | [KiCad packages3D Relay_THT.3dshapes/Relay_SPDT_SANYOU_SRD_Series_Form_C.step](https://gitlab.com/kicad/libraries/kicad-packages3D/-/raw/master/Relay_THT.3dshapes/Relay_SPDT_SANYOU_SRD_Series_Form_C.step) | CC-BY-SA 4.0 with KiCad libraries exception | `3d92616e573e298f066fde6cc7ba9cdcf7b25c78be1107297eab3af097728c71` |
| `USB_C_Receptacle_GCT_USB4105-xx-A_16P_TopMnt_Horizontal.step` | J1 | [KiCad packages3D Connector_USB.3dshapes/USB_C_Receptacle_GCT_USB4105-xx-A_16P_TopMnt_Horizontal.step](https://gitlab.com/kicad/libraries/kicad-packages3D/-/raw/master/Connector_USB.3dshapes/USB_C_Receptacle_GCT_USB4105-xx-A_16P_TopMnt_Horizontal.step) | CC-BY-SA 4.0 with KiCad libraries exception | `6338ce740fa231c2d3dcc6384e0576994a47240a312a21413cb85d76990a69a0` |
| `PinHeader_1x04_P2.54mm_Vertical.step` | J5 | [KiCad packages3D Connector_PinHeader_2.54mm.3dshapes/PinHeader_1x04_P2.54mm_Vertical.step](https://gitlab.com/kicad/libraries/kicad-packages3D/-/raw/master/Connector_PinHeader_2.54mm.3dshapes/PinHeader_1x04_P2.54mm_Vertical.step) | CC-BY-SA 4.0 with KiCad libraries exception | `a74079b8d06bda78847623b39ee1855ffd1d9a8c1e896b349e4f1dc2056d44d9` |
| `SW_Push_1P1T_NO_E-Switch_TL3301NxxxxxG.step` | SW1, SW2 | [KiCad packages3D Button_Switch_SMD.3dshapes/SW_Push_1P1T_NO_E-Switch_TL3301NxxxxxG.step](https://gitlab.com/kicad/libraries/kicad-packages3D/-/raw/master/Button_Switch_SMD.3dshapes/SW_Push_1P1T_NO_E-Switch_TL3301NxxxxxG.step) | CC-BY-SA 4.0 with KiCad libraries exception | `481b6420fcfc668cbad880c1ed5aad067d341adc9f3aaa28925464d9637728bc` |
| `TerminalBlock_Phoenix_MKDS-1,5-2-5.08_1x02_P5.08mm_Horizontal.step` | J4 | [KiCad packages3D TerminalBlock_Phoenix.3dshapes/TerminalBlock_Phoenix_MKDS-1,5-2-5.08_1x02_P5.08mm_Horizontal.step](https://gitlab.com/kicad/libraries/kicad-packages3D/-/raw/master/TerminalBlock_Phoenix.3dshapes/TerminalBlock_Phoenix_MKDS-1,5-2-5.08_1x02_P5.08mm_Horizontal.step) | CC-BY-SA 4.0 with KiCad libraries exception | `2684469b03d2dd46f26862eb86eb283215344c311dd485db877e7139b5381497` |
| `TerminalBlock_Phoenix_MKDS-1,5-3-5.08_1x03_P5.08mm_Horizontal.step` | J2, J3 | [KiCad packages3D TerminalBlock_Phoenix.3dshapes/TerminalBlock_Phoenix_MKDS-1,5-3-5.08_1x03_P5.08mm_Horizontal.step](https://gitlab.com/kicad/libraries/kicad-packages3D/-/raw/master/TerminalBlock_Phoenix.3dshapes/TerminalBlock_Phoenix_MKDS-1,5-3-5.08_1x03_P5.08mm_Horizontal.step) | CC-BY-SA 4.0 with KiCad libraries exception | `3c5e634cf57b5fec27d1c2fb6a82dc0f47d846de92881b4a8a4277db2c9afa9a` |

## Notes

* The `ESP32-C6-WROOM-1.STEP` model was obtained from the Espressif KiCad library as `ESP32-C6-WROOM-1U.STEP`.  The `-1U` variant differs only by the addition of a U.FL antenna connector; the shield, body, and castellated-pad geometry are identical to the on-PCB-antenna `ESP32-C6-WROOM-1` used on this board.  The local file was renamed to match the BOM footprint.
* All KiCad packages3D models use the standard [KiCad library license](https://www.kicad.org/libraries/license/) (CC-BY-SA 4.0 with the Design Exception).  The Espressif library uses the same license terms; see its [LICENSE.md](https://github.com/espressif/kicad-libraries/blob/main/LICENSE.md).
* Models were verified by loading the populated board in KiCad's 3D viewer and in the `kicad-cli pcb render` outputs saved under `images/`.

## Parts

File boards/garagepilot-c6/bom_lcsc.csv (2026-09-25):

Designator | Qty | Value | Footprint | MPN | LCSC | Description | Datasheet_URL | Sourcing_URL
U1 | 1 | ESP32-C6-WROOM-1-N8 | garagepilot-c6-lib:ESP32-C6-WROOM-1 | ESP32-C6-WROOM-1-N8 | C5366877 | Espressif Wi-Fi 6 / BLE / 802.15.4 module | https://www.espressif.com/sites/default/files/documentation/esp32-c6-wroom-1_wroom-1u_datasheet_en.pdf | https://lcsc.com/product-detail/C5366877.html
U2 | 1 | AP2112K-3.3 | Package_TO_SOT_SMD:SOT-23-5 | AP2112K-3.3TRG1 | C51115 | LDO 3.3 V 600 mA | https://www.diodes.com/assets/Datasheets/AP2112.pdf | https://lcsc.com/product-detail/C51115.html
Q1 | 1 | AO3400A | Package_TO_SOT_SMD:SOT-23 | AO3400A | C20917 | N-channel MOSFET 30 V 5.7 A | https://www.lcsc.com/datasheet/lcsc_datasheet_2304140030_AOSMD-AO3400A_C20917.pdf | https://lcsc.com/product-detail/C20917.html
K1 | 1 | SRD-05VDC-SL-C | garagepilot-c6-lib:Relay_T73 | SRD-05VDC-SL-C | C95269 | 5 V SPDT relay 10 A | https://www.lcsc.com/datasheet/lcsc_datasheet_2304140030_SONGLE-SRD-05VDC-SL-C_C95269.pdf | https://lcsc.com/product-detail/C95269.html
D1 | 1 | SS34 | Diode_SMD:D_SMA | SS34 | C8678 | Schottky diode 40 V 3 A flyback | https://www.lcsc.com/datasheet/lcsc_datasheet_2304140030_Guangdong-Hottech-SS34_C8678.pdf | https://lcsc.com/product-detail/C8678.html
D2 | 1 | LED red 0603 | LED_SMD:LED_0603_1608Metric | LTST-C190KRKT | C2286 | Red status LED | ~ | https://lcsc.com/product-detail/C2286.html
R1,R3,R4,R5,R10,R11 | 6 | 10k | Resistor_SMD:R_0603_1608Metric | 0603WAF1002T5E | C25804 | Resistor 10 kΩ 0603 1% | ~ | https://lcsc.com/product-detail/C25804.html
R2 | 1 | 100R | Resistor_SMD:R_0603_1608Metric | RCA03100RFLF | C22369795 | Resistor 100 Ω 0603 1% gate | ~ | https://lcsc.com/product-detail/C22369795.html
R6,R7 | 2 | 4.7k | Resistor_SMD:R_0603_1608Metric | 0603WAF4701T5E | C23162 | Resistor 4.7 kΩ 0603 1% CC pulldown | ~ | https://lcsc.com/product-detail/C23162.html
R8,R9 | 2 | 22R | Resistor_SMD:R_0603_1608Metric | 0603WAF220JT5E | C22926 | Resistor 22 Ω 0603 5% USB series | ~ | https://lcsc.com/product-detail/C22926.html
C1,C2 | 2 | 10uF | Capacitor_SMD:C_0603_1608Metric | CL10A106KP8NNNC | C15849 | MLCC 10 µF 6.3 V X5R 0603 | ~ | https://lcsc.com/product-detail/C15849.html
C3 | 1 | 100nF | Capacitor_SMD:C_0603_1608Metric | 0603B104K500NT | C14663 | MLCC 100 nF 50 V X7R 0603 | ~ | https://lcsc.com/product-detail/C14663.html
SW1,SW2 | 2 | TS-1187A | garagepilot-c6-lib:Tactile-6x6-SMD | TS-1187A-B-A-B | C139797 | 6x6 mm SMD tactile switch | ~ | https://lcsc.com/product-detail/C139797.html
J1 | 1 | TYPE-C-31-M-12 | Connector_USB:USB_C_Receptacle_USB2.0_16P | TYPE-C-31-M-12 | C165948 | USB-C 2.0 16-pin mid-mount receptacle | https://www.lcsc.com/datasheet/lcsc_datasheet_2410252104_Korean-Hroparts-Elec-TYPE-C-31-M-12_C165948.pdf | https://lcsc.com/product-detail/C165948.html
J2,J3 | 2 | WJ500V-5.08-3P | garagepilot-c6-lib:ScrewTerm-5.08-3P | WJ500V-5.08-3P | C8465 | 5.08 mm 3-pin screw terminal | ~ | https://lcsc.com/product-detail/C8465.html
J4 | 1 | WJ500V-5.08-2P | garagepilot-c6-lib:ScrewTerm-5.08-2P | WJ500V-5.08-2P | C8465 | 5.08 mm 2-pin screw terminal | ~ | https://lcsc.com/product-detail/C8465.html
J5 | 1 | KH-2.54PH180-1X4P-L13.5 | Connector_PinHeader_2.54mm:PinHeader_1x04_P2.54mm_Vertical | KH-2.54PH180-1X4P-L13.5 | C49258 | 1x4 2.54 mm programming header | ~ | https://lcsc.com/product-detail/C49258.html
TP1-TP4 | 4 | Test point | garagepilot-c6-lib:TestPoint_Pad_1.0mm | Test point | C152136 | 1.0 mm round SMD test point | ~ | https://lcsc.com/product-detail/C152136.html
H1-H4 | 4 | MountingHole_M2.5 | garagepilot-c6-lib:MountingHole_M2.5 | — | — | M2.5 non-plated mounting hole | ~ | ~

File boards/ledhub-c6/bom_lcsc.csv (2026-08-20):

ref | value | footprint | lcsc | mpn | qty
U1 | ESP32-C6-WROOM-1 | custom:ESP32-C6-WROOM-1 | C5366877 | ESP32-C6-WROOM-1-N8 | 1
X1 | USB_C_16P | Connector_USB:USB_C_Receptacle_USB2.0_16P | C165948 | TYPE-C-31-M-12 | 1
U2 | INMP441 | custom:INMP441-LGA9 | - | INMP441ACEZ-R7 | 1
U3 | SHT31 | custom:SHT31-DFN8 | C80862 | SHT31-DIS-B2.5kS | 1
U4 | BH1750 | custom:BH1750-WSOF6 | C78960 | BH1750FVI-TR | 1
U5 | 74AHCT125 | Package_SO:SOIC-14_3.9x8.7mm_P1.27mm | C842299 | 74AHCT125S14-13 | 1
U6 | AP2112K-3.3 | Package_TO_SOT_SMD:SOT-23-5 | C51118 | AP2112K-3.3TRG1 | 1
ENC1 | EC11 | custom:EC11-Encoder | C370970 | EC11E15244G1 | 1
R1 | R2 | R14 | 4.7k | Resistor_SMD:R_0603_1608Metric | C23162 | 0603WAF4701T5E | 3
R13 | 2.2k | Resistor_SMD:R_0603_1608Metric | C4190 | 0603WAF2201T5E | 1
R7 | R10 | R11 | R15 | 10k | Resistor_SMD:R_0603_1608Metric | C25804 | 0603WAF1002T5E | 4
R18 | 22k | Resistor_SMD:R_0603_1608Metric | C31850 | 0603WAF2202T5E | 1
R3 | R4 | 5.1k | Resistor_SMD:R_0603_1608Metric | C23186 | 0603WAF5101T5E | 2
R5 | R6 | 22R | Resistor_SMD:R_0603_1608Metric | C22926 | 0603WAF220JT5E | 2
R9 | 100R | Resistor_SMD:R_0603_1608Metric | C22775 | 0603WAF1000T5E | 1
R19 | 470R | Resistor_SMD:R_0603_1608Metric | C23179 | 0603WAF4700T5E | 1
R8 | 1k | Resistor_SMD:R_0603_1608Metric | C21190 | 0603WAF1001T5E | 1
R12 | R16 | R17 | R20 | R21 | 0R | Resistor_SMD:R_0603_1608Metric | C21189 | 0603WAF0000T5E | 5
C1 | C2 | C8 | 10uF | Capacitor_SMD:C_0603_1608Metric | C15849 | CL10A106KP8NNNC | 3
C3 | C4 | C5 | C6 | C7 | C9 | C10 | 100nF | Capacitor_SMD:C_0603_1608Metric | C14663 | 0603B104K500NT | 7
D1 | LED_RED | LED_SMD:LED_0603_1608Metric | C2286 | LTST-C190KRKT | 1
BT1 | BT2 | BT_UP | BT_DN | BT_LF | BT_RT | BT_OK | SW_PUSH | custom:Tactile-6x6-SMD | C318884 | TS-1187A-B-A-B | 7
J1 | Conn_02x07 | Connector_PinHeader_2.54mm:PinHeader_2x07_P2.54mm_Vertical | C492424 | PZ254V-12-14P | 1
J2 | Conn_01x05 | Connector_PinHeader_2.54mm:PinHeader_1x05_P2.54mm_Vertical | C492404 | PZ254V-11-05P | 1
J5 | Conn_01x04 | Connector_PinHeader_2.54mm:PinHeader_1x04_P2.54mm_Vertical | C2691448 | PZ254V-11-04P | 1
J3 | Term_3P | custom:KF128-5.08-3P | C474953 | KF128-5.08-3P-AA | 1
J4 | Term_2P | custom:KF128-5.08-2P | C474952 | KF128-5.08-2P-AA | 1
(on J2) | LD2450 | - | - | HLK-LD2450 | 1
(on J1) | TFT_2.8 | - | - | ILI9341-2.8-SPI | 1

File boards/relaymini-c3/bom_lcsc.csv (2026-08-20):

Ref | Value | Footprint | LCSC | MPN | Qty
U1 | HLK-PM01 | custom:HLK-PM01 | C209903 | HLK-PM01 | 1
U2 | AP2112K-3.3 | Package_TO_SOT_SMD:SOT-23-5 | C51115 | AP2112K-3.3TRG1 | 1
U3 | BL0942 | custom:BL0942-SSOP10 | C2837510 | BL0942 | 1
U4 | PC817 | custom:PC817-SOP4 | C3008369 | PC817C-S | 1
U5 | PC817 | custom:PC817-SOP4 | C3008369 | PC817C-S | 1
U6 | ESP32-C3-WROOM-02 | custom:ESP32-C3-WROOM-02 | C2934560 | ESP32-C3-WROOM-02-N4 | 1
K1 | HF32F-G | custom:HF32F-G | C74541 | HF32F-G/005-HS | 1
Q1 | S8050 | Package_TO_SOT_SMD:SOT-23 | C181158 | S8050 | 1
D1 | 1N4148WS | Diode_SMD:D_SOD-323 | C2128 | 1N4148WS | 1
D2 | LED_GRN | LED_SMD:LED_0603_1608Metric | C2297 | LTST-C190KGKT | 1
F1 | FUSE_CLIP | custom:FuseClip-5x20 | C3130 | 5x20-CLIP | 1
F1E | FUSE_10A | (fuse element) | C3122 | 5F.0010220000R1 | 1
RV1 | MOV_10D471K | custom:MOV-10D | C8760 | 10D471K | 1
BT1 | SW_PUSH | custom:Tactile-6x6-SMD | C139797 | TS-1187A-B-A-B | 1
J1 | Term_5.08_2P | custom:TerminalBlock-5.08-2P | C8465 | WJ500V-5.08-2P | 1
J2 | Term_5.08_2P | custom:TerminalBlock-5.08-2P | C8465 | WJ500V-5.08-2P | 1
J3 | Conn_01x04 | Connector_PinHeader_2.54mm:PinHeader_1x04_P2.54mm_Vertical | C49258 | KH-2.54PH180-1X4P-L13.5 | 1
R1 | 1k | Resistor_SMD:R_0603_1608Metric | C21190 | 0603WAF1001T5E | 1
R2 | 1k | Resistor_SMD:R_0603_1608Metric | C21190 | 0603WAF1001T5E | 1
R3 | SHUNT_1mR | custom:Shunt-2512 | C2903470 | HoJLR2512-3W-1mR-1% | 1
R4 | 470k | Resistor_SMD:R_0603_1608Metric | C23178 | 0603WAF4703T5E | 1
R5 | 470k | Resistor_SMD:R_0603_1608Metric | C23178 | 0603WAF4703T5E | 1
R6 | 270R | Resistor_SMD:R_0603_1608Metric | C137641 | RC0603JR-07270RL | 1
R7 | 10k | Resistor_SMD:R_0603_1608Metric | C25804 | 0603WAF1002T5E | 1
R8 | 10k | Resistor_SMD:R_0603_1608Metric | C25804 | 0603WAF1002T5E | 1
R10 | 10k | Resistor_SMD:R_0603_1608Metric | C25804 | 0603WAF1002T5E | 1
R11 | 10k | Resistor_SMD:R_0603_1608Metric | C25804 | 0603WAF1002T5E | 1
R12 | 1k | Resistor_SMD:R_0603_1608Metric | C21190 | 0603WAF1001T5E | 1
R13 | 10k | Resistor_SMD:R_0603_1608Metric | C25804 | 0603WAF1002T5E | 1
R14 | 1k | Resistor_SMD:R_0603_1608Metric | C21190 | 0603WAF1001T5E | 1
R15 | 10k | Resistor_SMD:R_0603_1608Metric | C25804 | 0603WAF1002T5E | 1
C1 | 10uF | Capacitor_SMD:C_0603_1608Metric | C15849 | CL10A106KP8NNNC | 1
C2 | 100nF | Capacitor_SMD:C_0603_1608Metric | C14663 | 0603B104K500NT | 1
C3 | 10uF | Capacitor_SMD:C_0603_1608Metric | C15849 | CL10A106KP8NNNC | 1
C4 | 100nF | Capacitor_SMD:C_0603_1608Metric | C14663 | 0603B104K500NT | 1
C5 | 100nF | Capacitor_SMD:C_0603_1608Metric | C14663 | 0603B104K500NT | 1
C7 | 100nF | Capacitor_SMD:C_0603_1608Metric | C14663 | 0603B104K500NT | 1

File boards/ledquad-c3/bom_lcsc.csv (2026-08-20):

ref | value | footprint | lcsc | mpn | qty
U1 | ESP32-C3-WROOM-02 | custom:ESP32-C3-WROOM-02 | C2934560 | ESP32-C3-WROOM-02-N4 | 1
X1 | USB_C_16P | Connector_USB:USB_C_Receptacle_USB2.0_16P | C165948 | TYPE-C-31-M-12 | 1
U2 | AP63205 | Package_TO_SOT_SMD:SOT-23-6 | C2071056 | AP63205WU-7 | 1
U3 | AP2112K-3.3 | Package_TO_SOT_SMD:SOT-23-5 | C51115 | AP2112K-3.3TRG1 | 1
Q1 | Q2 | Q3 | Q4 | AO3400A | Package_TO_SOT_SMD:SOT-23 | C20917 | AO3400A | 4
D3 | D4 | SS34 | Diode_SMD:D_SMA | C8678 | SS34 | 2
F1 | FUSE_5A | Fuse:Fuse_1206_3216Metric | C136351 | JFC1206-1500FS | 1
L1 | L_4R7 | custom:L-4x4-4R7 | C167874 | FNR4030S4R7MT | 1
J1 | TB_2P | custom:TB-5.08-2P | C474952 | KF128-5.08-2P-AA | 1
J2 | TB_5P | custom:TB-5.08-5P | C42377750 | WJ500V-5.08-05P-14-00A | 1
J3 | Conn_01x04 | Connector_PinHeader_2.54mm:PinHeader_1x04_P2.54mm_Vertical | C49258 | KH-2.54PH180-1X4P-L13.5 | 1
BT1 | BT2 | SW_PUSH | custom:Tactile-6x6-SMD | C139797 | TS-1187A-B-A-B | 2
R1 | R2 | R3 | R4 | 100R | Resistor_SMD:R_0603_1608Metric | C22369795 | RCA03100RFLF | 4
R5 | R6 | R7 | R8 | R13 | 10k | Resistor_SMD:R_0603_1608Metric | C25804 | 0603WAF1002T5E | 5
R9 | R10 | 5.1k | Resistor_SMD:R_0603_1608Metric | C23186 | 0603WAF5101T5E | 2
R11 | R12 | 22R | Resistor_SMD:R_0603_1608Metric | C22926 | 0603WAF220JT5E | 2
R14 | R15 | 1k | Resistor_SMD:R_0603_1608Metric | C21190 | 0603WAF1001T5E | 2
R16 | 100k | Resistor_SMD:R_0603_1608Metric | C25803 | 0603WAF1003T5E | 1
C1 | C6 | C7 | C10 | 10uF | Capacitor_SMD:C_0603_1608Metric | C15849 | CL10A106KP8NNNC | 4
C2 | C3 | C8 | C9 | 100nF | Capacitor_SMD:C_0603_1608Metric | C14663 | 0603B104K500NT | 4
C4 | C5 | 22uF | Capacitor_SMD:C_0805_2012Metric | C45783 | CL21A226MAQNNNE | 2
D1 | LED_RED | LED_SMD:LED_0603_1608Metric | C2286 | LTST-C190KRKT | 1
D2 | LED_GRN | LED_SMD:LED_0603_1608Metric | C2297 | LTST-C190KGKT | 1

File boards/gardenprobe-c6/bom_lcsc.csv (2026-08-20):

ref | value | footprint | lcsc | mpn | qty
U1 | ESP32-C6-WROOM-1 | gardenprobe-c6:ESP32-C6-WROOM-1 | C5366877 | ESP32-C6-WROOM-1-N8 | 1
BT1 | JST_PH_2 | gardenprobe-c6:JST-PH-2 | C131337 | B2B-PH-K-S(LF)(SN) | 1
U2 | MCP1700-3302 | Package_TO_SOT_SMD:SOT-23 | C39051 | MCP1700T-3302E/TT | 1
Q1 | AO3401A | Package_TO_SOT_SMD:SOT-23 | C15127 | AO3401A | 1
U3 | SHT31 | gardenprobe-c6:SHT31-DFN8 | C80862 | SHT31-DIS-B2.5kS | 1
J2 | SOIL_PROBE | gardenprobe-c6:SoilProbe-BCu | — | copper electrodes on B.Cu (ENIG recommended) | 1
R1 | 10k | Resistor_SMD:R_0603_1608Metric | C25804 | 0603WAF1002T5E | 1
R3 | R4 | 100k | Resistor_SMD:R_0603_1608Metric | C25803 | 0603WAF1003T5E | 2
R5 | 1M | Resistor_SMD:R_0603_1608Metric | C269433 | RMC06031M5%N | 1
R6 | R7 | 4.7k | Resistor_SMD:R_0603_1608Metric | C23162 | 0603WAF4701T5E | 2
C1 | 10uF | Capacitor_SMD:C_0603_1608Metric | C15849 | CL10A106KP8NNNC | 1
C2 | C3 | C4 | 100nF | Capacitor_SMD:C_0603_1608Metric | C14663 | 0603B104K500NT | 3
J1 | Conn_01x04 | Connector_PinHeader_2.54mm:PinHeader_1x04_P2.54mm_Vertical | C49258 | KH-2.54PH180-1X4P-L13.5 | 1

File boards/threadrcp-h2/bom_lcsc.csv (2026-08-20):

ref | value | footprint | lcsc | mpn | qty
U1 | ESP32-H2-MINI-1 | threadrcp-h2:ESP32-H2-MINI-1 | — | ESP32-H2-MINI-1-N4 | 1
X1 | USB_C_16P | Connector_USB:USB_C_Receptacle_USB2.0_16P | C165948 | TYPE-C-31-M-12 | 1
U2 | AP2112K-3.3 | Package_TO_SOT_SMD:SOT-23-5 | C51115 | AP2112K-3.3TRG1 | 1
BT1 | BT2 | SW_PUSH | threadrcp-h2:Tactile-6x6-SMD | C139797 | TS-1187A-B-A-B | 2
D1 | LED_RED | LED_SMD:LED_0603_1608Metric | C2286 | LTST-C190KRKT | 1
D2 | LED_GRN | LED_SMD:LED_0603_1608Metric | C2297 | LTST-C190KGKT | 1
R8 | R9 | 1k | Resistor_SMD:R_0603_1608Metric | C21190 | 0603WAF1001T5E | 2
R3 | R4 | 5.1k | Resistor_SMD:R_0603_1608Metric | C23186 | 0603WAF5101T5E | 2
R7 | 10k | Resistor_SMD:R_0603_1608Metric | C25804 | 0603WAF1002T5E | 1
C1 | C2 | 10uF | Capacitor_SMD:C_0603_1608Metric | C15849 | CL10A106KP8NNNC | 2
C3 | C4 | 100nF | Capacitor_SMD:C_0603_1608Metric | C14663 | 0603B104K500NT | 2

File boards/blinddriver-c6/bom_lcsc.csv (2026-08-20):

ref | value | footprint | lcsc | mpn | qty
U1 | ESP32-C6-WROOM-1 | blinddriver-c6:ESP32-C6-WROOM-1 | C5366877 | ESP32-C6-WROOM-1-N8 | 1
X1 | USB_C_16P | Connector_USB:USB_C_Receptacle_USB2.0_16P | C165948 | TYPE-C-31-M-12 | 1
U2 | AP2112K-3.3 | Package_TO_SOT_SMD:SOT-23-5 | C51115 | AP2112K-3.3TRG1 | 1
U3 | AP63205 | Package_TO_SOT_SMD:SOT-23-6 | C2071056 | AP63205WU-7 | 1
U4 | TMC2209 | blinddriver-c6:TMC2209-socket | C2150710 | TMC2209-LA-T | 1
J3 | J4 | Conn_01x08 | Connector_PinHeader_2.54mm:PinHeader_1x08_P2.54mm_Vertical | C492407 | PZ254V-11-08P | 2
J5 | J6 | J7 | ScrewTerm_2P | blinddriver-c6:ScrewTerm-5.08-2P | C8465 | WJ500V-5.08-2P | 3
J8 | Conn_01x03 | Connector_PinHeader_2.54mm:PinHeader_1x03_P2.54mm_Vertical | C49257 | KH-2.54PH180-1X3P-L13.5 | 1
D2 | D3 | SS34 | Diode_SMD:D_SMA | C8678 | SS34 | 2
C8 | 100uF_35V | Capacitor_SMD:CP_Electrolytic_5x5.3 | C2836437 | RVE100UF35V67RV0072 | 1
L1 | 4.7uH | blinddriver-c6:IND-4040 | C167874 | FNR4030S4R7MT | 1
C6 | 22uF | Capacitor_SMD:C_0805_2012Metric | C45783 | CL21A226MAQNNNE | 1
C7 | C3 | 100nF | Capacitor_SMD:C_0603_1608Metric | C14663 | 0603B104K500NT | 2
R10 | R11 | 100k | Resistor_SMD:R_0603_1608Metric | C25803 | 0603WAF1003T5E | 2
BT1 | BT2 | SW_PUSH | blinddriver-c6:Tactile-6x6-SMD | C139797 | TS-1187A-B-A-B | 2
D1 | LED_RED | LED_SMD:LED_0603_1608Metric | C2286 | LTST-C190KRKT | 1
R8 | 1k | Resistor_SMD:R_0603_1608Metric | C21190 | 0603WAF1001T5E | 1
R3 | R4 | 5.1k | Resistor_SMD:R_0603_1608Metric | C23186 | 0603WAF5101T5E | 2
R7 | 10k | Resistor_SMD:R_0603_1608Metric | C25804 | 0603WAF1002T5E | 1
C1 | C2 | 10uF | Capacitor_SMD:C_0603_1608Metric | C15849 | CL10A106KP8NNNC | 2

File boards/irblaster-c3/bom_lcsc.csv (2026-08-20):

ref | value | footprint | lcsc | mpn | qty
U1 | ESP32-C3-WROOM-02 | irblaster-c3:ESP32-C3-WROOM-02 | C2934560 | ESP32-C3-WROOM-02-N4 | 1
X1 | USB_C_16P | Connector_USB:USB_C_Receptacle_USB2.0_16P | C165948 | TYPE-C-31-M-12 | 1
U2 | AP2112K-3.3 | Package_TO_SOT_SMD:SOT-23-5 | C51115 | AP2112K-3.3TRG1 | 1
U3 | TSOP38238 | irblaster-c3:TSOP38238 | C141632 | TSOP38238 | 1
U4 | BH1750 | irblaster-c3:BH1750-WSOF6 | C78960 | BH1750FVI-TR | 1
D2 | D3 | TSAL6200 | irblaster-c3:IR-LED-5mm | C55528 | TSAL6200 | 2
Q1 | S8050 | Package_TO_SOT_SMD:SOT-23 | C2146 | S8050 J3Y | 1
R6 | R7 | 47R | Resistor_SMD:R_0603_1608Metric | C2907043 | FRC0603F47R0TS | 2
R9 | 100R | Resistor_SMD:R_0603_1608Metric | C22369795 | RCA03100RFLF | 1
R5 | 4.7k | Resistor_SMD:R_0603_1608Metric | C23162 | 0603WAF4701T5E | 1
R8 | 1k | Resistor_SMD:R_0603_1608Metric | C21190 | 0603WAF1001T5E | 1
R3 | R4 | 5.1k | Resistor_SMD:R_0603_1608Metric | C23186 | 0603WAF5101T5E | 2
R2 | 10k | Resistor_SMD:R_0603_1608Metric | C25804 | 0603WAF1002T5E | 1
C1 | C2 | 10uF | Capacitor_SMD:C_0603_1608Metric | C15849 | CL10A106KP8NNNC | 2
C3 | C4 | 100nF | Capacitor_SMD:C_0603_1608Metric | C14663 | 0603B104K500NT | 2
D1 | LED_GRN | LED_SMD:LED_0603_1608Metric | C2297 | LTST-C190KGKT | 1
BT1 | BT2 | SW_PUSH | irblaster-c3:Tactile-6x6-SMD | C139797 | TS-1187A-B-A-B | 2
J1 | Conn_01x04 | Connector_PinHeader_2.54mm:PinHeader_1x04_P2.54mm_Vertical | C49258 | KH-2.54PH180-1X4P-L13.5 | 1

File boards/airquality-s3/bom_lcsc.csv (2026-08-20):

ref | value | footprint | lcsc | mpn | qty
U1 | ESP32-S3-WROOM-1 | airquality-s3:ESP32-S3-WROOM-1 | C2913198 | ESP32-S3-WROOM-1-N8 | 1
X1 | USB_C_16P | Connector_USB:USB_C_Receptacle_USB2.0_16P | C165948 | TYPE-C-31-M-12 | 1
U2 | AP2112K-3.3 | Package_TO_SOT_SMD:SOT-23-5 | C51115 | AP2112K-3.3TRG1 | 1
U3 | SCD40 | airquality-s3:SCD40 | C3659421 | SCD40-D-R2 | 1
U4 | SGP40 | airquality-s3:SGP40-DFN6 | C2874215 | SGP40-D-R4 | 1
U5 | SHT40 | airquality-s3:SHT40-DFN4 | C2909890 | SHT40-AD1B-R2 | 1
BT1 | BT2 | SW_PUSH | airquality-s3:Tactile-6x6-SMD | C139797 | TS-1187A-B-A-B | 2
D1 | LED_GRN | LED_SMD:LED_0603_1608Metric | C2297 | LTST-C190KGKT | 1
R1 | R2 | 4.7k | Resistor_SMD:R_0603_1608Metric | C23162 | 0603WAF4701T5E | 2
R3 | R4 | 5.1k | Resistor_SMD:R_0603_1608Metric | C23186 | 0603WAF5101T5E | 2
R7 | 10k | Resistor_SMD:R_0603_1608Metric | C25804 | 0603WAF1002T5E | 1
R8 | 1k | Resistor_SMD:R_0603_1608Metric | C21190 | 0603WAF1001T5E | 1
C1 | C2 | 10uF | Capacitor_SMD:C_0603_1608Metric | C15849 | CL10A106KP8NNNC | 2
C3 | C4 | 100nF | Capacitor_SMD:C_0603_1608Metric | C14663 | 0603B104K500NT | 2
J1 | J2 | Conn_01x04 | Connector_PinHeader_2.54mm:PinHeader_1x04_P2.54mm_Vertical | C49258 | KH-2.54PH180-1X4P-L13.5 | 2

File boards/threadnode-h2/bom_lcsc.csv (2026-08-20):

ref | value | footprint | lcsc | mpn | qty
U1 | ESP32-H2-MINI-1 | threadnode-h2:ESP32-H2-MINI-1 | — | ESP32-H2-MINI-1-N4 | 1
BT1 | CR2032_HOLDER | threadnode-h2:CR2032-holder | C5239862 | BS-02-A1AJ010 | 1
SW1 | REED | threadnode-h2:Reed-SMD | C315909 | 59170-1-S-00-D | 1
BT2 | SW_PUSH | threadnode-h2:Tactile-6x6-SMD | C139797 | TS-1187A-B-A-B | 1
D1 | LED_GRN | LED_SMD:LED_0603_1608Metric | C2297 | LTST-C190KGKT | 1
R1 | 1k | Resistor_SMD:R_0603_1608Metric | C21190 | 0603WAF1001T5E | 1
R2 | 10k | Resistor_SMD:R_0603_1608Metric | C25804 | 0603WAF1002T5E | 1
R3 | 100k | Resistor_SMD:R_0603_1608Metric | C25803 | 0603WAF1003T5E | 1
R4 | R5 | 4.7k | Resistor_SMD:R_0603_1608Metric | C23162 | 0603WAF4701T5E | 2
C1 | 10uF | Capacitor_SMD:C_0603_1608Metric | C15849 | CL10A106KP8NNNC | 1
C2 | C3 | 100nF | Capacitor_SMD:C_0603_1608Metric | C14663 | 0603B104K500NT | 2
J1 | J2 | Conn_01x04 | Connector_PinHeader_2.54mm:PinHeader_1x04_P2.54mm_Vertical | C49258 | KH-2.54PH180-1X4P-L13.5 | 2

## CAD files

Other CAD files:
boards/garagepilot-c6/3dmodels/D_SMA.step
boards/garagepilot-c6/3dmodels/R_0603_1608Metric.step
boards/garagepilot-c6/3dmodels/USB_C_Receptacle_GCT_USB4105-xx-A_16P_TopMnt_Horizontal.step
boards/garagepilot-c6/3dmodels/SW_Push_1P1T_NO_E-Switch_TL3301NxxxxxG.step
boards/garagepilot-c6/3dmodels/ESP32-C6-WROOM-1.STEP
boards/garagepilot-c6/3dmodels/C_0603_1608Metric.step
boards/garagepilot-c6/3dmodels/TerminalBlock_Phoenix_MKDS-1,5-3-5.08_1x03_P5.08mm_Horizontal.step
boards/garagepilot-c6/3dmodels/PinHeader_1x04_P2.54mm_Vertical.step
boards/garagepilot-c6/3dmodels/SOT-23-5.step
boards/garagepilot-c6/3dmodels/Relay_SPDT_SANYOU_SRD_Series_Form_C.step
boards/garagepilot-c6/3dmodels/TerminalBlock_Phoenix_MKDS-1,5-2-5.08_1x02_P5.08mm_Horizontal.step
boards/garagepilot-c6/3dmodels/LED_0603_1608Metric.step
boards/garagepilot-c6/3dmodels/SOT-23.step

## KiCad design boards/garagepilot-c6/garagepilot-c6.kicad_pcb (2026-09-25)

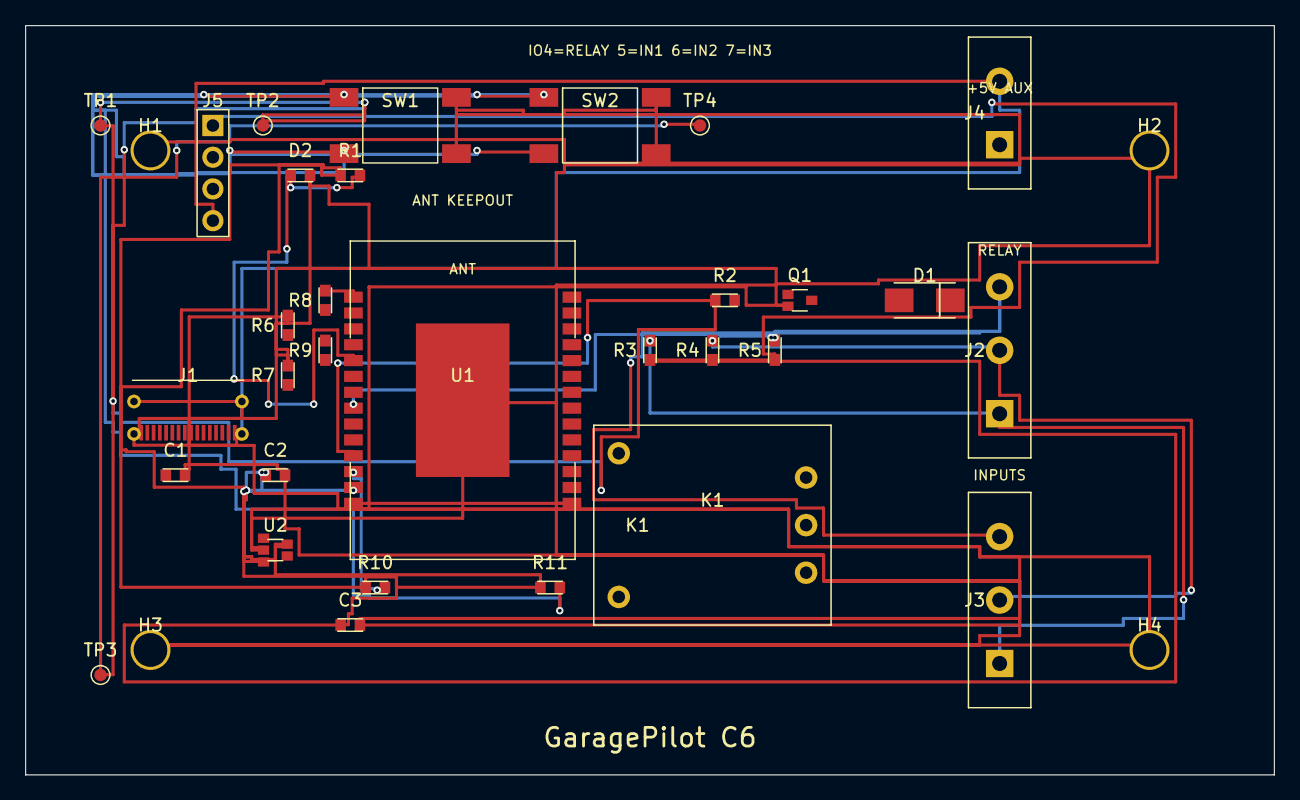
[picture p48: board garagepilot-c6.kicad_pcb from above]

Board: 2 copper layers, 100.0 x 60.0 mm, 35 parts (0 on the bottom side), 21 nets.

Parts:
C1, C2: 10uF; C_0603_1608Metric
C3: 100nF; C_0603_1608Metric
D1: SS34; D_SMA
D2: LED_RED; LED_0603_1608Metric
H1, H2, H3, H4: MountingHole_M2.5
J1: USB_C_16P; USB_C_Receptacle_USB2.0_16P
J2: RELAY; ScrewTerm-5.08-3P
J3: INPUTS; ScrewTerm-5.08-3P
J4: AUX_5V; ScrewTerm-5.08-2P
J5: PROG; PinHeader_1x04_P2.54mm_Vertical
K1: SRD-05VDC-SL-C; Relay_T73
Q1: AO3400A; SOT-23
R1, R3, R4, R5, R10, R11: 10k; R_0603_1608Metric
R2: 100R; R_0603_1608Metric
R6, R7: 4.7k; R_0603_1608Metric
R8, R9: 22R; R_0603_1608Metric
SW1: RESET; Tactile-6x6-SMD
SW2: BOOT; Tactile-6x6-SMD
TP1: +5V; TestPoint_Pad_1.0mm
TP2: +3V3; TestPoint_Pad_1.0mm
TP3: GND; TestPoint_Pad_1.0mm
TP4: RELAY_DRV; TestPoint_Pad_1.0mm
U1: ESP32-C6-WROOM-1-N8; ESP32-C6-WROOM-1
U2: AP2112K-3.3; SOT-23-5

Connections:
+3V3: C2.1, C3.1, J5.1, R1.1, R3.1, R4.1, R5.1, R10.1, R11.1, U1.2, U2.3, U2.5
+5V: D1.1, J4.1, K1.1
BOOT: R11.2, SW1.1, SW1.3, SW2.1, SW2.3, U1.15
EN: R10.2, U1.3
GND: C1.2, C2.2, C3.2, D2.2, J1.1, J1.8, J1.9, J1.16, J1.S1, J1.S2, J1.S3, J1.S4, J4.2, J5.4, Q1.2, R6.2, R7.2, SW1.2, SW1.4, SW2.2, SW2.4, U1.1, U1.28, U1.29, U2.2
INPUT1: J2.1, J3.1, R3.2, U1.5
INPUT2: J2.2, J3.2, R4.2, U1.6
INPUT3: J2.3, J3.3, R5.2, U1.7
K1_COIL_P: D1.2, K1.2, Q1.3
LED1_A: D2.1, R1.2, U1.10
Q1_GATE: Q1.1, R2.2
RELAY_DRV: R2.1, TP1.1, TP2.1, TP3.1, TP4.1, U1.4
RX0: J5.3, U1.24
TX0: J5.2, U1.25
USB_CC1: J1.3, R6.1
USB_CC2: J1.14, R7.1
USB_DM: J1.5, J1.12, R9.1
USB_DM_FILT: R9.2, U1.13
USB_DP: J1.4, J1.13, R8.1
USB_DP_FILT: R8.2, U1.14
VBUS: C1.1, J1.2, J1.7, J1.10, J1.15, U2.1

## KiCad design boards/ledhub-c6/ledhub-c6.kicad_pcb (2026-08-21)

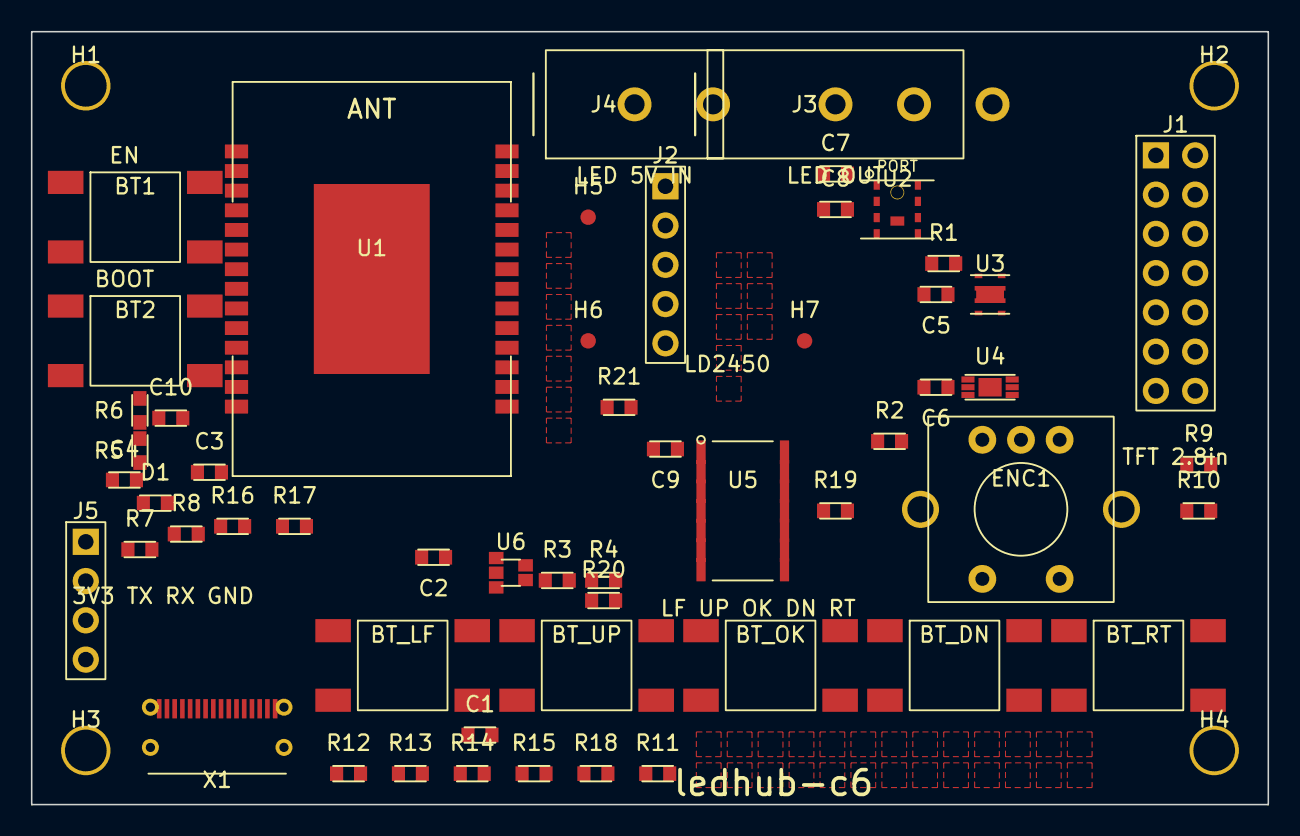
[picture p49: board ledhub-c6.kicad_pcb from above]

Board: 2 copper layers, 80.0 x 50.0 mm, 59 parts (0 on the bottom side), 37 nets, no tracks yet.

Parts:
BT1, BT2: SW_PUSH; Tactile-6x6-SMD
BT_DN: SW_PUSH; Tactile-6x6-SMD
BT_LF: SW_PUSH; Tactile-6x6-SMD
BT_OK: SW_PUSH; Tactile-6x6-SMD
BT_RT: SW_PUSH; Tactile-6x6-SMD
BT_UP: SW_PUSH; Tactile-6x6-SMD
C1, C2, C8: 10uF; C_0603_1608Metric
C3, C4, C5, C6, C7, C9, C10: 100nF; C_0603_1608Metric
D1: LED_RED; LED_0603_1608Metric
ENC1: EC11; EC11-Encoder
H1, H2, H3, H4: MountingHole_M2.5
H5, H6, H7: Fiducial; Fiducial_1mm
J1: Conn_02x07; PinHeader_2x07_P2.54mm_Vertical
J2: Conn_01x05; PinHeader_1x05_P2.54mm_Vertical
J3: Term_3P; KF128-5.08-3P
J4: Term_2P; KF128-5.08-2P
J5: Conn_01x04; PinHeader_1x04_P2.54mm_Vertical
R1, R2, R14: 4.7k; R_0603_1608Metric
R3, R4: 5.1k; R_0603_1608Metric
R5, R6: 22R; R_0603_1608Metric
R7, R10, R11, R15: 10k; R_0603_1608Metric
R8: 1k; R_0603_1608Metric
R9: 100R; R_0603_1608Metric
R12, R16, R17, R20, R21: 0R; R_0603_1608Metric
R13: 2.2k; R_0603_1608Metric
R18: 22k; R_0603_1608Metric
R19: 470R; R_0603_1608Metric
U1: ESP32-C6-WROOM-1
U2: INMP441; INMP441-LGA9
U3: SHT31; SHT31-DFN8
U4: BH1750; BH1750-WSOF6
U5: 74AHCT125; SOIC-14_3.9x8.7mm_P1.27mm
U6: AP2112K-3.3; SOT-23-5
X1: USB_C_16P; USB_C_Receptacle_USB2.0_16P

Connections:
+3V3: C2.1, C3.1, C5.1, C6.1, C7.1, C8.1, C10.1, J1.1, J5.1, R1.1, R2.1, R7.1, R8.1, R11.1, U1.2, U2.7, U2.8, U3.5, U4.1, U4.5, U6.5
+5V: C9.1, J2.1, R20.2, U5.4, U5.10, U5.13, U5.14
BTN_ADC: R11.2, R12.1, R13.1, R14.1, R15.1, R18.1, U1.8
B_OK: BT1.1, BT1.3, BT2.1, BT2.3, BT_DN.1, BT_DN.3, BT_LF.1, BT_LF.3, BT_OK.1, BT_OK.3, BT_RT.1, BT_RT.3, BT_UP.1, BT_UP.3, R18.2
EN: C4.1, R7.2, U1.3
ENC_A: ENC1.1, U1.23
ENC_B: ENC1.3, R16.1, U1.25
GND: BT1.2, BT1.4, BT2.2, BT2.4, BT_DN.2, BT_DN.4, BT_LF.2, BT_LF.4, BT_OK.2, BT_OK.4, BT_RT.2, BT_RT.4, BT_UP.2, BT_UP.4, C1.2, C2.2, C3.2, C4.2, C5.2, C6.2, C7.2, C8.2, C9.2, C10.2, D1.2, ENC1.2, J1.2, J2.4, J2.5, J3.3, J4.2, J5.4, R3.2, R4.2, R10.2, U1.1, U1.28, U1.29, U2.4, U2.5, U2.6, U2.9, U3.2, U3.8, U3.9, U4.2, U4.3, U4.7, U5.1, U5.5, U5.7, U5.9, U5.12, U6.2, X1.1, X1.8, X1.9, X1.16, X1.S1, X1.S2, X1.S3, X1.S4
I2C_SCL: R2.2, U1.19, U3.4, U4.6
I2C_SDA: R1.2, U1.18, U3.1, U4.4
I2S_SCK: R17.1, U1.24, U2.1
I2S_SD: U1.17, U2.2
I2S_WS: U1.16, U2.3
LED1_A: D1.1, R8.2
LED_5V: J3.1, J4.1
LED_DATA: J3.2, R19.2
LED_DIN: R21.1, U1.26
LED_DINB: R21.2, U5.2
LED_PRE: R19.1, U5.3
RAD_RX: J2.2, U1.20
RAD_TX: J2.3, U1.21
RX0: J5.3, R17.2
TFT_BL: R9.1, U1.27
TFT_BLP: J1.8, R9.2, R10.1
TFT_CS: J1.3, U1.5
TFT_DC: J1.5, U1.4
TFT_MOSI: J1.6, U1.7
TFT_RST: J1.4, U1.9
TFT_SCK: J1.7, U1.6
TX0: J5.2, R16.2
USB_CC1: R3.1, X1.3
USB_CC2: R4.1, X1.14
USB_DM: R6.2, U1.13
USB_DM_CON: R6.1, X1.5, X1.12
USB_DP: R5.2, U1.14
USB_DP_CON: R5.1, X1.4, X1.13
VBUS: C1.1, R20.1, U6.1, U6.3, X1.2, X1.7, X1.10, X1.15

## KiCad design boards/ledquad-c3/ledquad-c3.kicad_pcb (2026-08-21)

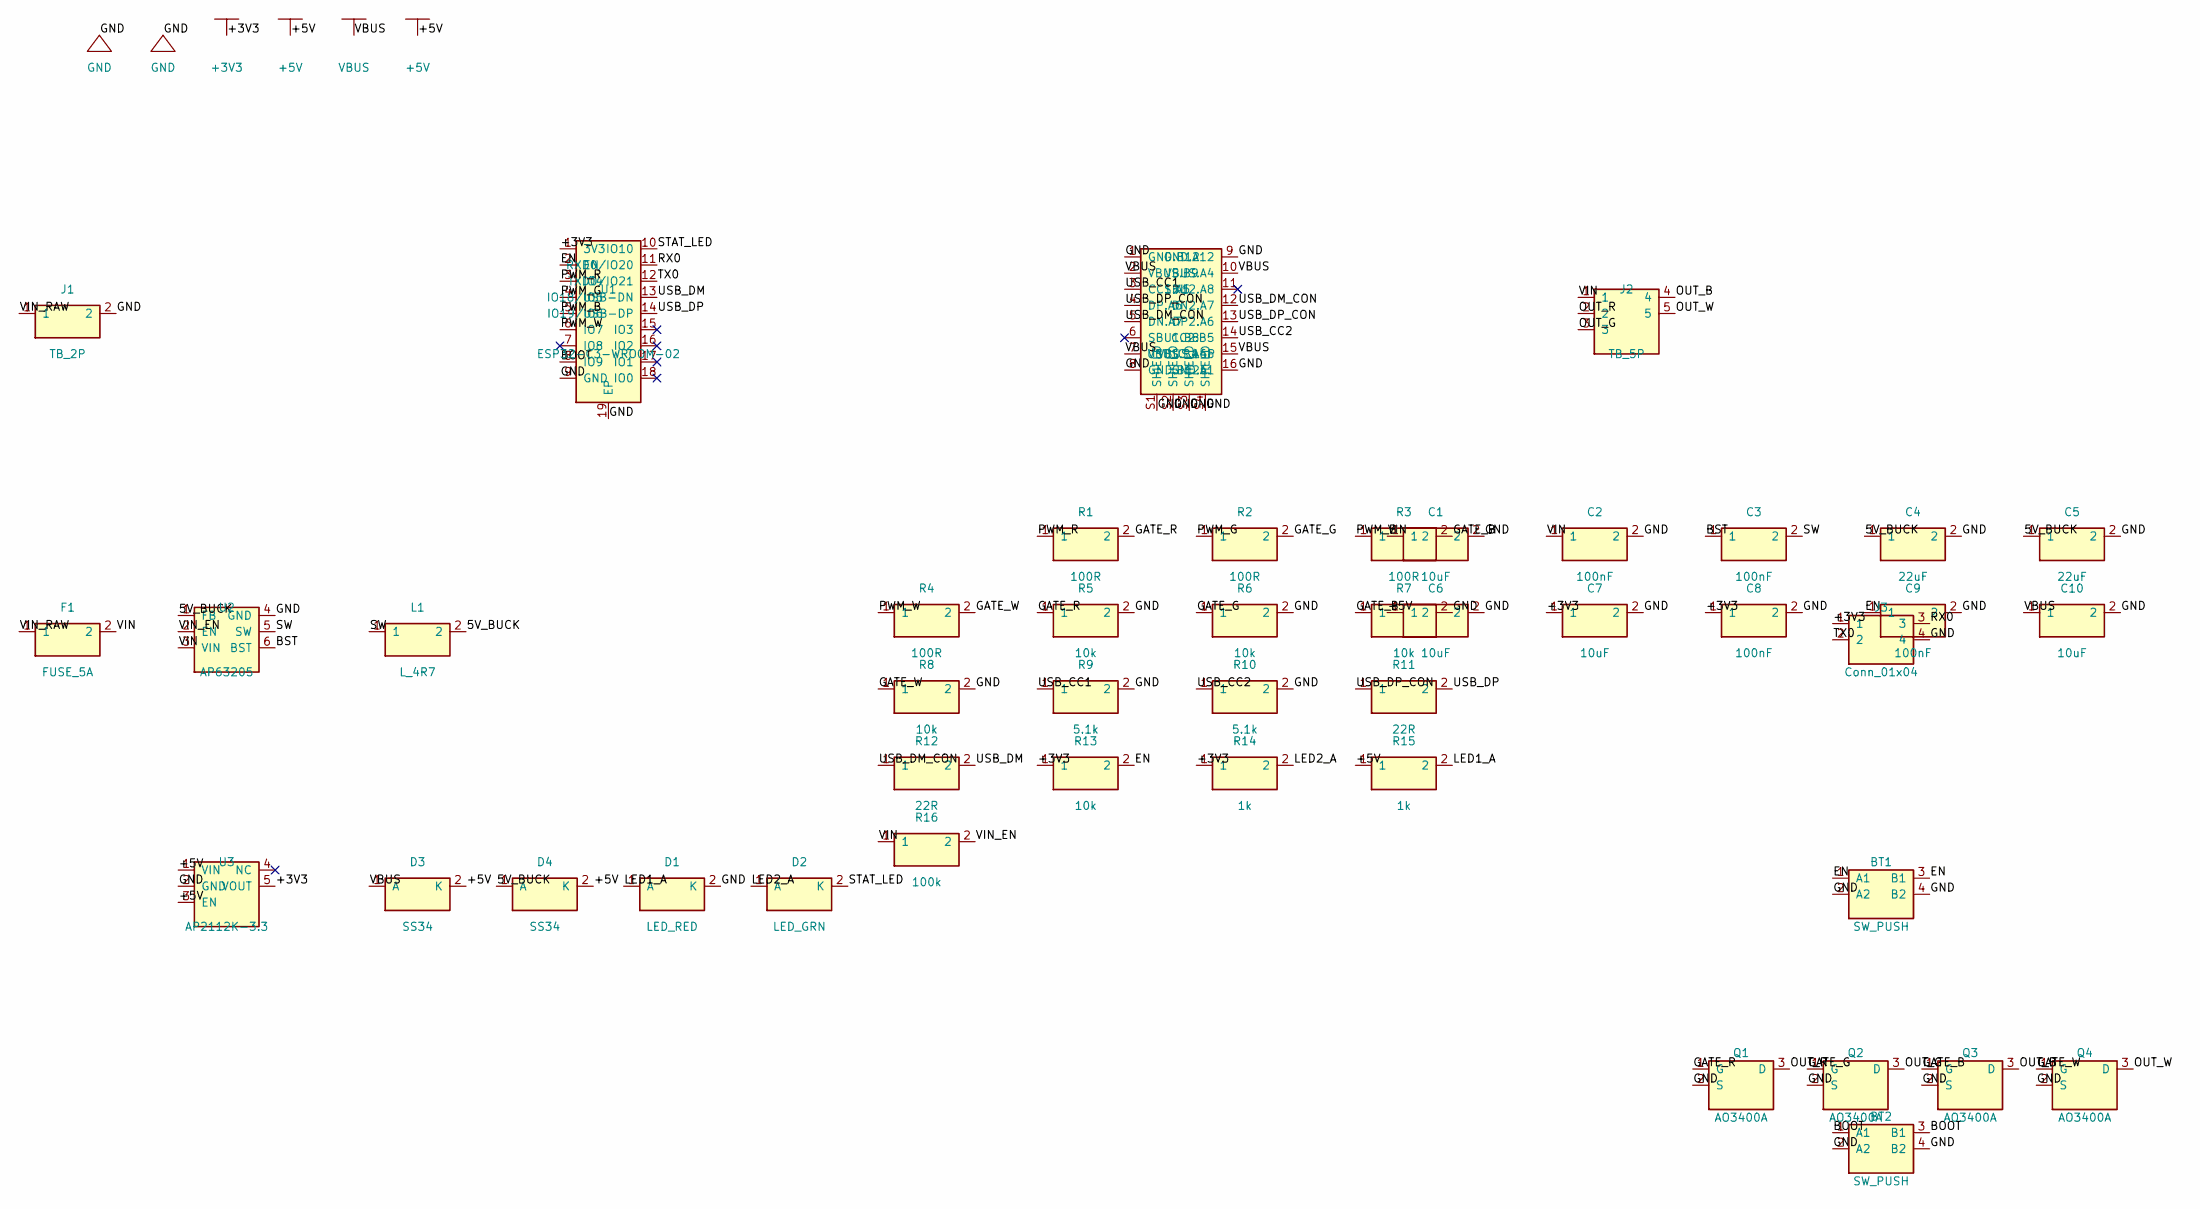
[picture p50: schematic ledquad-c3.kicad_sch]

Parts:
BT1, BT2: SW_PUSH; Tactile-6x6-SMD; LCSC C139797
C1, C6, C7, C10: 10uF; C_0603_1608Metric; LCSC C15849
C2, C3, C8, C9: 100nF; C_0603_1608Metric; LCSC C14663
C4, C5: 22uF; C_0805_2012Metric; LCSC C45783
D1: LED_RED; LED_0603_1608Metric; LCSC C2286
D2: LED_GRN; LED_0603_1608Metric; LCSC C2297
D3, D4: SS34; D_SMA; LCSC C8678
F1: FUSE_5A; Fuse_1206_3216Metric; LCSC C136351
J1: TB_2P; TB-5.08-2P; LCSC C474952
J2: TB_5P; TB-5.08-5P; LCSC C42377750
J3: Conn_01x04; PinHeader_1x04_P2.54mm_Vertical; LCSC C49258
L1: L_4R7; L-4x4-4R7; LCSC C167874
Q1, Q2, Q3, Q4: AO3400A; SOT-23; LCSC C20917
R1, R2, R3, R4: 100R; R_0603_1608Metric; LCSC C22369795
R5, R6, R7, R8, R13: 10k; R_0603_1608Metric; LCSC C25804
R9, R10: 5.1k; R_0603_1608Metric; LCSC C23186
R11, R12: 22R; R_0603_1608Metric; LCSC C22926
R14, R15: 1k; R_0603_1608Metric; LCSC C21190
R16: 100k; R_0603_1608Metric; LCSC C25803
U1: ESP32-C3-WROOM-02; LCSC C2934560
U2: AP63205; SOT-23-6; LCSC C2071056
U3: AP2112K-3.3; SOT-23-5; LCSC C51115
X1: USB_C_16P; USB_C_Receptacle_USB2.0_16P; LCSC C165948

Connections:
5V_BUCK: C4.1, C5.1, D4.1 (A), L1.2, U2.1 (FB)
+3V3: C7.1, C8.1, J3.1, R13.1, R14.1, U1.1 (3V3), U3.5 (VOUT)
+5V: C6.1, D3.2 (K), D4.2 (K), R15.1, U3.1 (VIN), U3.3 (EN)
BST: C3.1, U2.6 (BST)
GATE_B: Q3.1 (G), R3.2, R7.1
GATE_G: Q2.1 (G), R2.2, R6.1
GATE_R: Q1.1 (G), R1.2, R5.1
GATE_W: Q4.1 (G), R4.2, R8.1
GND: BT1.2 (A2), BT1.4 (B2), BT2.2 (A2), BT2.4 (B2), C1.2, C2.2, C4.2, C5.2, C6.2, C7.2, C8.2, C9.2, C10.2, D1.2 (K), J1.2, J3.4, Q1.2 (S), Q2.2 (S), Q3.2 (S), Q4.2 (S), R5.2, R6.2, R7.2, R8.2, R9.2, R10.2, U1.9 (GND), U1.19 (EP), U2.4 (GND), U3.2 (GND), X1.1 (GND.B12), X1.8 (GND.B12b), X1.9 (GND.A12), X1.16 (GND.A1), X1.S1 (SHIELD), X1.S2 (SHIELD), X1.S3 (SHIELD), X1.S4 (SHIELD)
LED1_A: D1.1 (A), R15.2
LED2_A: D2.1 (A), R14.2
OUT_B: J2.4, Q3.3 (D)
OUT_G: J2.3, Q2.3 (D)
OUT_R: J2.2, Q1.3 (D)
OUT_W: J2.5, Q4.3 (D)
PWM_B: R3.1, U1.5 (IO6)
PWM_G: R2.1, U1.4 (IO5)
PWM_R: R1.1, U1.3 (IO4)
PWM_W: R4.1, U1.6 (IO7)
RX0: J3.3, U1.11 (RXD0/IO20)
STAT_LED: D2.2 (K), U1.10 (IO10)
SW: C3.2, L1.1, U2.5 (SW)
TX0: J3.2, U1.12 (TXD0/IO21)
USB_CC1: R9.1, X1.3 (CC1.A5)
USB_CC2: R10.1, X1.14 (CC2.B5)
USB_DM: R12.2, U1.13 (IO18/USB-DN)
USB_DM_CON: R12.1, X1.5 (DN.A7), X1.12 (DN2.A7)
USB_DP: R11.2, U1.14 (IO19/USB-DP)
USB_DP_CON: R11.1, X1.4 (DP.A6), X1.13 (DP2.A6)
VBUS: C10.1, D3.1 (A), X1.2 (VBUS.B9), X1.7 (VBUS.B4), X1.10 (VBUS.A4), X1.15 (VBUS.A4b)
VIN: C1.1, C2.1, F1.2, J2.1, R16.1, U2.3 (VIN)
VIN_EN: R16.2, U2.2 (EN)
VIN_RAW: F1.1, J1.1

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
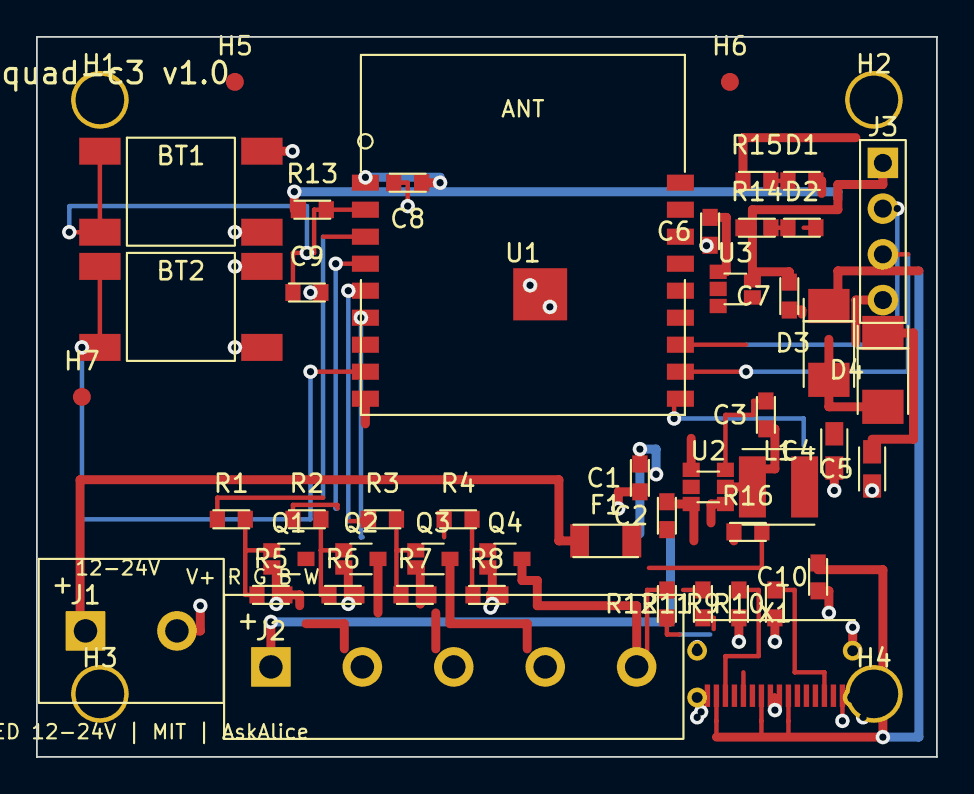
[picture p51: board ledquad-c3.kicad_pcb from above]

Board: 2 copper layers, 50.0 x 40.0 mm, 52 parts (0 on the bottom side), 35 nets.

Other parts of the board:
H1, H2, H3, H4: MountingHole_M2.5
H5, H6, H7: Fiducial; Fiducial_1mm

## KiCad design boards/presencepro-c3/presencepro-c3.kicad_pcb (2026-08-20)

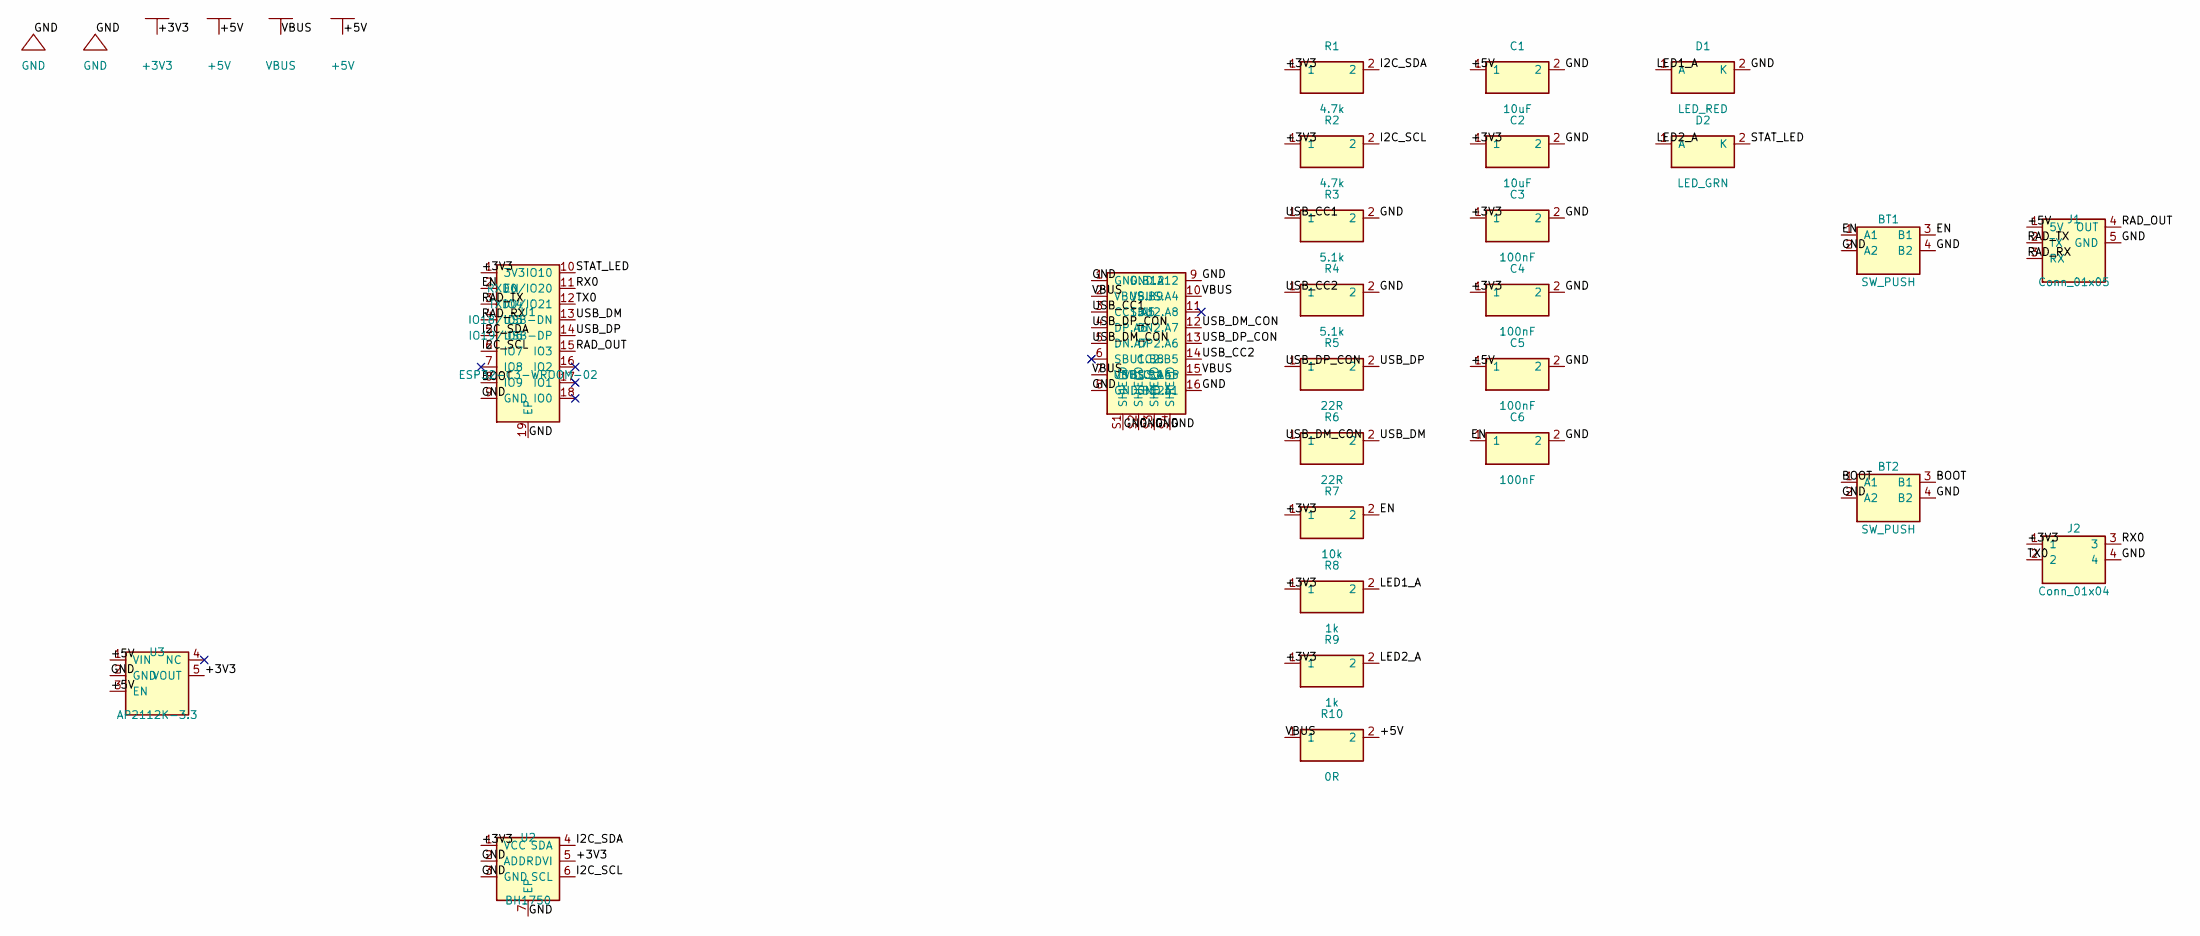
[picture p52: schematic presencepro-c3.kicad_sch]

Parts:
BT1, BT2: SW_PUSH; Tactile-6x6-SMD; MPN TS-1187A-B-A-B; LCSC C139797
C1, C2: 10uF; C_0603_1608Metric; MPN CL10A106KP8NNNC; LCSC C15849
C3, C4, C5, C6: 100nF; C_0603_1608Metric; MPN 0603B104K500NT; LCSC C14663
D1: LED_RED; LED_0603_1608Metric; MPN LTST-C190KRKT; LCSC C2286
D2: LED_GRN; LED_0603_1608Metric; MPN LTST-C190KGKT; LCSC C2297
J1: Conn_01x05; PinHeader_1x05_P2.54mm_Vertical; MPN PZ254V-11-05P; LCSC C492404
J2: Conn_01x04; PinHeader_1x04_P2.54mm_Vertical; MPN PZ254V-11-04P; LCSC C2691448
R1, R2: 4.7k; R_0603_1608Metric; MPN 0603WAF4701T5E; LCSC C23162
R3, R4: 5.1k; R_0603_1608Metric; MPN 0603WAF5101T5E; LCSC C23186
R5, R6: 22R; R_0603_1608Metric; MPN 0603WAF220JT5E; LCSC C22926
R7: 10k; R_0603_1608Metric; MPN 0603WAF1002T5E; LCSC C25804
R8, R9: 1k; R_0603_1608Metric; MPN 0603WAF1001T5E; LCSC C21190
R10: 0R; R_0603_1608Metric; MPN 0603WAF0000T5E; LCSC C21189
U1: ESP32-C3-WROOM-02; MPN ESP32-C3-WROOM-02-N4; LCSC C2934560
U2: BH1750; BH1750-WSOF6; MPN BH1750FVI-TR; LCSC C78960
U3: AP2112K-3.3; SOT-23-5; MPN AP2112K-3.3TRG1; LCSC C51118
X1: USB_C_16P; USB_C_Receptacle_USB2.0_16P; MPN TYPE-C-31-M-12; LCSC C165948

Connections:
+3V3: C2.1, C3.1, C4.1, J2.1, R1.1, R2.1, R7.1, R8.1, R9.1, U1.1 (3V3), U2.1 (VCC), U2.5 (DVI), U3.5 (VOUT)
+5V: C1.1, C5.1, J1.1 (5V), R10.2, U3.1 (VIN), U3.3 (EN)
GND: BT1.2 (A2), BT1.4 (B2), BT2.2 (A2), BT2.4 (B2), C1.2, C2.2, C3.2, C4.2, C5.2, C6.2, D1.2 (K), J1.5 (GND), J2.4, R3.2, R4.2, U1.9 (GND), U1.19 (EP), U2.2 (ADDR), U2.3 (GND), U2.7 (EP), U3.2 (GND), X1.1 (GND.B12), X1.8 (GND.B12b), X1.9 (GND.A12), X1.16 (GND.A1), X1.S1 (SHIELD), X1.S2 (SHIELD), X1.S3 (SHIELD), X1.S4 (SHIELD)
I2C_SCL: R2.2, U1.6 (IO7), U2.6 (SCL)
I2C_SDA: R1.2, U1.5 (IO6), U2.4 (SDA)
LED1_A: D1.1 (A), R8.2
LED2_A: D2.1 (A), R9.2
RAD_OUT: J1.4 (OUT), U1.15 (IO3)
RAD_RX: J1.3 (RX), U1.4 (IO5)
RAD_TX: J1.2 (TX), U1.3 (IO4)
RX0: J2.3, U1.11 (RXD0/IO20)
STAT_LED: D2.2 (K), U1.10 (IO10)
TX0: J2.2, U1.12 (TXD0/IO21)
USB_CC1: R3.1, X1.3 (CC1.A5)
USB_CC2: R4.1, X1.14 (CC2.B5)
USB_DM: R6.2, U1.13 (IO18/USB-DN)
USB_DM_CON: R6.1, X1.5 (DN.A7), X1.12 (DN2.A7)
USB_DP: R5.2, U1.14 (IO19/USB-DP)
USB_DP_CON: R5.1, X1.4 (DP.A6), X1.13 (DP2.A6)
VBUS: R10.1, X1.2 (VBUS.B9), X1.7 (VBUS.B4), X1.10 (VBUS.A4), X1.15 (VBUS.A4b)

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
Board: 2 copper layers, 33 parts (0 on the bottom side), 22 nets, no tracks yet.

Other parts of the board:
H1, H2, H3, H4: MountingHole_M2.5
H5, H6, H7: Fiducial; Fiducial_1mm

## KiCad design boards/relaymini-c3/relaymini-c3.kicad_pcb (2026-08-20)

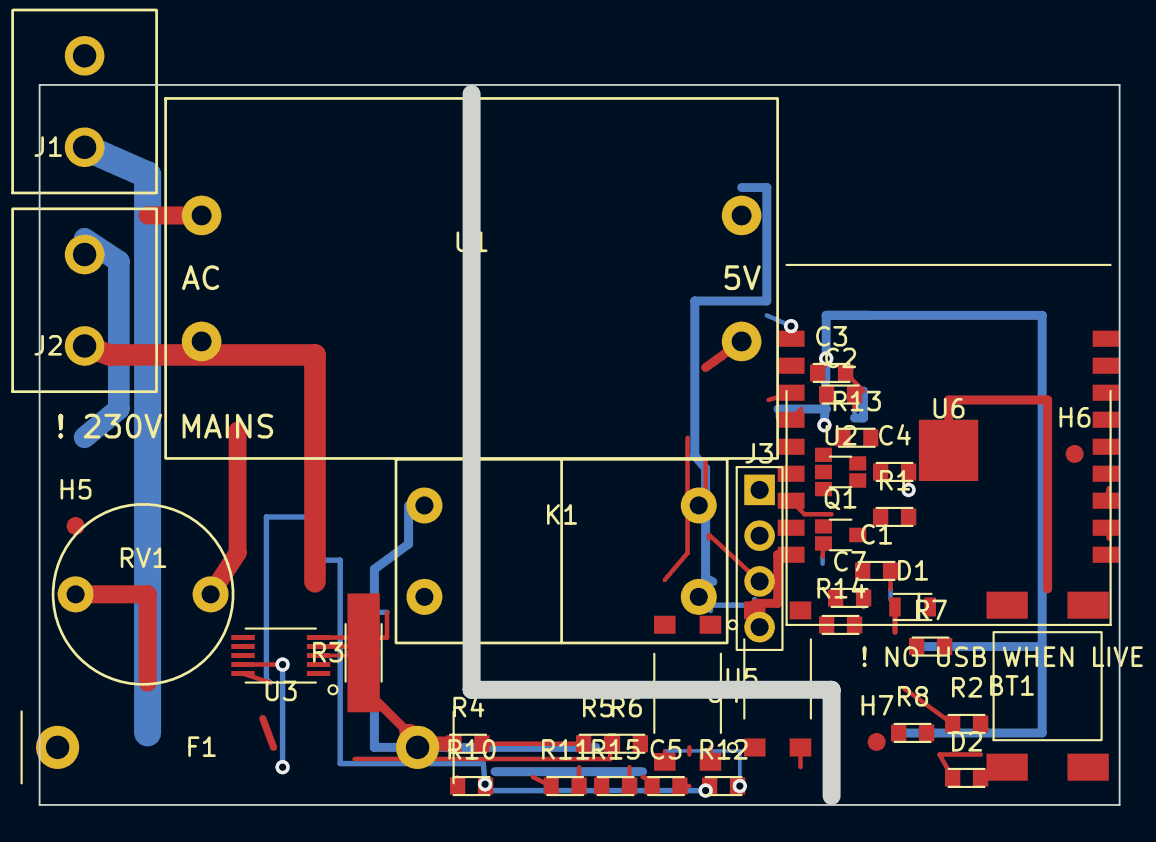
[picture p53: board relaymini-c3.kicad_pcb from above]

Board: 2 copper layers, 60.0 x 40.0 mm, 39 parts (0 on the bottom side), 24 nets.

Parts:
BT1: SW_PUSH; Tactile-6x6-SMD
C1, C3: 10uF; C_0603_1608Metric
C2, C4, C5, C7: 100nF; C_0603_1608Metric
D1: 1N4148WS; D_SOD-323
D2: LED_GRN; LED_0603_1608Metric
F1: FUSE_10A; FuseClip-5x20
H5, H6, H7: Fiducial; Fiducial_1mm
J1, J2: Term_5.08_2P; TerminalBlock-5.08-2P
J3: Conn_01x04; PinHeader_1x04_P2.54mm_Vertical
K1: HF32F-G
Q1: S8050; SOT-23
R1, R2, R12, R14: 1k; R_0603_1608Metric
R3: 1mR; Shunt-2512
R4, R5: 470k; R_0603_1608Metric
R6: 270R; R_0603_1608Metric
R7, R8, R10, R11, R13, R15: 10k; R_0603_1608Metric
RV1: MOV_10D471K; MOV-10D
U1: HLK-PM01
U2: AP2112K-3.3; SOT-23-5
U3: BL0942; BL0942-SSOP10
U4, U5: PC817; PC817-SOP4
U6: ESP32-C3-WROOM-02

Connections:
+3V3: C2.1, C3.1, C4.1, J3.1, R7.1, R8.1, R13.1, U2.5, U6.1
+5V: C1.1, D1.2, K1.3, U1.3, U2.1, U2.3
+5V_AC: C5.1, R10.1, R11.1, R15.1, U3.1
AC_L_F: F1.1, R3.2, R4.1, RV1.1, U1.1, U3.2
AC_L_SW: J1.1, J2.1, K1.2
AC_N: J1.2, J2.2, RV1.2, U1.2
BTN: BT1.1, BT1.3, R8.2, U6.8
COIL: D1.1, K1.4, Q1.3
EN: C7.1, R7.2, U6.2
GND: BT1.2, BT1.4, C1.2, C2.2, C3.2, C4.2, C7.2, D2.2, J3.4, Q1.2, U1.4, U2.2, U4.2, U5.2, U6.9, U6.19
GND_AC: C5.2, K1.1, R3.1, R6.2, U3.3, U3.5, U4.3, U5.3
LED_A: D2.1, R2.2
MTR_RX: R13.2, U6.3
MTR_RX_AC: R11.2, R15.2, U3.9, U4.4, U5.4
MTR_TX: R14.1, U6.4
MTR_TX_AC: R10.2, R12.1, U3.10
Q1B: Q1.1, R1.2
RELAY: R1.1, U6.5
RX0: J3.3, U6.11
STAT_LED: R2.1, U6.7
TX0: J3.2, U6.12
U5_A: R14.2, U4.1, U5.1
VD_A: R4.2, R5.1
VSENSE: R5.2, R6.1, U3.4

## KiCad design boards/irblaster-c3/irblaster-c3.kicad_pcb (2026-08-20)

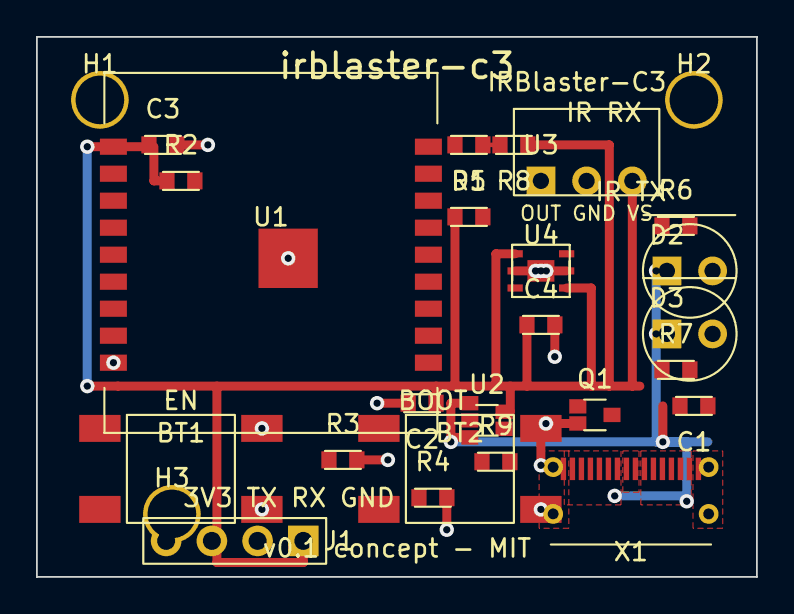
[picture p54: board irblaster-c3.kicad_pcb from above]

Board: 2 copper layers, 40.0 x 30.0 mm, 27 parts (0 on the bottom side), 20 nets.

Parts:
BT1, BT2: SW_PUSH; Tactile-6x6-SMD
C1, C2: 10uF; C_0603_1608Metric
C3, C4: 100nF; C_0603_1608Metric
D1: LED_GRN; LED_0603_1608Metric
D2, D3: TSAL6200; IR-LED-5mm
H1, H2, H3: MountingHole_M2.5
J1: Conn_01x04; PinHeader_1x04_P2.54mm_Vertical
Q1: S8050; SOT-23
R2: 10k; R_0603_1608Metric
R3, R4: 5.1k; R_0603_1608Metric
R5: 4.7k; R_0603_1608Metric
R6, R7: 47R; R_0603_1608Metric
R8: 1k; R_0603_1608Metric
R9: 100R; R_0603_1608Metric
U1: ESP32-C3-WROOM-02
U2: AP2112K-3.3; SOT-23-5
U3: TSOP38238
U4: BH1750; BH1750-WSOF6
X1: USB_C_16P; USB_C_Receptacle_USB2.0_16P

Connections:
+3V3: C2.1, C3.1, C4.1, J1.1, R2.1, R5.1, R8.1, U1.1, U2.5, U3.3, U4.1, U4.6
BOOT: BT1.1, BT1.3, BT2.1, BT2.3, U1.8
EN: R2.2, U1.2
GND: BT1.2, BT1.4, BT2.2, BT2.4, C1.2, C2.2, C3.2, C4.2, J1.4, Q1.2, R3.2, R4.2, U1.9, U1.19, U2.2, U3.2, U4.2, U4.5, U4.7, X1.1, X1.8, X1.9, X1.16, X1.S1, X1.S2, X1.S3, X1.S4
IR2_K: D2.2, D3.2, R7.1
IR_C: Q1.3, R6.2, R7.2
IR_DRV: Q1.1, R9.2
IR_RX: R5.2, U1.4, U3.1
IR_TX: R9.1, U1.3
LED1_A: D1.1, R8.2
RX0: J1.3, U1.11
SCL: U1.6, U4.3
SDA: U1.5, U4.4
STAT_LED: D1.2, U1.10
TX0: J1.2, U1.12
USB_CC1: R3.1, X1.3
USB_CC2: R4.1, X1.14
USB_DM: U1.13, X1.5, X1.12
USB_DP: U1.14, X1.4, X1.13
VBUS: C1.1, D2.1, D3.1, U2.1, U2.3, X1.2, X1.7, X1.10, X1.15

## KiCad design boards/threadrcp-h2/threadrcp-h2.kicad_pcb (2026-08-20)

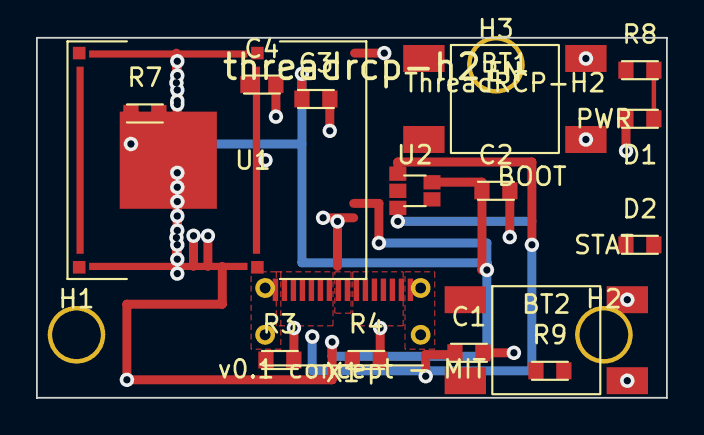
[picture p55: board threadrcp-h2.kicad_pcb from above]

Board: 2 copper layers, 35.0 x 20.0 mm, 19 parts (0 on the bottom side), 12 nets.

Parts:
BT1, BT2: SW_PUSH; Tactile-6x6-SMD
C1, C2: 10uF; C_0603_1608Metric
C3, C4: 100nF; C_0603_1608Metric
D1: LED_RED; LED_0603_1608Metric
D2: LED_GRN; LED_0603_1608Metric
H1, H2, H3: MountingHole_M2.5
R3, R4: 5.1k; R_0603_1608Metric
R7: 10k; R_0603_1608Metric
R8, R9: 1k; R_0603_1608Metric
U1: ESP32-H2-MINI-1
U2: AP2112K-3.3; SOT-23-5
X1: USB_C_16P; USB_C_Receptacle_USB2.0_16P

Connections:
+3V3: C2.1, C3.1, R7.1, R8.1, R9.1, U1.3, U1.15, U2.5
BOOT: BT1.1, BT1.3, BT2.1, BT2.3, U1.23
EN: C4.1, R7.2, U1.8
GND: BT1.2, BT1.4, BT2.2, BT2.4, C1.2, C2.2, C3.2, C4.2, D1.2, R3.2, R4.2, U1.1, U1.2, U1.11, U1.14, U1.36, U1.37, U1.38, U1.39, U1.40, U1.41, U1.42, U1.43, U1.44, U1.45, U1.46, U1.47, U1.48, U1.49, U1.50, U1.51, U1.52, U1.53, U2.2, X1.1, X1.8, X1.9, X1.16, X1.S1, X1.S2, X1.S3, X1.S4
LED1_A: D1.1, R8.2
LED2_A: D2.1, R9.2
STAT_LED: D2.2, U1.22
USB_CC1: R3.1, X1.3
USB_CC2: R4.1, X1.14
USB_DM: U1.26, X1.5, X1.12
USB_DP: U1.27, X1.4, X1.13
VBUS: C1.1, U2.1, U2.3, X1.2, X1.7, X1.10, X1.15

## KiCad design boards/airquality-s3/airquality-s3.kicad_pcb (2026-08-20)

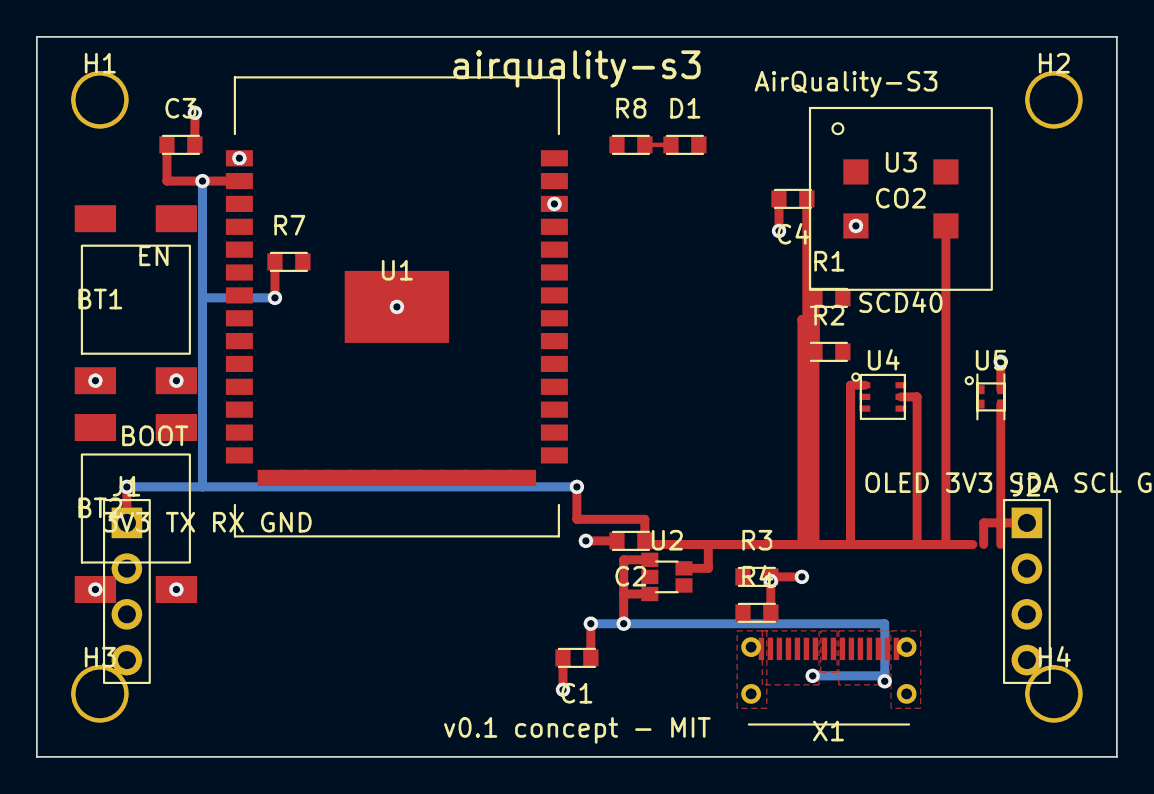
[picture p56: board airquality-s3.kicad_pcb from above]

Board: 2 copper layers, 60.0 x 40.0 mm, 25 parts (0 on the bottom side), 15 nets.

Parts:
BT1, BT2: SW_PUSH; Tactile-6x6-SMD
C1, C2: 10uF; C_0603_1608Metric
C3, C4: 100nF; C_0603_1608Metric
D1: LED_GRN; LED_0603_1608Metric
H1, H2, H3, H4: MountingHole_M2.5
J1, J2: Conn_01x04; PinHeader_1x04_P2.54mm_Vertical
R1, R2: 4.7k; R_0603_1608Metric
R3, R4: 5.1k; R_0603_1608Metric
R7: 10k; R_0603_1608Metric
R8: 1k; R_0603_1608Metric
U1: ESP32-S3-WROOM-1
U2: AP2112K-3.3; SOT-23-5
U3: SCD40
U4: SGP40; SGP40-DFN6
U5: SHT40; SHT40-DFN4
X1: USB_C_16P; USB_C_Receptacle_USB2.0_16P

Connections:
+3V3: C2.1, C3.1, C4.1, J1.1, J2.1, R1.1, R2.1, R7.1, R8.1, U1.2, U2.5, U3.3, U4.1, U4.5, U5.3
BOOT: BT1.1, BT1.3, BT2.1, BT2.3, U1.25
EN: R7.2, U1.3
GND: BT1.2, BT1.4, BT2.2, BT2.4, C1.2, C2.2, C3.2, C4.2, J1.4, J2.4, R3.2, R4.2, U1.1, U1.38, U1.41, U2.2, U3.2, U4.2, U4.4, U5.4, X1.1, X1.8, X1.9, X1.16, X1.S1, X1.S2, X1.S3, X1.S4
I2C_SCL: J2.3, R2.2, U1.15, U3.1, U4.6, U5.2
I2C_SDA: J2.2, R1.2, U1.12, U3.4, U4.3, U5.1
LED1_A: D1.1, R8.2
RX0: J1.3, U1.34
STAT_LED: D1.2, U1.29
TX0: J1.2, U1.35
USB_CC1: R3.1, X1.3
USB_CC2: R4.1, X1.14
USB_DM: U1.39, X1.5, X1.12
USB_DP: U1.40, X1.4, X1.13
VBUS: C1.1, U2.1, U2.3, X1.2, X1.7, X1.10, X1.15

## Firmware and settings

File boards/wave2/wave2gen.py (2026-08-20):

#!/usr/bin/env python3
"""wave2gen -- shared generator for the six wave-2 v0.1 concept boards.

Boards: threadnode-h2, airquality-s3, blinddriver-c6, irblaster-c3,
gardenprobe-c6, threadrcp-h2.  Each board is a compact spec using the
helpers here; the heavy lifting (symbols, schematic resolution, PCB
emission, geometric self-check, BOM) is shared.

Module footprints are built from the OFFICIAL Espressif KiCad library
pad coordinates (https://github.com/espressif/kicad-libraries ,
footprints/Espressif.pretty/*.kicad_mod, fetched 2025) and the Espressif
module datasheets:
  * ESP32-H2-MINI-1 : https://documentation.espressif.com/esp32-h2-mini-1_mini-1u_datasheet_en.html
                      (13.2 x 16.6 mm, 53 pads; antenna at pin-1 end)
  * ESP32-S3-WROOM-1: https://www.espressif.com/sites/default/files/documentation/esp32-s3-wroom-1_wroom-1u_datasheet_en.pdf
                      (18 x 25.5 mm, 40 pads + EP; antenna at pin-1 end)
  * ESP32-C6-WROOM-1: https://www.espressif.com/sites/default/files/documentation/esp32-c6-wroom-1_wroom-1u_datasheet_en.pdf
  * ESP32-C3-WROOM-02: https://www.espressif.com/sites/default/files/documentation/esp32-c3-wroom-02_datasheet_en.pdf
Sensirion sensor pinouts verified against the manufacturer datasheets:
  * SHT40 DFN-4 : 1=SDA 2=SCL 3=VDD 4=VSS  (sensirion.com/resource/datasheet/sht4x)
  * SGP40 DFN-6 : 1=VDD 2=VSS 3=SDA 4=NC(GND) 5=VDDH 6=SCL (sensirion.com/resource/datasheet/sgp40)
  * SCD40       : 1=SCL 2=GND 3=VDD 4=SDA  (Sensirion SCD4x datasheet)
Verify all custom footprints against the datasheets before fabrication.
"""
import math
import os
import sys

sys.path.insert(0, os.path.join(os.path.dirname(os.path.abspath(__file__)),
                                "..", "..", "tools"))
import kicadgen as kg  # noqa: E402

WAVE2 = os.path.dirname(os.path.abspath(__file__))
BOARDS_ROOT = os.path.dirname(WAVE2)

# ---------------------------------------------------------------------------
# LCSC part table (jlcsearch API, queried 2025; C-numbers + stock verified)
# value -> (footprint, lcsc, mpn, datasheet)
# ---------------------------------------------------------------------------
DS_ESPRESSIF = "https://github.com/espressif/kicad-libraries"
PARTS = {
    "ESP32-H2-MINI-1": ("custom:ESP32-H2-MINI-1", "—",
                        "ESP32-H2-MINI-1-N4",
                        "https://documentation.espressif.com/esp32-h2-mini-1_mini-1u_datasheet_en.html"),
    "ESP32-S3-WROOM-1": ("custom:ESP32-S3-WROOM-1", "C2913198",
                         "ESP32-S3-WROOM-1-N8",
                         "https://www.espressif.com/sites/default/files/documentation/esp32-s3-wroom-1_wroom-1u_datasheet_en.pdf"),
    "ESP32-C6-WROOM-1": ("custom:ESP32-C6-WROOM-1", "C5366877",
                         "ESP32-C6-WROOM-1-N8",
                         "https://www.espressif.com/sites/default/files/documentation/esp32-c6-wroom-1_wroom-1u_datasheet_en.pdf"),
    "ESP32-C3-WROOM-02": ("custom:ESP32-C3-WROOM-02", "C2934560",
                          "ESP32-C3-WROOM-02-N4",
                          "https://www.espressif.com/sites/default/files/documentation/esp32-c3-wroom-02_datasheet_en.pdf"),
    "USB_C_16P": ("Connector_USB:USB_C_Receptacle_USB2.0_16P", "C165948",
                  "TYPE-C-31-M-12",
                  "https://www.lcsc.com/datasheet/lcsc_datasheet_2410252104_Korean-Hroparts-Elec-TYPE-C-31-M-12_C165948.pdf"),
    "AP2112K-3.3": ("Package_TO_SOT_SMD:SOT-23-5", "C51115", "AP2112K-3.3TRG1",
                    "https://www.diodes.com/assets/Datasheets/AP2112.pdf"),
    "MCP1700-3302": ("Package_TO_SOT_SMD:SOT-23", "C39051", "MCP1700T-3302E/TT",
                     "https://ww1.microchip.com/downloads/aemDocuments/documents/APID/ProductDocuments/DataSheets/MCP1700-Data-Sheet-20001826F.pdf"),
    "AP63205": ("Package_TO_SOT_SMD:SOT-23-6", "C2071056", "AP63205WU-7",
                "https://www.diodes.com/assets/Datasheets/AP63200-AP63201-AP63203-AP63205.pdf"),
    "AO3401A": ("Package_TO_SOT_SMD:SOT-23", "C15127", "AO3401A",
                "https://www.lcsc.com/datasheet/lcsc_datasheet_1811151611_AOSMD-AO3401A_C15127.pdf"),
    "S8050": ("Package_TO_SOT_SMD:SOT-23", "C2146", "S8050 J3Y",
              "https://www.lcsc.com/datasheet/lcsc_datasheet_2304140030_JSCJ-S8050-J3Y_C2146.pdf"),
    "SS34": ("Diode_SMD:D_SMA", "C8678", "SS34",
             "https://www.lcsc.com/datasheet/lcsc_datasheet_2304140030_Guangdong-Hottech-SS34_C8678.pdf"),
    "SCD40": ("custom:SCD40", "C3659421", "SCD40-D-R2",
              "https://sensirion.com/resource/datasheet/scd40"),
    "SGP40": ("custom:SGP40-DFN6", "C2874215", "SGP40-D-R4",
              "https://sensirion.com/resource/datasheet/sgp40"),
    "SHT40": ("custom:SHT40-DFN4", "C2909890", "SHT40-AD1B-R2",
              "https://sensirion.com/resource/datasheet/sht4x"),
    "SHT31": ("custom:SHT31-DFN8", "C80862", "SHT31-DIS-B2.5kS",
              "https://www.sensirion.com/media/documents/213E6A3B/63A5A569/Datasheet_SHT3x_DIS.pdf"),
    "BH1750": ("custom:BH1750-WSOF6", "C78960", "BH1750FVI-TR",
               "https://www.mouser.com/datasheet/2/348/bh1750fvi-e-1868571.pdf"),
    "TMC2209": ("custom:TMC2209-socket", "C2150710", "TMC2209-LA-T",
                "https://www.analog.com/media/en/technical-documentation/data-sheets/tmc2209_datasheet_rev1.09.pdf"),
    "CR2032_HOLDER": ("custom:CR2032-holder", "C5239862", "BS-02-A1AJ010",
                      "https://www.lcsc.com/datasheet/lcsc_datasheet_2304140030_SHOU-HAN-BS-02-A1AJ010_C5239862.pdf"),
    "JST_PH_2": ("custom:JST-PH-2", "C131337", "B2B-PH-K-S(LF)(SN)",
                 "https://www.jst-mfg.com/product/pdf/eng/ePH.pdf"),
    "SOIL_PROBE": ("custom:SoilProbe-BCu", "—",
                   "copper electrodes on B.Cu (ENIG recommended)", "~"),
    "REED": ("custom:Reed-SMD", "C315909", "59170-1-S-00-D",
             "https://www.littelfuse.com/assetdocs/reed-sensor-59170-datasheet"),
    "TSOP38238": ("custom:TSOP38238", "C141632", "TSOP38238",
                  "https://www.vishay.com/docs/82491/tsop382.pdf"),
    "TSAL6200": ("custom:IR-LED-5mm", "C55528", "TSAL6200",
                 "https://www.vishay.com/docs/81010/tsal6200.pdf"),
    "100uF_35V": ("Capacitor_SMD:CP_Electrolytic_5x5.3", "C2836437",
                  "RVE100UF35V67RV0072",
                  "https://www.lcsc.com/datasheet/lcsc_datasheet_2304140030_ROQANG-RVE100UF35V67RV0072_C2836437.pdf"),
    "4.7uH": ("custom:IND-4040", "C167874", "FNR4030S4R7MT",
              "https://www.lcsc.com/datasheet/lcsc_datasheet_2304140030_cjiang-FNR4030S4R7MT_C167874.pdf"),
    # passives / misc (0603 basic parts)
    "10k": ("Resistor_SMD:R_0603_1608Metric", "C25804", "0603WAF1002T5E", "~"),
    "4.7k": ("Resistor_SMD:R_0603_1608Metric", "C23162", "0603WAF4701T5E", "~"),
    "5.1k": ("Resistor_SMD:R_0603_1608Metric", "C23186", "0603WAF5101T5E", "~"),
    "2.2k": ("Resistor_SMD:R_0603_1608Metric", "C2907005", "FRC0603F2201TS", "~"),
    "22R": ("Resistor_SMD:R_0603_1608Metric", "C22926", "0603WAF220JT5E", "~"),
    "47R": ("Resistor_SMD:R_0603_1608Metric", "C2907043", "FRC0603F47R0TS", "~"),
    "100R": ("Resistor_SMD:R_0603_1608Metric", "C22369795", "RCA03100RFLF", "~"),
    "100k": ("Resistor_SMD:R_0603_1608Metric", "C25803", "0603WAF1003T5E", "~"),
    "1M": ("Resistor_SMD:R_0603_1608Metric", "C269433", "RMC06031M5%N", "~"),
    "1k": ("Resistor_SMD:R_0603_1608Metric", "C21190", "0603WAF1001T5E", "~"),
    "100nF": ("Capacitor_SMD:C_0603_1608Metric", "C14663", "0603B104K500NT", "~"),
    "1uF": ("Capacitor_SMD:C_0603_1608Metric", "C52923", "0603B105K500NT", "~"),
    "10uF": ("Capacitor_SMD:C_0603_1608Metric", "C15849", "CL10A106KP8NNNC", "~"),
    "22uF": ("Capacitor_SMD:C_0805_2012Metric", "C45783", "CL21A226MAQNNNE", "~"),
    "LED_RED": ("LED_SMD:LED_0603_1608Metric", "C2286", "LTST-C190KRKT", "~"),
    "LED_GRN": ("LED_SMD:LED_0603_1608Metric", "C2297", "LTST-C190KGKT", "~"),
    "SW_PUSH": ("custom:Tactile-6x6-SMD", "C139797", "TS-1187A-B-A-B", "~"),
    "Conn_01x03": ("Connector_PinHeader_2.54mm:PinHeader_1x03_P2.54mm_Vertical",
                   "C49257", "KH-2.54PH180-1X3P-L13.5", "~"),
    "Conn_01x04": ("Connector_PinHeader_2.54mm:PinHeader_1x04_P2.54mm_Vertical",
                   "C49258", "KH-2.54PH180-1X4P-L13.5", "~"),
    "Conn_01x05": ("Connector_PinHeader_2.54mm:PinHeader_1x05_P2.54mm_Vertical",
                   "C492404", "PZ254V-11-05P", "~"),
    "Conn_01x08": ("Connector_PinHeader_2.54mm:PinHeader_1x08_P2.54mm_Vertical",
                   "C492407", "PZ254V-11-08P", "~"),
    "ScrewTerm_2P": ("custom:ScrewTerm-5.08-2P", "C8465", "WJ500V-5.08-2P", "~"),
    "ScrewTerm_3P": ("custom:ScrewTerm-5.08-3P", "C8465", "WJ500V-5.08-3P", "~"),
}


def fp_of(board, value_key):
    return PARTS[value_key][0].replace("custom:", board + ":")


# ---------------------------------------------------------------------------
# Module pin tables (pad number -> pin name), from the official Espressif
# kicad-libraries symbols (cited above).  Pads not listed are NC.
# ---------------------------------------------------------------------------
H2_MINI_PINS = {
    "1": "GND", "2": "GND", "3": "3V3", "5": "GPIO2", "6": "GPIO3",
    "8": "EN", "11": "GND", "12": "GPIO13", "13": "GPIO14", "14": "GND",
    "15": "VBAT", "16": "GPIO12", "18": "GPIO4", "19": "GPIO5",
    "20": "GPIO10", "21": "GPIO11", "22": "GPIO8", "23": "GPIO9",
    "26": "GPIO26/USB_D-", "27": "GPIO27/USB_D+", "30": "GPIO23/U0RXD",
    "31": "GPIO24/U0TXD",
    "36": "GND", "37": "GND", "38": "GND", "39": "GND", "40": "GND",
    "41": "GND", "42": "GND", "43": "GND", "44": "GND", "45": "GND",
    "46": "GND", "47": "GND", "48": "GND", "49": "EP/GND", "50": "GND",
    "51": "GND", "52": "GND", "53": "GND",
}
S3_WROOM_PINS = {
    "1": "GND", "2": "3V3", "3": "EN", "4": "IO4", "5": "IO5", "6": "IO6",
    "7": "IO7", "8": "IO15", "9": "IO16", "10": "IO17", "11": "IO18",
    "12": "IO8", "13": "IO3", "14": "IO46", "15": "IO9", "16": "IO10",
    "17": "IO11", "18": "IO12", "19": "IO13", "20": "IO14", "21": "IO21",
    "22": "IO47", "23": "IO48", "24": "IO45", "25": "IO0", "26": "IO35*",
    "27": "IO36*", "28": "IO37*", "29": "IO38", "30": "IO39", "31": "IO40",
    "32": "IO41", "33": "IO42", "34": "RXD0/IO44", "35": "TXD0/IO43",
    "36": "IO2", "37": "IO1", "38": "GND", "39": "IO19/USB_D-",
    "40": "IO20/USB_D+", "41": "EP/GND",
}
C6_WROOM_PINS = {
    "1": "GND", "2": "3V3", "3": "EN", "4": "IO4", "5": "IO5", "6": "IO6",
    "7": "IO7", "8": "IO0", "9": "IO1", "10": "IO8", "11": "IO10",
    "12": "IO11", "13": "IO12/USB_D-", "14": "IO13/USB_D+", "15": "IO9",
    "16": "IO18", "17": "IO19", "18": "IO20", "19": "IO21", "20": "IO22",
    "21": "IO23", "22": "NC", "23": "IO15", "24": "RXD0/IO17",
    "25": "TXD0/IO16", "26": "IO3", "27": "IO2", "28": "GND", "29": "EP/GND",
}
C3_WROOM_PINS = {
    "1": "3V3", "2": "EN", "3": "IO4", "4": "IO5", "5": "IO6", "6": "IO7",
    "7": "IO8", "8": "IO9", "9": "GND", "10": "IO10", "11": "RXD0/IO20",
    "12": "TXD0/IO21", "13": "IO18/USB_D-", "14": "IO19/USB_D+",
    "15": "IO3", "16": "IO2", "17": "IO1", "18": "IO0", "19": "EP/GND",
}


# ---------------------------------------------------------------------------
# Custom inline footprints
# ---------------------------------------------------------------------------
def make_footprints(lib):
    """Return {name: Footprint} for every custom footprint used by wave-2."""
    fps = {}

    def box_outline(fp, hw, hh, cr=0.5):
        fp.add_rect(-hw, -hh, hw, hh, "F.Fab", 0.1)
        fp.add_rect(-hw - cr, -hh - cr, hw + cr, hh + cr, "F.CrtYd", 0.05)
        fp.add_line(-hw, -hh, hw, -hh, "F.SilkS")
        fp.add_line(-hw, hh, hw, hh, "F.SilkS")
        fp.add_line(-hw, -hh, -hw, -hh + 2, "F.SilkS")
        fp.add_line(hw, -hh, hw, -hh + 2, "F.SilkS")
        fp.add_line(-hw, hh - 2, -hw, hh, "F.SilkS")
        fp.add_line(hw, hh - 2, hw, hh, "F.SilkS")

    # --- ESP32-H2-MINI-1 (official land pattern; see module docstring) -----
    fp = kg.Footprint(lib, "ESP32-H2-MINI-1")
    for i in range(11):        # left column pads 1..11, top -> bottom
        fp.add_pad(str(1 + i), "smd", "rect", -5.9, -1.3 + i * 0.8, 0.8, 0.4)
    for i in range(13):        # bottom row pads 12..24, left -> right
        fp.add_pad(str(12 + i), "smd", "rect", -4.8 + i * 0.8, 7.6, 0.4, 0.8)
    for i in range(11):        # right column pads 25..35, bottom -> top
        fp.add_pad(str(25 + i), "smd", "rect", 5.9, 6.7 - i * 0.8, 0.8, 0.4)
    for i in range(13):        # top row pads 36..48, right -> left
        fp.add_pad(str(36 + i), "smd", "rect", 4.8 - i * 0.8, -2.2, 0.4, 0.8)
    fp.add_pad("49", "smd", "rect", 0.0, 2.7, 5.4, 5.4)          # EP (grid)
    for num, x, y in (("50", 5.95, -2.25), ("51", 5.95, 7.65),
                      ("52", -5.95, 7.65), ("53", -5.95, -2.25)):
        fp.add_pad(num, "smd", "rect", x, y, 0.7, 0.7)
    fp.add_rect(-6.6, -8.3, 6.6, 8.3, "F.Fab", 0.1)
    fp.add_rect(-7.1, -8.8, 7.1, 8.8, "F.CrtYd", 0.05)
    fp.add_line(-6.6, 8.3, 6.6, 8.3, "F.SilkS")
    fp.add_line(-6.6, 8.3, -6.6, 5.0, "F.SilkS")
    fp.add_line(6.6, 8.3, 6.6, 5.0, "F.SilkS")
    fp.add_line(-6.6, -8.3, 6.6, -8.3, "F.SilkS")
    fp.add_line(-6.6, -8.3, -6.6, -3.5, "F.SilkS")
    fp.add_line(6.6, -8.3, 6.6, -3.5, "F.SilkS")
    fps["ESP32-H2-MINI-1"] = fp

    # --- ESP32-S3-WROOM-1 (official land pattern) --------------------------
    fp = kg.Footprint(lib, "ESP32-S3-WROOM-1")
    for i in range(14):        # left column 1..14, top -> bottom
        fp.add_pad(str(1 + i), "smd", "rect", -8.75, -8.26 + i * 1.27, 1.5, 0.9)
    for i in range(12):        # bottom row 15..26, left -> right
        fp.add_pad(str(15 + i), "smd", "rect", -6.985 + i * 1.27, 9.5, 1.5, 0.9)
    for i in range(14):        # right column 27..40, bottom -> top
        fp.add_pad(str(27 + i), "smd", "rect", 8.75, 8.25 - i * 1.27, 1.5, 0.9)
    fp.add_pad("41", "smd", "rect", 0.0, 0.0, 5.8, 4.0)          # EP (grid)
    fp.add_rect(-9.0, -12.75, 9.0, 12.75, "F.Fab", 0.1)
    fp.add_rect(-9.5, -13.25, 9.5, 13.25, "F.CrtYd", 0.05)
    fp.add_line(-9.0, -12.75, 9.0, -12.75, "F.SilkS")
    fp.add_line(-9.0, -12.75, -9.0, -9.6, "F.SilkS")
    fp.add_line(9.0, -12.75, 9.0, -9.6, "F.SilkS")
    fp.add_line(-9.0, 11.0, -9.0, 12.75, "F.SilkS")
    fp.add_line(9.0, 11.0, 9.0, 12.75, "F.SilkS")
    fp.add_line(-9.0, 12.75, 9.0, 12.75, "F.SilkS")
    fps["ESP32-S3-WROOM-1"] = fp

    # --- ESP32-C6-WROOM-1 (official land pattern) --------------------------
    fp = kg.Footprint(lib, "ESP32-C6-WROOM-1")
    for i in range(14):
        fp.add_pad(str(1 + i), "smd", "rect", -8.75, -8.26 + i * 1.27, 1.5, 0.9)
    for i in range(14):
        fp.add_pad(str(15 + i), "smd", "rect", 8.75, 8.25 - i * 1.27, 1.5, 0.9)
    fp.add_pad("29", "smd", "rect", 0.0, 0.0, 7.5, 12.3)         # EP (grid)
    fp.add_rect(-9.0, -12.75, 9.0, 12.75, "F.Fab", 0.1)
    fp.add_rect(-9.5, -13.25, 9.5, 13.25, "F.CrtYd", 0.05)
    fp.add_line(-9.0, -12.75, 9.0, -12.75, "F.SilkS")
    fp.add_line(-9.0, -12.75, -9.0, -9.6, "F.SilkS")
    fp.add_line(9.0, -12.75, 9.0, -9.6, "F.SilkS")
    fp.add_line(-9.0, 9.6, -9.0, 12.75, "F.SilkS")
    fp.add_line(9.0, 9.6, 9.0, 12.75, "F.SilkS")
    fp.add_line(-9.0, 12.75, 9.0, 12.75, "F.SilkS")
    fps["ESP32-C6-WROOM-1"] = fp

    # --- ESP32-C3-WROOM-02 (official land pattern; 18.5 x 20 mm body) ------
    fp = kg.Footprint(lib, "ESP32-C3-WROOM-02")
    for i in range(9):
        fp.add_pad(str(1 + i), "smd", "rect", -8.75, -5.9 + i * 1.5, 1.5, 0.9)
    for i in range(9):
        fp.add_pad(str(10 + i), "smd", "rect", 8.75, 6.1 - i * 1.5, 1.5, 0.9)
    fp.add_pad("19", "smd", "rect", 0.96, 0.3, 3.3, 3.3)         # EP (grid)
    fp.add_rect(-9.25, -10.0, 9.25, 10.0, "F.Fab", 0.1)
    fp.add_rect(-9.75, -10.5, 9.75, 10.5, "F.CrtYd", 0.05)
    fp.add_line(-9.25, -10.0, 9.25, -10.0, "F.SilkS")
    fp.add_line(-9.25, -10.0, -9.25, -7.2, "F.SilkS")
    fp.add_line(9.25, -10.0, 9.25, -7.2, "F.SilkS")
    fp.add_line(-9.25, 7.5, -9.25, 10.0, "F.SilkS")
    fp.add_line(9.25, 7.5, 9.25, 10.0, "F.SilkS")
    fp.add_line(-9.25, 10.0, 9.25, 10.0, "F.SilkS")
    fps["ESP32-C3-WROOM-02"] = fp

    # --- Tactile 6x6 SMD ----------------------------------------------------
    fp = kg.Footprint(lib, "Tactile-6x6-SMD")
    for num, x, y in (("1", -4.5, -2.25), ("2", 4.5, -2.25),
                      ("3", -4.5, 2.25), ("4", 4.5, 2.25)):
        fp.add_pad(num, "smd", "rect", x, y, 2.3, 1.5)
    fp.add_rect(-3.0, -3.0, 3.0, 3.0, "F.Fab", 0.1)
    fp.add_rect(-5.95, -3.15, 5.95, 3.15, "F.CrtYd", 0.05)
    fp.add_rect(-3.0, -3.0, 3.0, 3.0, "F.SilkS", 0.12)
    fps["Tactile-6x6-SMD"] = fp

    # --- SHT31 DFN-8 (as sensenode-c6) --------------------------------------
    fp = kg.Footprint(lib, "SHT31-DFN8")
    for i, y in enumerate((-1.2, -0.4, 0.4, 1.2)):
        fp.add_pad(str(i + 1), "smd", "rect", -1.05, y, 0.5, 0.3)
    for i, y in enumerate((1.2, 0.4, -0.4, -1.2)):
        fp.add_pad(str(8 - i), "smd", "rect", 1.05, y, 0.5, 0.3)
    fp.add_pad("9", "smd", "rect", 0.0, 0.0, 1.4, 1.0)
    box_outline(fp, 1.25, 1.25)
    fps["SHT31-DFN8"] = fp

    # --- BH1750 WSOF-6I (as sensenode-c6) ------------------------------------
    fp = kg.Footprint(lib, "BH1750-WSOF6")
    for i, y in enumerate((-0.95, 0.0, 0.95)):   # WSOF-6I: 0.95 mm pitch
        fp.add_pad(str(i + 1), "smd", "rect", -1.43, y, 0.85, 0.4)
    for i, y in enumerate((0.95, 0.0, -0.95)):
        fp.add_pad(str(6 - i), "smd", "rect", 1.43, y, 0.85, 0.4)
    fp.add_pad("7", "smd", "rect", 0.0, 0.0, 1.5, 1.2)
    box_outline(fp, 1.6, 1.45, 0.25)
    fps["BH1750-WSOF6"] = fp

    # --- SHT40 DFN-4 (1.5x1.5, pitch 0.8; 1=SDA 2=SCL 3=VDD 4=VSS) ---------
    fp = kg.Footprint(lib, "SHT40-DFN4")
    fp.add_pad("1", "smd", "rect", -0.55, -0.4, 0.4, 0.5)
    fp.add_pad("2", "smd", "rect", -0.55, 0.4, 0.4, 0.5)
    fp.add_pad("3", "smd", "rect", 0.55, 0.4, 0.4, 0.5)
    fp.add_pad("4", "smd", "rect", 0.55, -0.4, 0.4, 0.5)
    box_outline(fp, 0.75, 0.75, 0.3)
    fp.add_circle(-1.2, -0.9, 0.2, "F.SilkS")
    fps["SHT40-DFN4"] = fp

    # --- SGP40 DFN-6 (2.44x2.44; 1=VDD 2=VSS 3=SDA 4=NC 5=VDDH 6=SCL) -----
    fp = kg.Footprint(lib, "SGP40-DFN6")
    for i, y in enumerate((-0.65, 0.0, 0.65)):
        fp.add_pad(str(1 + i), "smd", "rect", -1.0, y, 0.6, 0.35)
    for i, y in enumerate((0.65, 0.0, -0.65)):
        fp.add_pad(str(6 - i), "smd", "rect", 1.0, y, 0.6, 0.35)
    box_outline(fp, 1.22, 1.22, 0.3)
    fp.add_circle(-1.5, -1.1, 0.2, "F.SilkS")
    fps["SGP40-DFN6"] = fp

    # --- SCD40 (10.1x10.1; 1=SCL 2=GND 3=VDD 4=SDA) — simplified pads -----
    fp = kg.Footprint(lib, "SCD40")
    for num, x, y in (("1", -2.5, -1.5), ("2", -2.5, 1.5),
                      ("3", 2.5, 1.5), ("4", 2.5, -1.5)):
        fp.add_pad(num, "smd", "rect", x, y, 1.4, 1.4)
    fp.add_rect(-5.05, -5.05, 5.05, 5.05, "F.Fab", 0.1)
    fp.add_rect(-5.6, -5.6, 5.6, 5.6, "F.CrtYd", 0.05)
    fp.add_rect(-5.05, -5.05, 5.05, 5.05, "F.SilkS", 0.12)
    fp.add_circle(-3.5, -3.9, 0.3, "F.SilkS")
    fp.add_text("CO2", 0, 0)
    fps["SCD40"] = fp

    # --- CR2032 SMD holder (BS-02 style; verify before fabrication) --------
    fp = kg.Footprint(lib, "CR2032-holder")
    fp.add_pad("1", "smd", "rect", -8.0, 0.0, 3.0, 3.5)   # BAT+ tab
    fp.add_pad("2", "smd", "rect", 8.0, 0.0, 3.0, 3.5)    # GND spring
    fp.add_circle(0, 0, 10.6, "F.SilkS")
    fp.add_circle(0, 0, 11.4, "F.CrtYd", 0.05)
    fp.add_circle(0, 0, 10.3, "F.Fab", 0.1)
    fp.add_text("CR2032", 0, 0)
    fp.add_text("+", -8.0, -3.2)
    fps["CR2032-holder"] = fp

    # --- JST-PH 2-pin top entry (B2B-PH-K-S), 2.0 mm pitch -----------------
    fp = kg.Footprint(lib, "JST-PH-2")
    fp.add_pad("1", "thru_hole", "rect", 0.0, 0.0, 1.5, 1.5,
               layers=("*.Cu", "*.Mask"), drill=0.75)
    fp.add_pad("2", "thru_hole", "circle", 2.0, 0.0, 1.5, 1.5,
               layers=("*.Cu", "*.Mask"), drill=0.75)
    fp.add_rect(-1.7, -2.4, 3.7, 2.0, "F.Fab", 0.1)
    fp.add_rect(-2.0, -2.7, 4.0, 2.3, "F.CrtYd", 0.05)
    fp.add_rect(-1.7, -2.4, 3.7, 2.0, "F.SilkS", 0.12)
    fp.add_text("+", -1.2, 1.0, size=0.8)
    fps["JST-PH-2"] = fp

    # --- 5.08 mm screw terminals --------------------------------------------
    for n in (2, 3):
        fp = kg.Footprint(lib, f"ScrewTerm-5.08-{n}P")
        for i in range(n):
            fp.add_pad(str(i + 1), "thru_hole",
                       "rect" if i == 0 else "circle", i * 5.08, 0.0,
                       2.4, 2.4, layers=("*.Cu", "*.Mask"), drill=1.3)
        fp.add_rect(-2.0, -3.8, (n - 1) * 5.08 + 2.0, 3.8, "F.Fab", 0.1)
        fp.add_rect(-2.3, -4.1, (n - 1) * 5.08 + 2.3, 4.1, "F.CrtYd", 0.05)
        fp.add_rect(-2.0, -3.8, (n - 1) * 5.08 + 2.0, 3.8, "F.SilkS", 0.12)
        fps[f"ScrewTerm-5.08-{n}P"] = fp

    # --- Reed switch SMD (Littelfuse 59170 style, ~7 mm body) --------------
    fp = kg.Footprint(lib, "Reed-SMD")
    fp.add_pad("1", "smd", "rect", -2.6, 0.0, 2.6, 1.4)
    fp.add_pad("2", "smd", "rect", 2.6, 0.0, 2.6, 1.4)
    box_outline(fp, 3.3, 1.0, 0.5)
    fps["Reed-SMD"] = fp

    # --- TSOP38238 IR receiver (THT, 2.54 pitch; 1=OUT 2=GND 3=VS) ---------
    fp = kg.Footprint(lib, "TSOP38238")
    for i in range(3):
        fp.add_pad(str(i + 1), "thru_hole",
                   "rect" if i == 0 else "circle", i * 2.54, 0.0, 1.6, 1.6,
                   layers=("*.Cu", "*.Mask"), drill=0.9)
    fp.add_rect(-1.5, -4.0, 6.58, 0.8, "F.Fab", 0.1)
    fp.add_rect(-1.8, -4.3, 6.88, 1.1, "F.CrtYd", 0.05)
    fp.add_rect(-1.5, -4.0, 6.58, 0.8, "F.SilkS", 0.12)
    fp.add_text("OUT GND VS", 2.54, 1.8, size=0.8)
    fps["TSOP38238"] = fp
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

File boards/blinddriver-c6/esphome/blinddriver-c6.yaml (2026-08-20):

# blinddriver-c6 — ESPHome configuration (SPEC 7.3)
# TMC2209 stepper roller-blind controller. ESP32-C6-WROOM-1 (Wi-Fi 6).
# USB-C native flashing (GPIO12/13 on J1 pads; TX0=GPIO16/RX0=GPIO17 spare).
# STEP=GPIO4, DIR=GPIO5, EN=GPIO6 (low=enable), DIAG=GPIO7,
# TMC2209 1-wire UART cfg on GPIO15, end-stop on GPIO18.

esphome:
  name: blinddriver-c6
  friendly_name: "BlindDriver C6"

esp32:
  board: esp32-c6-devkitc-1
  variant: esp32c6
  framework:
    type: esp-idf

logger:
api:
ota:
  - platform: esphome
wifi:
  ssid: !secret wifi_ssid
  password: !secret wifi_password

# ------------- TMC2209 control -------------
# NOTE: ESPHome has no built-in tmc2209 component as of 2025 — use the
# external "tmc2209" component (esphome external component) or drive via
# the plain stepper component below (TMC2209 defaults work: 1/8 microstep,
# StealthChop). UART config on GPIO15 is optional and unused here.
uart:
  id: tmc_uart
  tx_pin: GPIO15
  rx_pin: GPIO15       # 1-wire config: single wire to TMC2209 PDN_UART
  baud_rate: 115200

stepper:
  - platform: stepdir
    id: blind_stepper
    step_pin: GPIO4
    dir_pin: GPIO5
    max_speed: 1000 steps/s
    # ENDSTOP (GPIO18) -> home/open end-stop input below.

cover:
  - platform: time_based
    name: "Roller blind"
    open_action:
      - stepper.set_speed: {id: blind_stepper, speed: 500}
      # drive open: set direction/step count for your blind
    open_duration: 25s
    close_action:
      - stepper.set_speed: {id: blind_stepper, speed: 500}
    close_duration: 25s
    stop_action:
      - stepper.set_speed: {id: blind_stepper, speed: 0}
    has_built_in_endstop: false

# EN pin (GPIO6, low = driver enabled) — expose as a switch.
switch:
  - platform: gpio
    name: "Driver enable"
    pin:
      number: GPIO6
      inverted: true

binary_sensor:
  # DIAG (GPIO7) — driver diagnostic output
  - platform: gpio
    name: "TMC2209 DIAG"
    pin: GPIO7
  # End-stop header J8: 3V3/ENDSTOP/GND, GPIO18 (with pull-up)
  - platform: gpio
    name: "End-stop"
    pin:
      number: GPIO18
      inverted: true
    device_class: problem

# Status LED D1 (STAT_LED = GPIO1 via R8 1k)
light:
  - platform: status_led
    name: "Status"
    pin: GPIO1

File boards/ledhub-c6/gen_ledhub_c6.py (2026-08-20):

#!/usr/bin/env python3
"""ledhub-c6 -- programmatic KiCad 8 project generator.

80x50 mm 2-layer all-in-one display LED controller:
ESP32-C6-WROOM-1, 2.8" ILI9341 TFT (2x7 header), EC11 rotary encoder,
5-way ADC resistor-ladder nav buttons (GPIO0), INMP441 I2S mic,
SHT31 + BH1750 on I2C, LD2450 mmWave header, WS2812 output via
74AHCT125 level shifter, USB-C (native USB + power), AP2112 3V3,
separate LED_5V terminal rail.  WLED 0.15 is the primary firmware
target; ESPHome also possible (esphome/ledhub-c6.yaml).

Run:  python3 gen_ledhub_c6.py   (exits non-zero on any problem)

Footprint / part-number evidence:
  * ESP32-C6-WROOM-1: Espressif "ESP32-C6-WROOM-1 & WROOM-1U Datasheet"
    v1.4 (https://documentation.espressif.com/esp32-c6-wroom-1_wroom-1u_datasheet_en.html),
    section 10.1/11.1: module 18.0 x 25.5 x 3.1 mm, 28 pads @ 1.27 mm
    pitch, land pattern pads 1.5 x 0.9 mm (columns +/-8.75 mm), thermal
    pad 7.495 x 12.29 mm.  Footprint below matches those numbers.
  * SHT31: Sensirion datasheet, DFN-8 2.5 x 2.5 mm (real package -
    NOT the 3x3 variant).
  * INMP441: TDK/InvenSense DS-INMP441-00 rev 1.1: 9-terminal LGA_CAV
    4.72 x 3.76 x 1.0 mm, bottom sound port -> needs an 0.8 mm PCB
    hole; pads 0.40 x 0.60 mm, pinout 1=SCK 2=SD 3=WS 4=L/R 5/6/9=GND
    7=VDD 8=CHIPEN.  Hand-solder hostile - see README.
  * LCSC numbers picked via jlcsearch API (see bom_lcsc.csv).
"""
import math
import os
import sys

sys.path.insert(0, os.path.join(os.path.dirname(os.path.abspath(__file__)),
                                "..", "..", "tools"))
import kicadgen as kg  # noqa: E402

BOARD = "ledhub-c6"
W, H = 80.0, 50.0
OUT = os.path.dirname(os.path.abspath(__file__))

DS = {
    "ESP32-C6-WROOM-1": "https://documentation.espressif.com/esp32-c6-wroom-1_wroom-1u_datasheet_en.html",
    "USB_C_16P": "https://www.lcsc.com/datasheet/lcsc_datasheet_2410252104_Korean-Hroparts-Elec-TYPE-C-31-M-12_C165948.pdf",
    "AP2112K-3.3": "https://www.diodes.com/assets/Datasheets/AP2112.pdf",
    "SHT31": "https://www.sensirion.com/media/documents/213E6A3B/63A5A569/Datasheet_SHT3x_DIS.pdf",
    "BH1750": "https://www.mouser.com/datasheet/2/348/bh1750fvi-e-1868571.pdf",
    "INMP441": "https://invensense.tdk.com/wp-content/uploads/2015/02/INMP441.pdf",
    "74AHCT125": "https://www.diodes.com/assets/Datasheets/74AHCT125.pdf",
    "EC11": "https://www.lcsc.com/datasheet/lcsc_datasheet_2304140036_ALPSALPINE-EC11E15244G1_C370970.pdf",
}

# value -> (footprint, description, LCSC, MPN)
PART_INFO = {
    "ESP32-C6-WROOM-1": ("custom:ESP32-C6-WROOM-1",
                         "WiFi6/BLE/802.15.4 module", "C5366877",
                         "ESP32-C6-WROOM-1-N8"),
    "USB_C_16P": ("Connector_USB:USB_C_Receptacle_USB2.0_16P",
                  "USB-C 2.0 16P mid-mount receptacle", "C165948",
                  "TYPE-C-31-M-12"),
    "AP2112K-3.3": ("Package_TO_SOT_SMD:SOT-23-5", "LDO 3.3V 600mA",
                    "C51118", "AP2112K-3.3TRG1"),
    "SHT31": ("custom:SHT31-DFN8", "Humidity/temp sensor I2C", "C80862",
              "SHT31-DIS-B2.5kS"),
    "BH1750": ("custom:BH1750-WSOF6", "Ambient light sensor I2C", "C78960",
               "BH1750FVI-TR"),
    "INMP441": ("custom:INMP441-LGA9", "I2S MEMS mic, bottom port", "-",
                "INMP441ACEZ-R7"),       # NOT stocked at LCSC
    "74AHCT125": ("Package_SO:SOIC-14_3.9x8.7mm_P1.27mm",
                  "Quad buffer 5V level shifter", "C842299",
                  "74AHCT125S14-13"),
    "EC11": ("custom:EC11-Encoder", "Rotary encoder EC11 w/ switch",
             "C370970", "EC11E15244G1"),
    "SW_PUSH": ("custom:Tactile-6x6-SMD", "Tactile switch 6x6 SMD", "C318884",
                "TS-1187A-B-A-B"),
    "10k": ("Resistor_SMD:R_0603_1608Metric", "Resistor 10k 0603", "C25804",
            "0603WAF1002T5E"),
    "4.7k": ("Resistor_SMD:R_0603_1608Metric", "Resistor 4.7k 0603", "C23162",
             "0603WAF4701T5E"),
    "2.2k": ("Resistor_SMD:R_0603_1608Metric", "Resistor 2.2k 0603", "C4190",
             "0603WAF2201T5E"),
    "22k": ("Resistor_SMD:R_0603_1608Metric", "Resistor 22k 0603", "C31850",
            "0603WAF2202T5E"),
    "5.1k": ("Resistor_SMD:R_0603_1608Metric", "Resistor 5.1k 0603", "C23186",
             "0603WAF5101T5E"),
    "22R": ("Resistor_SMD:R_0603_1608Metric", "Resistor 22R 0603", "C22926",
            "0603WAF220JT5E"),
    "100R": ("Resistor_SMD:R_0603_1608Metric", "Resistor 100R 0603", "C22775",
             "0603WAF1000T5E"),
    "470R": ("Resistor_SMD:R_0603_1608Metric", "Resistor 470R 0603", "C23179",
             "0603WAF4700T5E"),
    "1k": ("Resistor_SMD:R_0603_1608Metric", "Resistor 1k 0603", "C21190",
           "0603WAF1001T5E"),
    "0R": ("Resistor_SMD:R_0603_1608Metric", "Resistor 0R 0603 link", "C21189",
           "0603WAF0000T5E"),
    "100nF": ("Capacitor_SMD:C_0603_1608Metric", "Cap MLCC 100nF 0603",
              "C14663", "0603B104K500NT"),
    "10uF": ("Capacitor_SMD:C_0603_1608Metric", "Cap MLCC 10uF 0603",
             "C15849", "CL10A106KP8NNNC"),
    "LED_RED": ("LED_SMD:LED_0603_1608Metric", "LED red 0603", "C2286",
                "LTST-C190KRKT"),
    "Conn_02x07": ("Connector_PinHeader_2.54mm:PinHeader_2x07_P2.54mm_Vertical",
                   "Header 2x7 (2.8in TFT)", "C492424", "PZ254V-12-14P"),
    "Conn_01x05": ("Connector_PinHeader_2.54mm:PinHeader_1x05_P2.54mm_Vertical",
                   "Header 1x5 (LD2450)", "C492404", "PZ254V-11-05P"),
    "Conn_01x04": ("Connector_PinHeader_2.54mm:PinHeader_1x04_P2.54mm_Vertical",
                   "Header 1x4 (prog)", "C2691448", "PZ254V-11-04P"),
    "Term_3P": ("custom:KF128-5.08-3P", "Screw terminal 5.08mm 3P (LED out)",
                "C474953", "KF128-5.08-3P-AA"),
    "Term_2P": ("custom:KF128-5.08-2P", "Screw terminal 5.08mm 2P (LED 5V in)",
                "C474952", "KF128-5.08-2P-AA"),
}
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

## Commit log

2026-08-16 test: binary push probe
2026-08-16 chore: remove binary push probe
2026-08-16 boards/gardenprobe-c6: corrected .kicad_pcb (3D model nesting fix)
    [gardenprobe-c6.kicad_pcb]
2026-08-20 feat: add sensenode-c6 design files (verified batch)
    [bom_lcsc.csv]
2026-08-20 feat: add wave-2 boards, tools, firmware (verified batch)
    [bom_lcsc.csv]
2026-08-20 feat: add threadnode-h2 analysis metadata
2026-08-20 sensenode-c6: add symbol library sensenode-c6-lib.kicad_sym
2026-08-20 feat: add threadnode and airquality support files
2026-08-20 feat: add wave-2 board generator wrappers
2026-08-20 feat: add blinddriver and irblaster configs
    [bom_lcsc.csv]
2026-08-20 feat: add gardenprobe and threadrcp metadata
    [bom_lcsc.csv]
2026-08-20 feat: add wave-2 board READMEs
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2026-08-20 presencepro-c3: add README, BOM, KiCad project/local settings, ESPHome config
    [bom_lcsc.csv]
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2026-08-20 feat: add shared KiCad generator library
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2026-08-20 feat: add boards/threadnode-h2/threadnode-h2.kicad_sch
    [threadnode-h2.kicad_sch]
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2026-08-20 presencepro-c3: add symbol library presencepro-c3-lib.kicad_sym
2026-08-20 feat: add boards/threadnode-h2/threadnode-h2.kicad_pcb
    [threadnode-h2.kicad_pcb]
2026-08-20 feat: add boards/gardenprobe-c6/gardenprobe-c6.kicad_pcb
    [gardenprobe-c6.kicad_pcb]
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2026-08-20 feat: add boards/blinddriver-c6/blinddriver-c6.kicad_pcb
    [blinddriver-c6.kicad_pcb]
2026-08-20 feat: add airquality KiCad project settings
2026-08-20 ledquad-c3: add README, BOM, kicad_prl, kicad_pro, esphome yaml
    [bom_lcsc.csv]
2026-08-20 feat: add blinddriver KiCad project settings
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2026-08-20 feat: add irblaster KiCad project settings
2026-08-20 remove stray probe file boards/ledquad-c3/.verify_ping
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2026-08-20 feat: add gardenprobe KiCad project settings
2026-08-20 remove stray probe file boards/ledquad-c3/.verify_ping (again)
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2026-08-20 feat: add threadrcp KiCad project settings
2026-08-20 ledquad-c3: add generator script gen_ledquad_c3.py
2026-08-20 relaymini-c3: add README, BOM, kicad_prl, kicad_pro, esphome yaml
    [bom_lcsc.csv]
2026-08-20 ledhub-c6: add README, BOM, kicad_prl, kicad_pro, esphome yaml
    [bom_lcsc.csv]
2026-08-20 relaymini-c3: add generator script gen_relaymini_c3.py
2026-08-20 feat: add boards/airquality-s3/airquality-s3.kicad_pcb
    [airquality-s3.kicad_pcb]
2026-08-20 feat: add threadrcp PCB layout
    [threadrcp-h2.kicad_pcb]
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2026-08-20 chore: remove incomplete threadrcp PCB transfer
    [threadrcp-h2.kicad_pcb]
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2026-08-20 feat: add boards/gardenprobe-c6/gardenprobe-c6.kicad_sch
    [gardenprobe-c6.kicad_sch]
2026-08-20 fix: restore full airquality-s3.kicad_pcb
    [airquality-s3.kicad_pcb]
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2026-08-20 feat: add boards/threadrcp-h2/threadrcp-h2.kicad_pcb
    [threadrcp-h2.kicad_pcb]
2026-08-20 feat: add boards/irblaster-c3/irblaster-c3.kicad_pcb
    [irblaster-c3.kicad_pcb]
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2026-08-20 feat: add boards/sensenode-c6/sensenode-c6.kicad_pcb
    [sensenode-c6.kicad_pcb]
2026-08-20 feat: add boards/sensenode-c6/sensenode-c6.kicad_sch
    [sensenode-c6.kicad_sch]
2026-08-20 feat: add boards/presencepro-c3/presencepro-c3.kicad_sch
    [presencepro-c3.kicad_sch]
2026-08-20 feat: add boards/blinddriver-c6/blinddriver-c6.kicad_sch
    [blinddriver-c6.kicad_sch]
2026-08-20 feat: add boards/airquality-s3/airquality-s3.kicad_sch
    [airquality-s3.kicad_sch]
2026-08-20 feat: add boards/relaymini-c3/relaymini-c3.kicad_sch
    [relaymini-c3.kicad_sch]
2026-08-20 feat: add boards/threadrcp-h2/threadrcp-h2.kicad_sch
    [threadrcp-h2.kicad_sch]
2026-08-20 feat: add boards/irblaster-c3/irblaster-c3.kicad_sch
    [irblaster-c3.kicad_sch]
2026-08-20 feat: add boards/relaymini-c3/relaymini-c3.kicad_pcb
    [relaymini-c3.kicad_pcb]
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2026-08-20 fix: restore boards/presencepro-c3/presencepro-c3-lib.kicad_sym
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2026-08-20 feat: add boards/presencepro-c3/presencepro-c3.kicad_pcb
    [presencepro-c3.kicad_pcb]
2026-08-21 Add ledhub-c6 KiCad schematic assembled from split parts (#5)
    * Initial plan
    * feat: add ledhub-c6 schematic assembled from parts
    ---------
    [ledhub-c6.kicad_sch]
2026-08-21 Add ledquad-c3 KiCad schematic assembled from staged parts (#6)
    * Add boards/ledquad-c3/ledquad-c3.kicad_sch assembled from import/parts
    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
    [ledquad-c3.kicad_sch]
2026-08-21 Add boards/ledquad-c3/ledquad-c3.kicad_pcb assembled from staged parts (#7)
    * Add boards/ledquad-c3/ledquad-c3.kicad_pcb assembled from parts
    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
    [ledquad-c3.kicad_pcb]
2026-08-21 Add assembled `ledhub-c6.kicad_pcb` from staged branch parts (#9)
    * Add assembled ledhub-c6 PCB file
    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
    [ledhub-c6.kicad_pcb]
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2026-08-22 revert: remove write-access probe file
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2026-08-22 revert: remove probe file
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2026-08-22 ci: add import-media workflow + manifest (downloads rendered images into repo, fixes 3D model visibility)
    [media-manifest.tsv]
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2026-08-27 docs: commit renders and point READMEs at repo-local files
    Signed URLs expire; GitHub can serve the PNGs/GIFs sitting next to each board.
    [media-manifest.tsv]
2026-09-25 2026-09-25 add GaragePilot C6 garage-door controller
    - New board: ESP32-C6-WROOM-1 + SRD-05VDC-SL-C dry relay + 3 inputs
    - 100 x 60 mm 2-layer PCB, autorouted, with local 3D models and renders
    - Adds 3dmodels/MANIFEST.md, bom_lcsc.csv, README.md, esphome config
    - Updates root README/CONCEPTS with GaragePilot C6
    - Tracks STEP/WRL assets with git-lfs
    [C_0603_1608Metric.step, D_SMA.step, ESP32-C6-WROOM-1.STEP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]
